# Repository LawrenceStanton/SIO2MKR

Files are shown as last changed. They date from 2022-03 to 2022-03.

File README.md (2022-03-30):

# SIO2MKR
Adjustable USB Powered Split Rail Power Supply for Breadboard Prototyping.

## Overview
This PCB design details a device to power an electronics breadboard for non-soldered prototyping. The project was commissioned by the University of Cape Town to allow students to work on electronics practicals from home. The device is powered off a standard 5V micro USB adapter, such as most cellphone adapters, and produces two independently adjustable positive and negatice supplies.

## Features
The device is controlled by:
1. A slide power switch.
2. 2 potentiometers for voltage adjustment.

The device has 1 input: 5V power from a suitable 5W USB power adapter.
The input is protected by a 3A Slow-Blow fuse, and is switched via a PMOS transistor controlled by the power switch.

The device has 4 outputs:
1. Adjustable Positive Voltage.
2. Adjustable Negative Voltage.
3. 5V USB Passthrough.
4. Non-isolated Ground.

The voltage is adjustable from ±1.2V to ±10.5V at a current rating of 40mA (at peak voltage output). Higher currents, up to 100mA, may be achieved at lower voltage. Current set resistors limit the power draw from the USB adapter to 1A, however if additional current is drawn from the USB passthrough is not accounted for. Ground is non-isolated, meaning it is the shared with the USB adapter.

## Contents
The repository has 4 sections:
1. FAB: Contains the PCB fabrication Gerber and drill files.
2. PCBA (JLCPCB SMT Assembly): Pick & Place and BOM files for automated assembly of components.
3. PCBA (No Variations): Same as above but including components not to be assembled by JLCPCB.
4. SRC: Altium Designer source files (can be imported to KiCAD).

## Manufacture
The device may be manufactured and assembled by JLCPCB. The cost per board comes to around $11.00 (10 units).

## Design Description
This design features 2 parallel power conversion circuits, one for the positive rail and one for the negative rail, with very similar operation. The power follows the following path:
USB -> Fuse -> Switch -> Switch Mode Boost Converter -> Linear Regulator
                      -> Switch Mode Inverter -> Linear Regulator
### Fuse
The fuse is a simple 3.0A slow-blow fuse. This is a secondary protection feature, since the Switch Mode Converter and Linear Regulator both have current limiting capability. Note issue #2 below.

### Switch
The switch is in fact a P-MOSFET controlled by slide switch. Note the ESD issue below.

### Switch Mode Converter
The Switch Mode Controller is the MC34063 regulator from ON Semi. Other pin-compatible devices are available from Diodes Inc. The device is a simple controller with an integrated darlington transistor and current sensing capability. Both the boosting and inverting supplies use this controller, and the same peripheral components due to the similar circuit characteristics of boosting and inverting switch mode supplies.

The inductor is rated at a high current value (0.95A) to improve efficiency. A large 400µF Tantalum Capacitor bank is supplied to stabilise the output, but may be increased without bound for improved performance.

The SS34 Schottky diodes are over specified but are generally quite cheap and this eliminates a commonly experienced failure mode. The positive supply features an inrush diode — which charges the capacitor bank to 5V immediately by bypassing the inductor. This should improve the startup performance of the positive supply, however this advantage is not possible with the inverting supply.

The timing capacitors set the switching frequency of the supply. These values are a bit dependent on biasing effects and should be measured in prototyping for exact specifications.

### Linear Regulator
The linear regulator is the universal LM317L and LM337L positive/negative regulator pair.

The linear regulators produce a much more stable output than the switch mode supply, necessary for analogue circuits. The devices are adjustable using the standard 1.25V reference feedback. A 2.7kΩ resistor in parallel with the 5kΩ potentiometer results in a roughly linear adjustment of the operational range of the switch mode supply.

### Tracking Pre-Regulator Feedback
The switch mode supply is configured as a tracking pre-regulator via the feedback network from the linear regulator’s output. The tracking voltage is set to 3V to adequately accommodate the dropout voltage of the LM317L and LM337L and to stiffen the regulator, while maintaining good power efficiency. The 5.6kΩ feedback resistors reduce the gain of the feedback, which should ensure stability, however this is still to be verified in testing.

### LED Indicators
3 LEDs are supplied to indicate USB power, the positive rail and the negative rail. The USB indicator is simple. To improve power efficiency, the split rail indicators are switched on 5V power by sensing the voltage across the 240Ω linear regulator's feedback resistor. This method relies on the gate threshold voltage of the sensing MOSFET, which is not absolutely certain to turn on fully but should be enough to fully turn on the 5V side MOSFET.

## Known Issues
### 1. Computer USB Power
The USB standard specifies that only 100mA may be drawn initially before power negotiation, and thereafter the device is only obliged to supply 500mA. This device does not communicate with its source at all. The power limit may be lowered by changing the 1206 current sense resistors (note under Features), however the initial surge is not yet tested. Powering the device from a PC USB port is therefore not advised, rather use a 5W or greater cellphone charger.
### 2. Fuse Rating
The fuse is rated at 3A, which is quite large. This is due to supply issues, and a 1.0A-2.0A rated fuse is more desirable. The part may be replaced with another 1206 Slow-Blow fuse.
### 3. Capacitor Discharge
Discharging the sizeable 800µF capacitor bank when switched off is not explicitly designed, however this is a low voltage bank and is not considered a safety risk.
### 4. ESD Protection
No ESD protection is provided. The most vulnerable component is the power PMOS transistor. Problems are to be tested with the initial prototype.
### 5. Tracking Pre-Regulator Stability
The tracking pre-regulator feedback network presents the possibility of destabilising the system. Although this can be simulated or otherwise modelled, the tolerances of the components are quite large and the exercise involved modelling the MC34063. Instead then, this will be stress tested during prototyping.

## Disclaimer
Please note the disclaimers detailed within the design files. The author assumes no liability in the use of this device, nor guarantees any of its function or availability.

© LD Stanton 2021-2022

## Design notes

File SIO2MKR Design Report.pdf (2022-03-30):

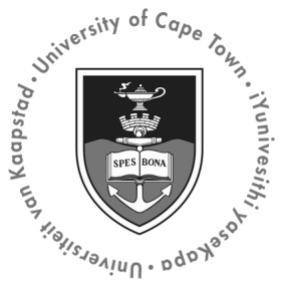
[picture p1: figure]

© LD Stanton 2022

University of Cape Town
Department of Electrical Engineering

Menzies Building, Upper Campus
Cape Town, South Africa
7701

## Design Report

July 2021 — Revised March 2022

LD Stanton
Postgraduate Student
STNLAW003@myuct.ac.za

# SIO2MKR USB Split Rail Power Supply

## Abstract

The SIO2MKR power supply regulates 5V USB power input into independently adjustable regulated split rail DC outputs. The design implements a tracking pre-regulator to maximise power output, while maintaining suitable ripple performance for low-speed analogue electronic loads. The design is intended for applications such as home analogue electronics with limited resources, low power demands, low user expertise, and low cost / high volume production.

This design was commissioned by the University of Cape Town and is made available publicly as Open Hardware under the CERN Open Hardware Licence v2 Permissive.

## Design Resources

Resource | Location
Open Hardware Repository | GitHub
Datasheet | Under Work
PCB Project | Altium 365
Schematic | Appendix A
Gerber Files | Altium 365
Fabrication Drawing | Appendix B
Assembly Drawing | Appendix C
Bill of Materials | Appendix D

## Features

- 5V USB Power Input

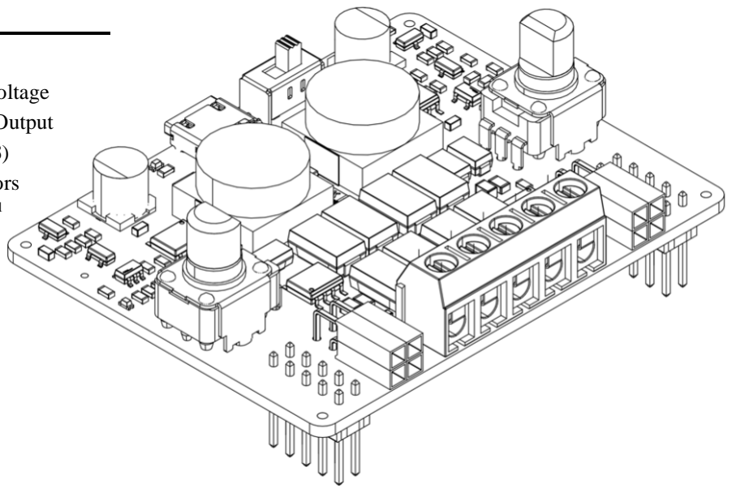
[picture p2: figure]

- Independently Adjustable Output Voltage
- ±1.25 to ±10.5V at 40mA (0.84W) Output
- Tracking Pre-Regulation (MC34063)
- LM317 and LM337 Linear Regulators
- 3 stage protection (2x ICs, 1x Fuse)¹
- Power Switch²

1 High Power 5V Output is only fuse protected.

## Applications

- General Purpose Electronics Prototyping
- School and University Programmes
- Hobby Electronics
- Electronics Development Programmes

## Additional Resources

Resource | Location
MC34063 Datasheet | ON Semiconductor
LM317 Datasheet | ON Semiconductor
LM337 Datasheet | Texas instruments
PCB Specifications | JLCPCB
Voltage Divider Script | Appendix E
CERN OHL v2 P | CERN, (https://ohwr.org/cern_ohl_p_v2.pdf) Appendix F

2 Switch controlled MOSFET.

System Description | 5.1 Inverting Regulator

## Table of Contents

1 SYSTEM DESCRIPTION --------------------------------------------------------------------------------------------------------------- 1

2 DESIGN SPECIFICATIONS------------------------------------------------------------------------------------------------------------ 1

3 FUNCTIONAL DIAGRAM ------------------------------------------------------------------------------------------------------------- 2

4 COMPONENT SELECTION CRITERIA ---------------------------------------------------------------------------------------------- 3

5 DESIGN CALCULATIONS------------------------------------------------------------------------------------------------------------- 4

6 TEST RESULTS -----------------------------------------------------------------------------------------------------------------------22

APPENDIX A — SCHEMATIC ----------------------------------------------------------------------------------------------------------------I

APPENDIX D — BILL OF MATERIALS --------------------------------------------------------------------------------------------------- II

APPENDIX E — E12 VOLTAGE DIVIDER SCRIPT ------------------------------------------------------------------------------------ IV

APPENDIX F — CERN OHL V2 PERMISSIVE LICENCE ---------------------------------------------------------------------------- VI

5.1 Inverting Regulator | System Description
Page 2 | LD Stanton

## List of Figures

FIGURE 1:FUNCTIONAL DIAGRAM | 2
FIGURE 2:FORCED GAIN CONDITIONS | 10
FIGURE 3: LINEAR REGULATOR SCALING RESISTOR VALUE SELECTION | 14
FIGURE 4: LMV321 CLAW | 15
FIGURE 6:POSITIVE SIDE VOLTAGE TRACKING | 25
FIGURE 7: NEGATIVE SIDE VOLTAGE TRACKING | 25
FIGURE 8: ADJUSTABLE CURRENT LOAD | 26
FIGURE 9:POSITIVE SIDE STEP UP TRANSIENT RESPONSE | 27
FIGURE 10: NEGATIVE SIDE STEP UP TRANSIENT RESPONSE | 28
FIGURE 11:POSITIVE SIDE STEP DOWN TRANSIENT RESPONSE | 28
FIGURE 12: NEGATIVE SIDE STEP DOWN TRANSIENT RESPONSE | 29

## List of Tables

TABLE 1: DUT INFORMATION | 22
TABLE 2: TEST EQUIPMENT | 22
TABLE 3:SUPPLEMENTAL INFORMATION | 29

## List of Circuits

CIRCUIT 1: INVERTING REGULATOR | 4
CIRCUIT 2: BOOSTING REGULATOR | 7
CIRCUIT 3: DARLINGTON FORCED GAIN CIRCUIT | 9
CIRCUIT 4: TRACKING FEEDBACK CIRCUIT | 11
CIRCUIT 5: LINEAR REGULATOR FEEDBACK NETWORK | 13
CIRCUIT 6: LMV321FUNCTIONAL CIRCUIT DIAGRAM | 16
CIRCUIT 7: NEGATIVE RAIL LED INDICATOR HYSTERESIS CIRCUIT | 17
CIRCUIT 8:POSITIVE RAIL LED INDICATOR HYSTERESIS CIRCUIT | 19

System Description

SIO2MKR Design Report | Page 1

## 1 System Description

This design implements a parallel boosting and inverting switching regulator, both utilising the MC34063 — a ubiquitous, low cost and robust power converter. Each switched output is then passed through the LM317 (positive) and LM337 (negative) adjustable linear regulators to eliminate switching noise. The regulators are adjusted using two potentiometers, compensated for linearity over the range of operation. A feedback network implements 3V tracking pre-regulation between the switched and linearly regulated outputs, similar to many “hybrid” DC bench power supplies. In conjunction with a generous 400μF tantalum capacitor bank (per rail); this configuration results in an output voltage ripple suitable for most low-speed analogue electronics projects and experiments.

## 2 Design Specifications

Symbol | Name | Value
| | Minimum | Typical | Maximum
VI | DC Input Voltage | 4.6V | 5.0V | 5.5V
PI | Input Power | 5W
VO | Output Voltage Range (Each Rail) | ±1.2V | | ±10V5
IO | Rated Output Current (Rail to Rail) | | | 40mA
IO_PP | Rated Output Current (Positive Rail to Ground) | | | 60mA
IO_PP | Rated Output Current (Ground to Negative Rail) | | | 40mA
VR | Ripple Voltage (Switching Regulator) | | | 50mVpp
VTRACK | Pre-regulator Tracking Voltage | | 3.0V
VSR_PP | Boosting Regulator Output Range | VI | | 13V75
VSR_NN | Inverting Regulator Output Range | 0V | | -13V75
fSR | Switching Frequency | 24kHz | 33kHz | 42kHz
IL_pk | Peak Switching Current (Per Regulator) | | 0A44
VLED_ON | LED Indicator ON Threshold | | ±5V
VLED_OFF | LED Indicator OFF Threshold | | ±1V5
IFUSE_USB | Input Non-resettable Fuse Rated Current | | 3A
IFUSE_PTC | Output PTC Fuse Rated Current | | 460mA

## 3 Functional Diagram

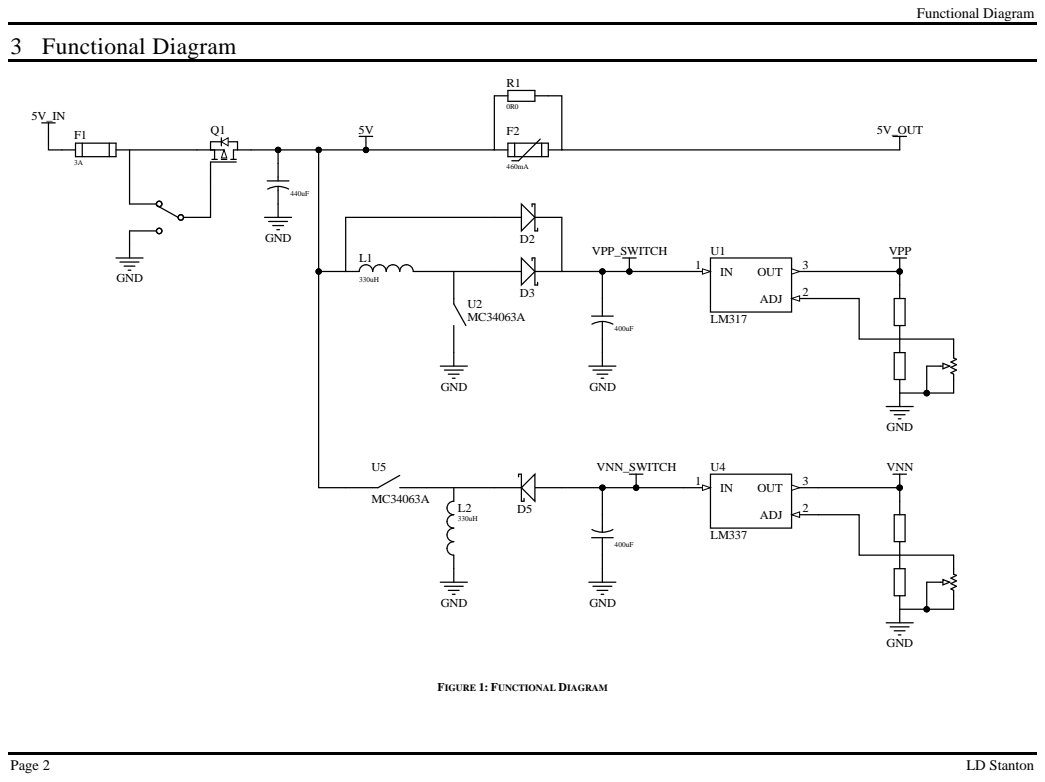
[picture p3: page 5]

Component Selection Criteria

SIO2MKR Design Report | Page 3

## 4 Component Selection Criteria

The selection process for each component is not detailed, however in general the following criteria were applied in decreasing order of priority:

1. Any directly-applicable, fixed specifications.
2. Available via JLCPCB SMT Assembly (limited subrange LCSC.com)
3. Active Part, Stock & Availability (150 Units Minimum at time of selection)³
4. Basic Part (JLCPCB SMT Assembly designation)
5. Performance & Features
6. Component Package
7. Cost (100 to 1000 units)
8. Component-specific comparisons, RoHS, manufacturer & other terminal criteria.

3 Due to the 2021 global chip shortage, this criterion was significantly increased in priority than normal.

5.1 Inverting Regulator | Design Calculations

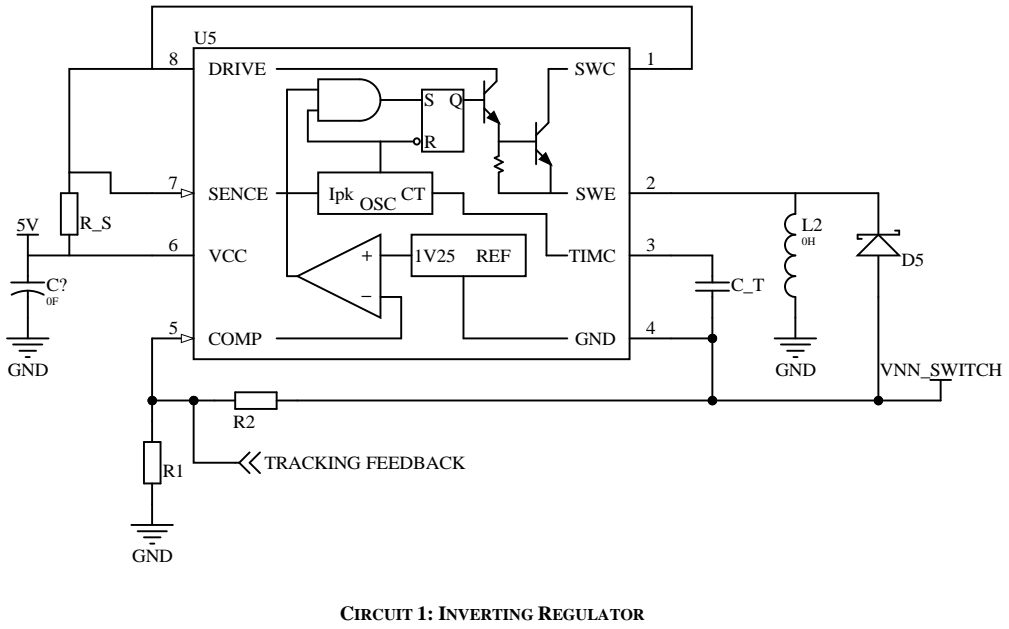
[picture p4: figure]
CIRCUIT 1: INVERTING REGULATOR; SWC; SWE; TIMC; GND; COMP 5; VCC 6; SENCE 7; DRIVE 8; OSC Ipk; REF; TRACKING FEEDBACK; VNN_SWITCH

Page 4 | LD Stanton

## 5 Design Calculations

Where an equation or symbol is quoted without reference to the visible circuitry, the source is to be assumed to be the datasheet of the relevant component.

## 5.1 Inverting Regulator

## 5.1.1 Feedback Voltage Divider

Note: this voltage divider effectively limits the maximum output, given no feedback from the tracking feedback path. Additionally, the common node of the MC34063 is referenced to the negative output rail. The 1V25 reference voltage is therefore situated as 1V25 above VNN, NOT 1V25 below GND.

Let VO_MAX = -14V

VO = VFB

R1 + R2
R1
- VFB = -1V25

From the above, the script in Appendix E resolved the following values:

- R1 = 5K6
- R2 = 56K

Rated VO_MAX = -13V75.

Design Calculations | 5.1 Inverting Regulator
SIO2MKR Design Report | Page 5

## 5.1.2 Switching Times

T = ton + toff =

1
f

,

ton

toff

=

|VO| + VF

Vin − Vsat

, ton =

T

1 +

1
ton/toff
- VO = 13V75
- VF_MAX = 0V55 (SS34 SBR)
- Vsat = (1V0 ; 1V3) — Darlington
- Vin = (4V6 ; 5V25) — USB Specification
- f = (24 ; 42) kHz — Typical Range

Due to the switch being above the inductor, a Darlington configuration was necessary.

Therefore:

- | TMAX = 41.7μs | TMIN = 23.8μs
- (ton/toff)MAX = 4.33
- (ton/toff)MIN = 3.24
- tON_MAX = 33.9μs
- tON_MIN = 18.2μs

## 5.1.3 Overcurrent Protection

ILpk =

Vtℎ
Rs
- Vth = 0V3

The inductor will be selected with overspecification on current handling to improve conduction losses. Therefore, the inductor rated current is not a consideration here.

The power supply is rated as a minimum of 5W = 5V × 1A. Neglecting all small loads, and assuming the worst-case scenario of both the inverter and booster switching on simultaneously at peak current, each regulator is permitted 1A/2 = 0.5A peak current. Therefore, set 0.5A as the current limit.

Given a more powerful input, this current limit can be increased by modifying RS within the rated limits of the inductor and MC34063, which will increase the output current capability.

∴ Rs =

0V3
0A5

= 0R6 ≈ 0R68

ILpk =

0V3
0R68 = 0A44

## 5.1.4 Output Current

IOMAX =

Ipk
2 ((
ton
toff)

MAX

+ 1)

=

0A44
2(4.33 + 1)

= 41mA

Therefore rate IORATED = 40mA

5.1 Inverting Regulator | Design Calculations
Page 6 | LD Stanton

## 5.1.5 Inductor Value

LMIN =

VinMIN − VsatMIN

ILpk

tonMAX =

4V6 − 1V0
0A44 33.9μs = 277μH ≈ 330μH

Note: Inductance value options are fairly limited on JLC.

Select: SWRB1207S-33MT

- L = 330μH
- IR = 0A95

Current handling capability was over specified to reduce inductor resistance, within a reasonable footprint size. Height was unlimited.

## 5.1.6 Output Capacitance

CO =

9IOMAXtonMAX

Vripplepp

Specify Vripple = 50mVpp

∴ COMIN =

9 × 46.6mA × 32.9μs
50mV | = 276μF ≈ 3 × 100μF

1 additional capacitor was later added given available board area.

Select: 293D107X9016D2TE3

- Tantalum Electrolytic
- 100μF
- 16V

Tantalum capacitors were selected for their superior performance at higher voltage operation than MLCCs (DC bias effect), the fixed polarity of the rails, the required capacitance, and the available board area. 16V was sufficient assuming nominal operation of the MC36063 feedback divider with 2V headroom for overshoot.

## 5.1.7 Timing Capacitor

CT = 4.0 × 10⁻⁵Fs

−1 × tonMAX = 4.0 × 10⁻⁵Fs

| −1 × 32.9μs = 1.32nF ≈ 1nF

Rate at 16V (same as output capacitor).

This is not a critical component in value.

## 5.1.8 Input Capacitor

Assign 2x220μF AlEl Capacitors at 10V.

This is not a critical value in capacitance.

Although placing this component after the current sensing resistor may improve the maximum power capability of the device, this may result in triggering an overcurrent event on startup. Therefore, place these capacitors before the current sense resistor.

Design Calculations | 5.2 Boosting Regulator

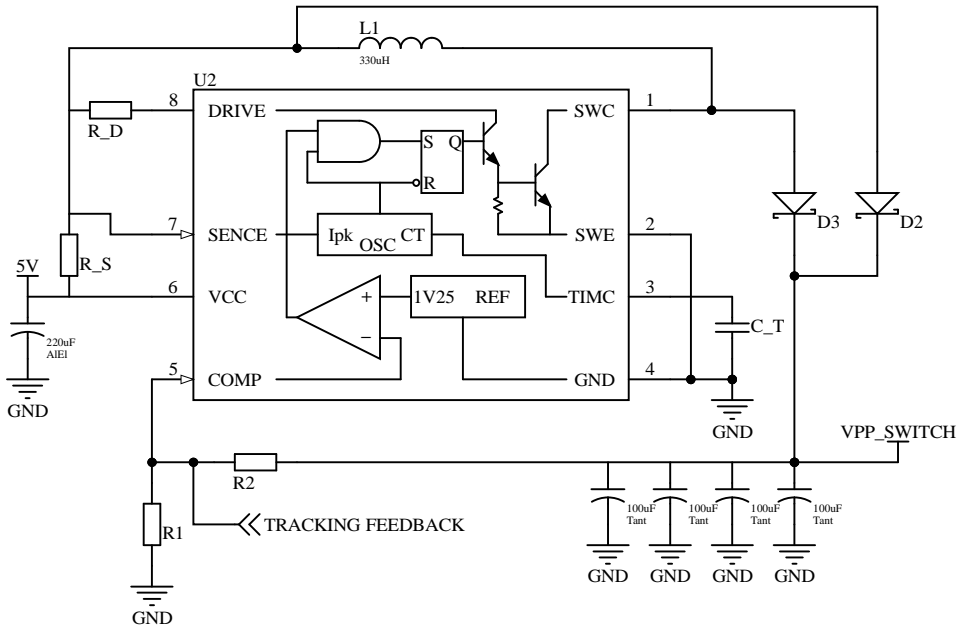
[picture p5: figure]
SWC; SWE; TIMC; GND; COMP 5; VCC 6; SENCE 7; DRIVE 8; OSC Ipk; REF; TRACKING FEEDBACK; VPP_SWITCH; 100uF Tant; 220uF AlEl

SIO2MKR Design Report | Page 7

## 5.2 Boosting Regulator

Much of this design is identical to the inverting regulator. For brevity, where the same design equation applied to both the inverting and boosting regulator, the result achieved in the inverter is simply replicated upon the booster.

CIRCUIT 2: BOOSTING REGULATOR

## 5.2.1 Feedback Voltage Divider

This circuit matches exactly the same feedback reference voltage to the same (inverted) maximum output. However, the reference is 1V25 above ground, not 1V25 below the output rail. Therefore, the values are swapped in position.

- R1 = 56K
- R2 = 5K6

## 5.2.2 Switching Times

T = tON + tOFF =

1
f

,

ton

toff

=

VO + VF − VINMIN

VINMIN − VsatMAX

,ton =

T

1 +

1
ton/toff
- VO = 13V75
- VF = 0V55 (SS34)
- Vsat = (0V45; 0V7) (Non-Darlington Configuration)
- f = (24; 42)kHz

ton

toff

=

13V75 + 0V55 − 4V6
4V6 − 0V7

= 2.48

tonMAX =

TMAX

1 +

1
(

tON
tOFF

)

=

1
24kHz (1 +

1
2.48)

= 29.7μs

5.2 Boosting Regulator | Design Calculations
Page 8 | LD Stanton

tonMIN =

TMIN

1 +

1
(

tON
tOFF

)

=

1
24kHz (1 +

1
2.48)

= 17.0μs

## 5.2.3 Overcurrent Protection

Same as Inverter:

- RS = 0R68
- Ipk = 0A44

## 5.2.4 Output Current

IOMAX =

Ipk
2(

tON
tOFF

+1)

=

0A44
2(2.48+1)

=63mA

Since it is plausible that current sourced from VPP will also need to be sunk by VNN, rate both supplies at the more constrained rating of VNN, 40mA. However, for single supply operation, rate:

IOPPRATED

= 60mA

## 5.2.5 Inductor Value

LMIN =

VINMIN − VsatMIN

Ipk

tONMAX =

4V6 − 0V4
0A44 29.7μs = 283μH < 330μH

Therefore, in the interest of parts management, select the same inductor as the inverter.

## 5.2.6 Output Capacitance

These characteristics are identical to that of the inductor, and therefore the same bank of 4x100μF capacitors were used, spare for changing the polarity of the connection.

## 5.2.7 Timing Capacitor

CT = 1nF (Same as inverter)

Design Calculations | 5.2 Boosting Regulator

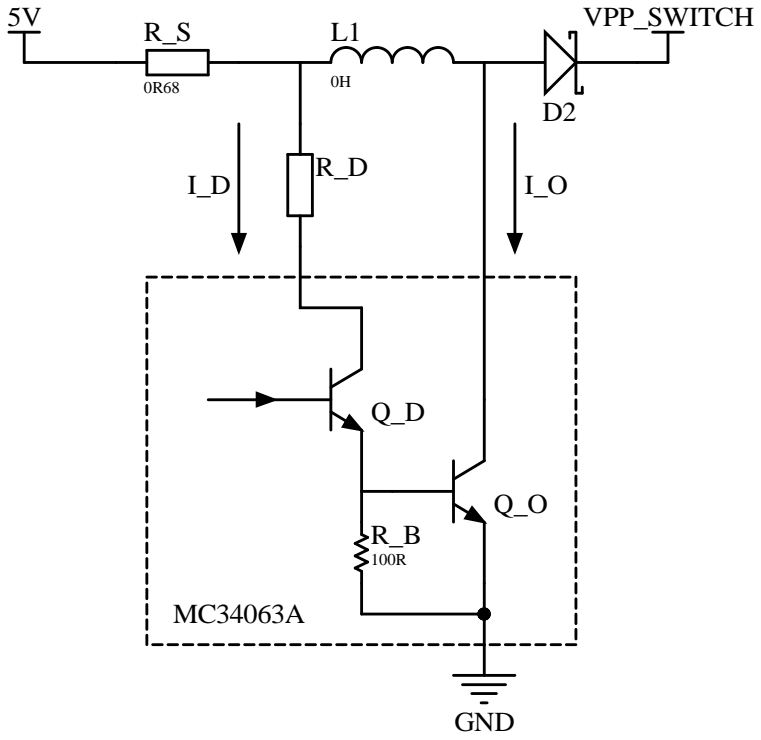
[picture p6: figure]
GND; VPP_SWITCH

SIO2MKR Design Report | Page 9

## 5.2.8 Forced Gain

It is recommended that:

ICOTP
ICDRIVER − 7mA ≥ 10

This is interpreted as the power transistor within the Darlington transistor should not be forced to a gain less than 10. This specifically refers to the turn-off transition, where excessive overdrive will delay turn-off, thereby increasing the tOFF time with an initial low collector current (<300mA), which is problematic at higher switching frequencies (>30kHz).

From the circuit diagram the following derivation follows:

CIRCUIT 3: DARLINGTON FORCED GAIN CIRCUIT

ICD =

VCC − VS − VCEOsat

− VBEO
RD

=

VCC − (ICO + ICD

)RS − VCEOsat
− 7mA × RB
RD

(ICO + ICD

)RS + RDICD + RB7mA = VCC − VCEOsat

ICO

RS + ICD

(RD + RS

) + 7mARB = VCC − VCEOsat

ICO

RS + (ICD − 7mA )(RD + RS
) + 7mA(RD + RS

) + 7mARB = VCC − VCEOsat

ICO

RS + (ICD − 7mA )(RD + RS
) + 7mA(RB + RD + RS

) = VCC − VCEOsat

By rearrangement, the gain condition is revealed, and the limitation applied:

ICO
ICD − 7mA =

1
RS

(
VCC − VCEOsat
ICD − 7mA − (RD + RS

) −

7mA
IO

(RB + RD + RS

)) ≥ 10

In the gain condition, the approximation IED = ICD + IBD ≈ ICD is implicit.

B

5.2 Boosting Regulator | Design Calculations

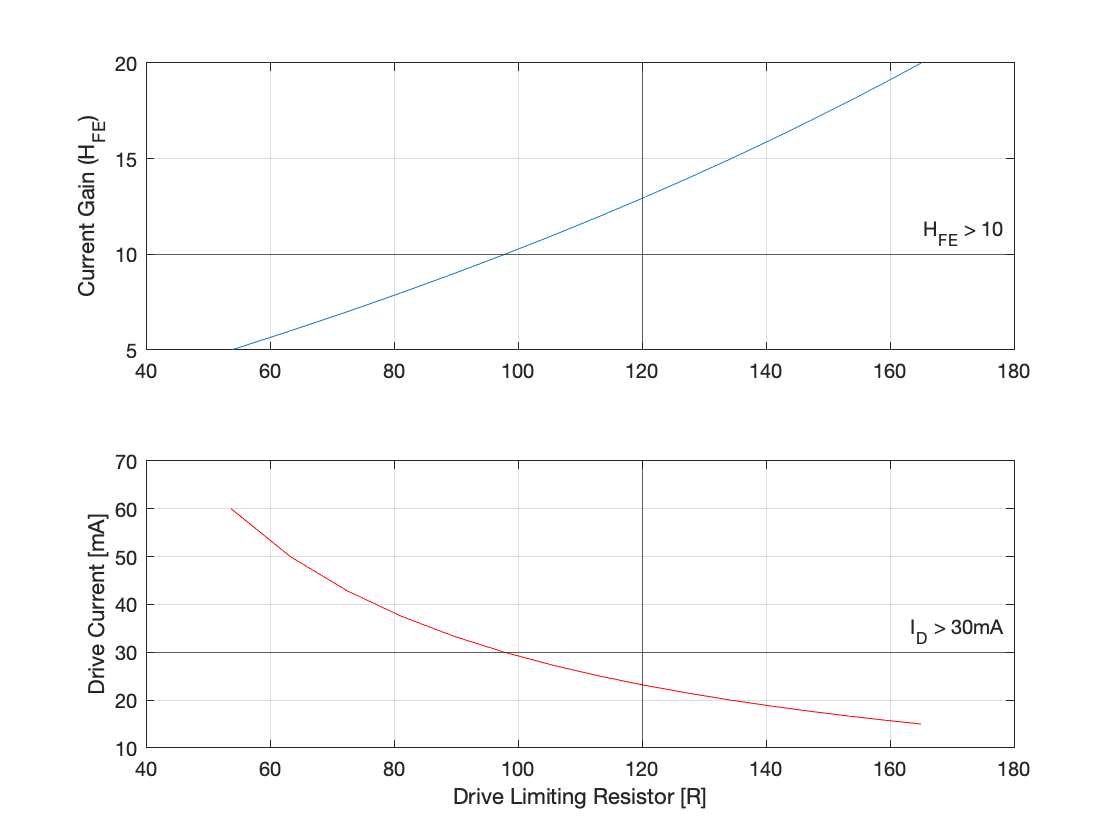
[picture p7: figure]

Page 10 | LD Stanton
Therefore | ICO ICD −7mA
= HFE:

1
RS

(
VCC − VCEOsat
ICD − 7mA − (RD + RS

) −

7mA

ICO

(RB + RD + RS

)) = HFE

By rearrangement:

RD =

(VCC − VCEOsat) HFE − IORS
(HFE + 1) − 7mA ∙ HFE(RB + RS

)
ICO + 7mA ∙ HFE

The transistor saturation effects are most relevant at higher output collector currents (300mA), since this corresponds to a more active condition (as opposed to an inactive, non-conducting condition). Additionally, the saturation voltage of the drive transistor is unspecified, but is significant in the above result relative to VCC (5V) and is therefore approximated to be equal to the power transistor forced gain saturation voltage (0.45V). In summary:

- VCC = 5V
- VCE_D(sat) = 0.45V
- IC_O = 0.300A
•

Given these conditions, with all other values specified, by computing the required drive resistor for a range of possible DC current gains, along with the corresponding drive current, the following figure is produced:

FIGURE 2: FORCED GAIN CONDITIONS
From this, it is observed that:
- The Drive Current is an approximately inversely proportional function of the Drive Limiting Resistance.

Design Calculations | 5.3 Tracking Feedback

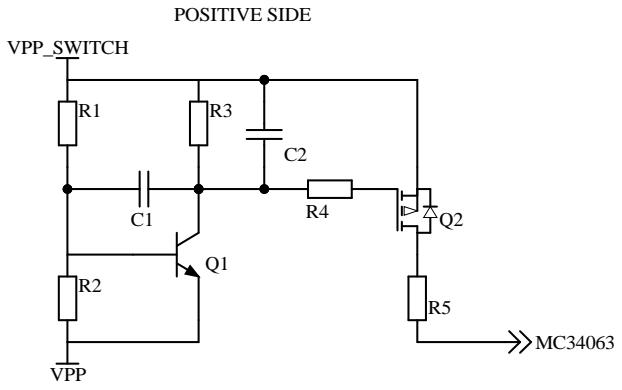
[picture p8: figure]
VPP; VPP_SWITCH; POSITIVE SIDE
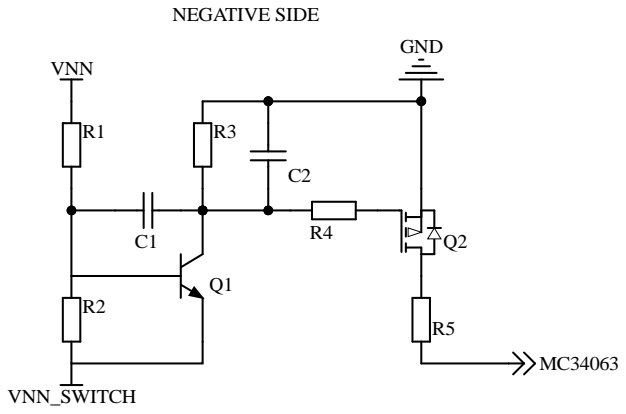
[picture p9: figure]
VNN_SWITCH; VNN; NEGATIVE SIDE; GND

SIO2MKR Design Report | Page 11
- Due to the fixed output current condition, the Darlington DC current is inversely proportional to the Drive Current, the therefore approximately directly proportional to the Drive Limiting Resistance.

This reaffirms the intuitive function of the drive current limiting resistor and shows that the effects of the current sense resistor are limited.

Although the drive input could be connected directly to the 5V source, this tampers with the current limiting function of the MC34063 as 23mA is significant.

It is therefore observed that the minimum E12 resistor value that satisfies the recommended conditions is 120R.

- HFE = 13
- ID = 23mA

## 5.3 Tracking Feedback

The LM317 and LM337 both require a maximum of 2V5 dropout.

Therefore, specify tracking voltage at 3V0 4V0.

The original 3V0 specification was revised to 4V0 following test results, as explained in §6.2.5.

CIRCUIT 4: TRACKING FEEDBACK CIRCUIT

C

B

A

5.3 Tracking Feedback | Design Calculations
Page 12 | LD Stanton

Circuit Operation

This circuit exploits the base emitter voltage of the BJT to be an approximate reference or “trigger” voltage. Below the trigger voltage, the BJT is non-conductive. Above the trigger, the BJT conducts. R1 and R2 then voltage divide the switching to linear regulator voltages to control the base voltage. The effects of base current are neglected.

The conduction from the BJT is used to trigger a P-MOSFET. R3 generates the gate voltage and is set to a sufficient value to produce the gate threshold voltage at negligible base current. It was not necessary to implement a voltage divider with R3 due to the sufficient rating of the MOSFET gate insulation. R4 protects the gate of the MOSFET from the numerous endpoints of the preceding net.

Capacitors C1 and C2 are added to allow for dampening. C1 exploits the Miller effect to filter high frequency feedback components. C2 simply slews the transition of Q2 into and out of conduction.

The output current is fed into the switching regulator feedback node (see Circuit 1and Circuit 2). In effect, once the tracking circuit triggers, the feedback node is injected with more current, which raises the feedback voltage, which appears as an increase in output voltage to the MC34063, causing the switching regulator to reduce the output voltage until the tracking circuit reaches some equilibrium with approximately 3V of tracking. R5 reduces the control authority of the tracking feedback path relative to the fixed voltage feedback path, essentially reducing the gain of the feedback path. By setting the two feedback resistors as equal, at full conduction of Q2 the feedback at most will imitate double the true switching regulator output voltage. If this were due to component failure, this would produce a fault condition of approximately ±5V output.

Due to the similar configuration of the MC34063 in the inverter and the booster converters, the same tracking feedback circuit is possible in both regulators. The only difference is the power source for the feedback current.

## 5.3.1 Component Selection

The SS8050 and LBSS84LT1G were arbitrarily selected as basic parts with sufficient operational ratings for this task.

The BJT, under these conditions, specifies:

- VBE = 0V7
- hFE = (120 ; 400)

## 5.3.2 Trigger Voltage Divider

For the 3V0 tracking and VBE = 0V7, the script in Appendix E resolved:

- R1 = 27K
- R2 = 8K2

## 5.3.3 Base Drive Current

ICMAX =

VSR − VLR − VCE(SAT)
R3

<

VSR − VLR
R3

IBMAX =

IC

ℎFE

≈

VSR − VLR

ℎFEMIN R3

IBIAS = IA =

VSR − VLR
R1 + R2

It is desirable to reduce the required base current to be a small fraction of the bias current to protect the assumption of neglecting the effects in bias current in setting the feedback trigger voltage divider. This can be achieved by increasing R3 but should be limited so that small current effects do not falsely enable the MOSFET. Heuristically, the base current was limited to be less that 5% of the bias current.

Design Calculations | 5.4 Linear Regulator

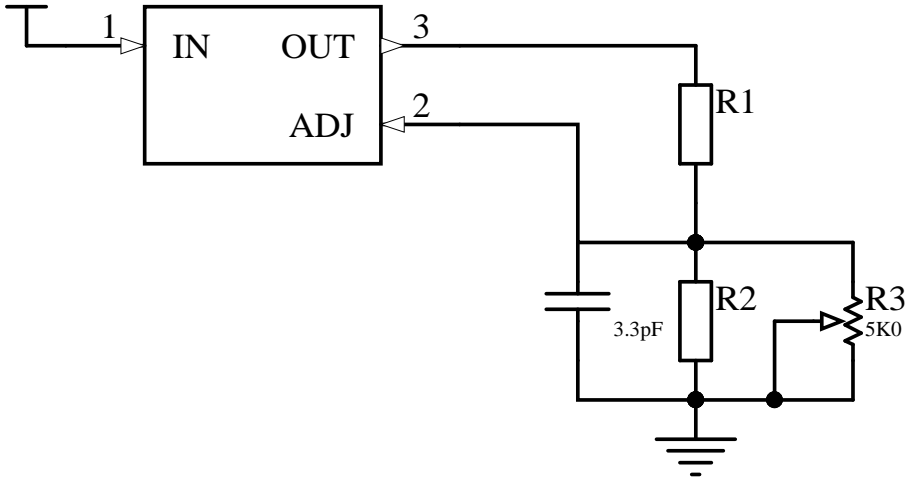
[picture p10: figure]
ADJ; OUT

SIO2MKR Design Report | Page 13

Given that:
(

IBMAX
IA

) =

R1 + R2

ℎFEMIN R3

Through iteration over E12 values from 10K increasing, 27K →

IBMAX
IA

= 4% < 5%.

## 5.4 Linear Regulator

The below applies to both the LM317 and LM337, which are functionally identical with regards to external components. These devices operate through the typical error amplifier with an internal reference voltage.

## 5.4.1 Voltage Adjustment

A 5K potentiometer was selected for user control.

CIRCUIT 5: LINEAR REGULATOR FEEDBACK NETWORK
The resistor to output uniquely determines the current through the feedback network at regulation.

Select R1 = 240R (Recommended Value for 5.2mA Feedback Current)

A higher value in R1 will produce a more linear radial response, however it is not advisable to deviate from the recommended value for this non-critical benefit.

R2 is introduced to limit the range of effect that R3 has to match the capable range of the switching regulator.

VO = VR

R2||R3 + R1
R1

+ IaR2||R3 (For Intransient Conditions)

The above relationship is plotted with various E12 values in R2. Per the below response, the following is observed:

2. Large values of R2 result in a more constant rate of change in Output Voltage with R3.
3. Large values of R2 result in the output saturating before full rotation.

Achieving a full range in output with largest possible resistor is therefore the critical limiting factor. Given that:

VOMAXLR

= VOMAXSR

− Vfollow = 13V75 − 3V0 = 10V75

## VIN

## GND

5.4 Linear Regulator | Design Calculations

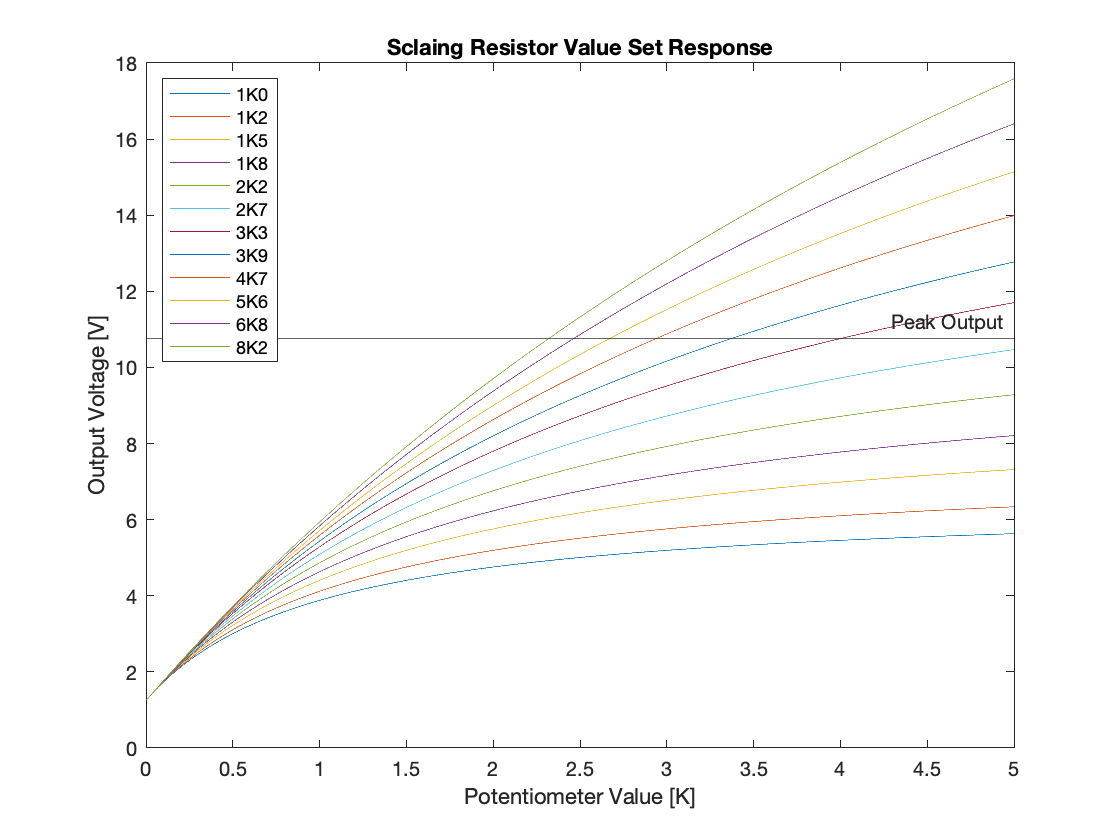
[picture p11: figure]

Page 14 | LD Stanton

Select R2 = 2K7 (VO_MAX = 10V47)

FIGURE 3: LINEAR REGULATOR SCALING RESISTOR VALUE SELECTION

## 5.4.2 Feedback Capacitor

A feedback capacitor is added to suppress any electromechanical transconductance due to the potentiometer.

Via the way of the Norton Equivalent circuit, with the potentiometer being the load:

IN =

VR
R1

= 5.4mA

RN =

R2
(R1 + R2) + sR1R2C

R1
VR

Therefore, a 3.3pF capacitor results in a -3dB bandwidth at approximately 20kHz, which should suppress most noise while retaining a nominal dynamic response for the typical device output loads.

## 5.4.3 Output Capacitor

Select 1uF 50V 0805 MLCC. This follows the typical application circuit.

## 5.4.4 Input Capacitor

A 100nF 50V 0805 MLCC is placed in case of any need for input capacitance but is not populated.

Design Calculations | 5.5 LED Indicators

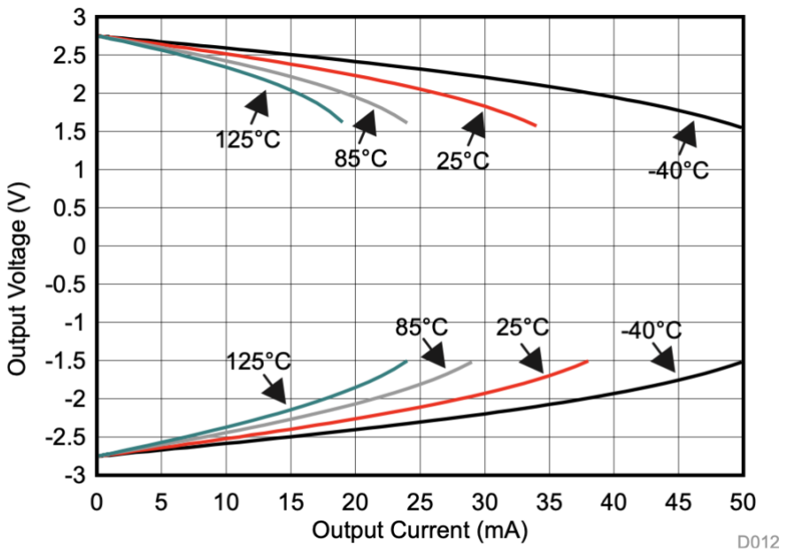
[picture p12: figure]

SIO2MKR Design Report | Page 15

## 5.5 LED Indicators

The LEDs are valuable user feedback indicators but represent a significant power draw. It would be wasteful to drive these LEDs directly off each output rail, and (with simple resistive current limiting) would result in variable brightness with voltage adjustment.

Therefore, effort must be made to activate LEDs using sensing circuitry that would source illumination current from the 5V input.

A prior circuit attempted to enable the LED based triggering a MOSFET using the linear regulator reference voltage. In Revision 2.0, this was a success on the positive rail, but failed on the negative rail, due to the different gate threshold voltages between the P and N MOSFETS needed on each rail. In order to avoid relying on this imprecise characteristic, a comparative circuit was specified.

## 5.5.1 LED Current

Select Greed LED: 19-217/GHC-YR1S2/3T

- VF = 3V3
- IMAX = 25mA

Set ILED = 5mA

RLED =

VCC − VF

ILED

=

5V0 − 3V3
5mA = 340R ≈ 330R

∴ ILED =

5V0 − 3V3
330R

= 5.15mA

Since all LEDs are driven off 5V, this remains a common series resistor value between all indicators.

## 5.5.2 Op-Amp Selection

Select Op-Amp: LMV321IDBVR

FIGURE 4: LMV321 CLAW
VCC = 5V5. Source: Texas Instruments

5.5 LED Indicators | Design Calculations

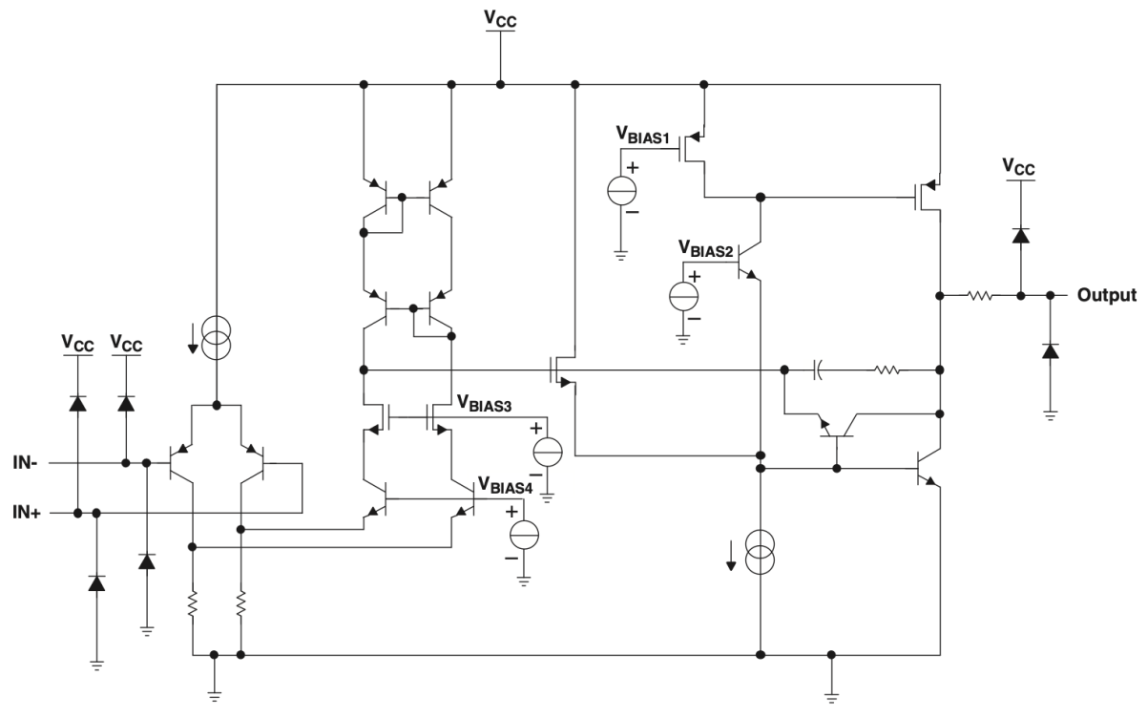
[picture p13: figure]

Page 16 | LD Stanton

CIRCUIT 6: LMV321 FUNCTIONAL CIRCUIT DIAGRAM
Source: Texas Instruments

This op-amp was selected predominantly for it’s SOT-23-5 package. The rail-to-rail operation is also beneficial, but only in terms of simplifying the mathematics to follow.

The following critical limitations of the LMV321 should be acknowledged:

1. VCC_MAX = 5V5
2. NOT short circuit to VCC protected.
3. VIO < 7mV
4. IIB < 250nA

From the above information, the following can be determined:

1. Operation off 5V is prescribed (as was intended).
2. The inputs must strictly remain within 0 to 5V.
3. The op-amp should source current, not sink, to the LED (both options are technically possible).
4. The input offset voltage need not be compensated for in trigger threshold definitions.
5. The input bias current is negligible for 10’s of K peripheral resistors.
6. At 5.15mA output current drive, ideal rail-to-rail performance can be approximated.

The derivations to follow assume the above.

Design Calculations | 5.5 LED Indicators

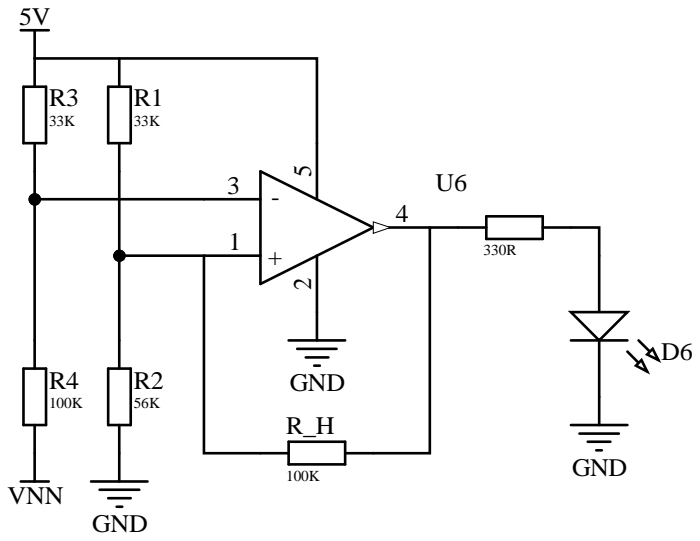
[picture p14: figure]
GND; VNN

SIO2MKR Design Report | Page 17

## 5.5.3 Negative Rail Indicator

CIRCUIT 7: NEGATIVE RAIL LED INDICATOR HYSTERESIS CIRCUIT
Circuit Description

This circuit achieves the following goals:

1. Op-amp operation off the 5V supply.
2. Reliable, precisely programable triggering levels and hysteresis window.
3. Cheap, compact components.
4. Direct LED drive off the op-amp output.
5. Negligible loading of the output rail.
6. Reliable restriction of V- to be above 0V.

The negative rail’s voltage is sensed relative to 5V through the voltage divider, which limits the sensed voltage to remain above 0V, given a minimum output voltage. This voltage is compared to a 5V referenced threshold. This threshold is programmed with hysteresis though the positive feedback resistor to correlate to a set of two possible threshold conditions, based on the state of the output.

The LMV321 is capable of driving the LED directly given the set 5.15mA drive current. Regardless, this device is indefinitely tolerant to short circuit conditions to ground.

Triggering Specifications

- VNN_ON = -5V (Nominal good-inversion threshold)
- VNN_OFF = -1V5 (Just above point of minimum regulation)

Circuit Equations

V− =

(5V − VNN)R4
R3 + R4

+ VNN

V+ =
{

5V

R2
R1||RH + R2

VO = HIGH (5V)

5V

R2||RH
R1 + R2||RH

V0 = LOW (0V)

Constraints

5.5 LED Indicators | Design Calculations
Page 18 | LD Stanton
1. V- > 0V
2. V+_LOW_TH → VNN = -5V
3. V+_HIGH_TH → VNN = -1V5

Sense Divider

∴ Let V− = 0V @ VNNMIN = −15V (−13V75 − 1V25 Margin)

This maximises the usable range within reasonable safety.

Using the script in Appendix E, the following values were resolved:

- R3 = 33K
- R4 = 100K

Upwards Crossing Threshold (VO Starts LOW)

- VNN = -5V

V− = (5V − (−5V))

100
133 + (−5V) = 2V519 = V+LOW

∴ 2V519 = 5V

R2||RH
R1 + R2||RH

Downwards Crossing Threshold (VO Starts HIGH)

- VNN = -1V5

V− = (5V − (−1V5))

100
133 + (−1V5) = 3V387 = V+HIGH

∴ 3V387 = 5V

R2
R1||RH + R2

Simultaneous Equations

2V519
5V

=

R2||RH
R1 + R2||RH

=

R2RH
R1R2 + R1RH + R2RH

3V387
5V

=

R2
R1||RH + R2

=

R1RH + R2RH
R1R2 + R1RH + R2RH

Acknowledge the common denominator.

∴

2V519
3V387 =

R2RH
R1R2 + R2RH

=

RH
R1 + RH

Using the script in Appendix E, the following values were resolved:

- R1 = 33K
- RH = 100K

Back Substitution

3V387 = 5V

R2
R1||RH + R2

→ R2 = 52K10 ≈ 47K

(56K rounding results in rejected V+_HIGH result as was discovered during an iteration of Verification)

Design Calculations | 5.5 LED Indicators

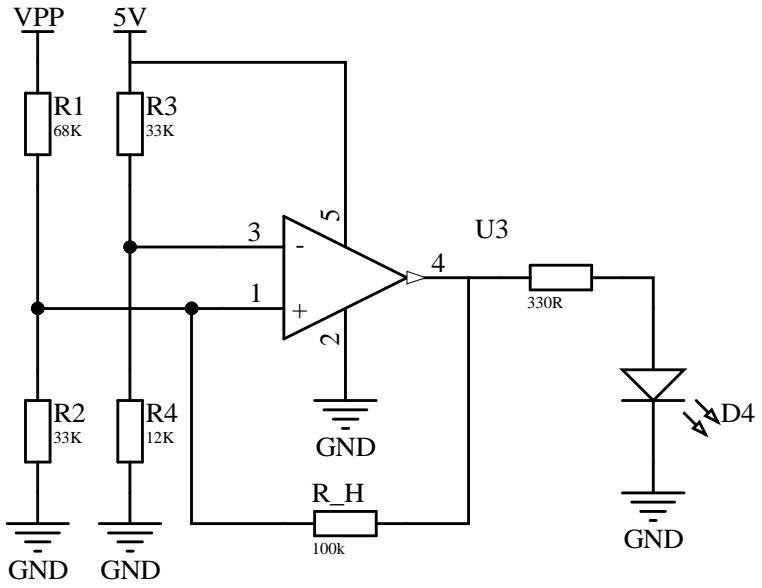
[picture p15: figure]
GND; VPP

SIO2MKR Design Report | Page 19

Verification

V+LOW = 5V

56K||100K
56K||100K + 33K

= 2V605 → VNN = −4V65

Result is accepted.

V+HIGH = 5V

56K
56K + 100K||33K

= 3V465 → VNN = −1V18

Note: This result is technically 20mV below the minimum output voltage of the LM337. However, due to the zero LMV312 headroom loss assumption, this result is an underestimate, and therefore it is expected that in reality the device will indeed trigger off.

The result is accepted.

Therefore, the overall circuit is accepted.

## 5.5.4 Positive Rail Indicator

CIRCUIT 8: POSITIVE RAIL LED INDICATOR HYSTERESIS CIRCUIT
Circuit Description

This circuit is functionally similar to Circuit 7, but with the following key differences:

1. Hysteresis is applied to the voltage-sensing divider, since the polarity of transitions are inverted relative to Circuit 7.
2. The negative input is set to a fixed value.

Unfortunately, this results in different — although similar — circuit derivations.

Triggering Specifications

- VPP_ON = 5V
- VPP_OFF = 1V5

Circuit Equations

5.5 LED Indicators | Design Calculations
Page 20 | LD Stanton

V− = 5V

R4
R3 + R4

V+ =
{

(

VPP
R1

+

5V
RH

) R1||R2
||R3 VO = HIGH (5V)
(

VPP
R1

)R1||R2
||R3 VO = LOW (0V)

Constraints

1. V+ < 5V
2. V+_LOW = V- @ VPP = 5V
3. V+_HIGH = V- @ VPP = 1V5

Sensing Divider

Let V+HIGH = 5V @ VPP = 15V (13V75 + 1V25 Margin)

∴ 5V0 = (

15V
R1

+

5V0
RH
)R1||R2 | ||R3 → 5V0 = 15V

R2
| R1 + R2

(RH is not conducting current)

Therefore, the script in Appendix E resolved the following values:

- R1 = 68K
- R2 = 33K

Upwards Crossing Threshold (VO is LOW)

V+LOWTH

=

5V0
R1

R1||R2

||R3 = V−

Downwards Crossing Threshold (VO is HIGH)

V+HIGHTH

= (

1V5
R1

+

5V0
RH

) R1||R2
||R3 = V−

Simultaneous Equations
(

1V5
R1

+

5V0
RH

)R1||R2
||R3 =

5V0
R1

R1||R2

||R3 → RH =

5V0
5V0 − 1V5

R1 = 97K ≈ 100K

Fixed Reference

V+LOWTH

=

5V0
R1

R1R2R3
R1R2 + R1R2 + R2RH

= 1V337

∴ 1V337 = 5V0

R4
R3 + R4

The script in Appendix E resolved:

- R3 = 33K
- R4 = 12K

Verification

Design Calculations | 5.5 LED Indicators
SIO2MKR Design Report | Page 21

1V337 =

VPP
68K

68K||33K||100K → VPP = 4V98

1V337 = (

VPP
68K

+

5V0
100K

) 68K||33K||100K → VPP = 1V58

Both results above are accepted, therefore the circuit overall is accepted.

6.1 Test Parameters | Test Results
Page 22 | LD Stanton

## 6 Test Results

## 6.1 Test Parameters

## 6.1.1 Default Testing Methods

Unless stated otherwise, all tests were —:

- conducted at uncontrolled room temperature.
- under uncontrolled but noncondensing humidity.
- conducted on a single board per test, which may be interchanged between different tests.

For the purposes of these tests, minimum voltage means the voltage closest to ground. i.e. the minimum arithmetic absolute.

## 6.1.2 Device Under Test

The tests were conducted on the following device and revision:

TABLE 1: DUT INFORMATION
Project | SIO2MKR
Project Revision | v3.0
Release Date | 5 August 2021
Manufacturer | JLCPCB
Manufacture Date | October 2021
Order No. | 2483764E_Y163-211019

## 6.1.3 Test Equipment

The following test equipment was used in performing these tests:

TABLE 2: TEST EQUIPMENT
Device | Model | Serial Number
Oscilloscope | Keysight EDUX1002G | CN57202104
DC Power Supply | Keysight E3630A | KR72911794
DC Power Supply | MCP M10-QD 3020 | 17120014
Battery Bank | Romoss Solo 5 | 1610017083
Multimeter | Fluke 175 | 41170073
Multimeter | Keysight U1232A | MY58210030
Note: All devices branded under HP or Agilent are stated here as Keysight.

## 6.2 Functional Tests

## 6.2.1 Power Switch

Test Description | Power is applied. The slide switch is moved to the on position and then back to the off.
Pass Criteria | The 5V LED must be on when the switch is on and off when the switch is off.
Test Result | PASS

## 6.2.2 Power LEDs

Test Description | The device is turned on with both potentiometers set to the minimum output. The voltage is then increased on both rails until the indicator LEDs toggle on. The voltage is then decreased until the LEDs toggle off (through the hysteresis band). These thresholds are measured.
Pass Criteria | Toggling within 10% ±0V2 of the design criteria: [-1V5, -5V0] and [1V5, 5V0]
Results | Side | On Threshold | Off Threshold
| Positive Side | 5V015 | 1V780
| Negative Side | -4V703 | -1V412
Test Result | PASS

Test Results | 6.2 Functional Tests

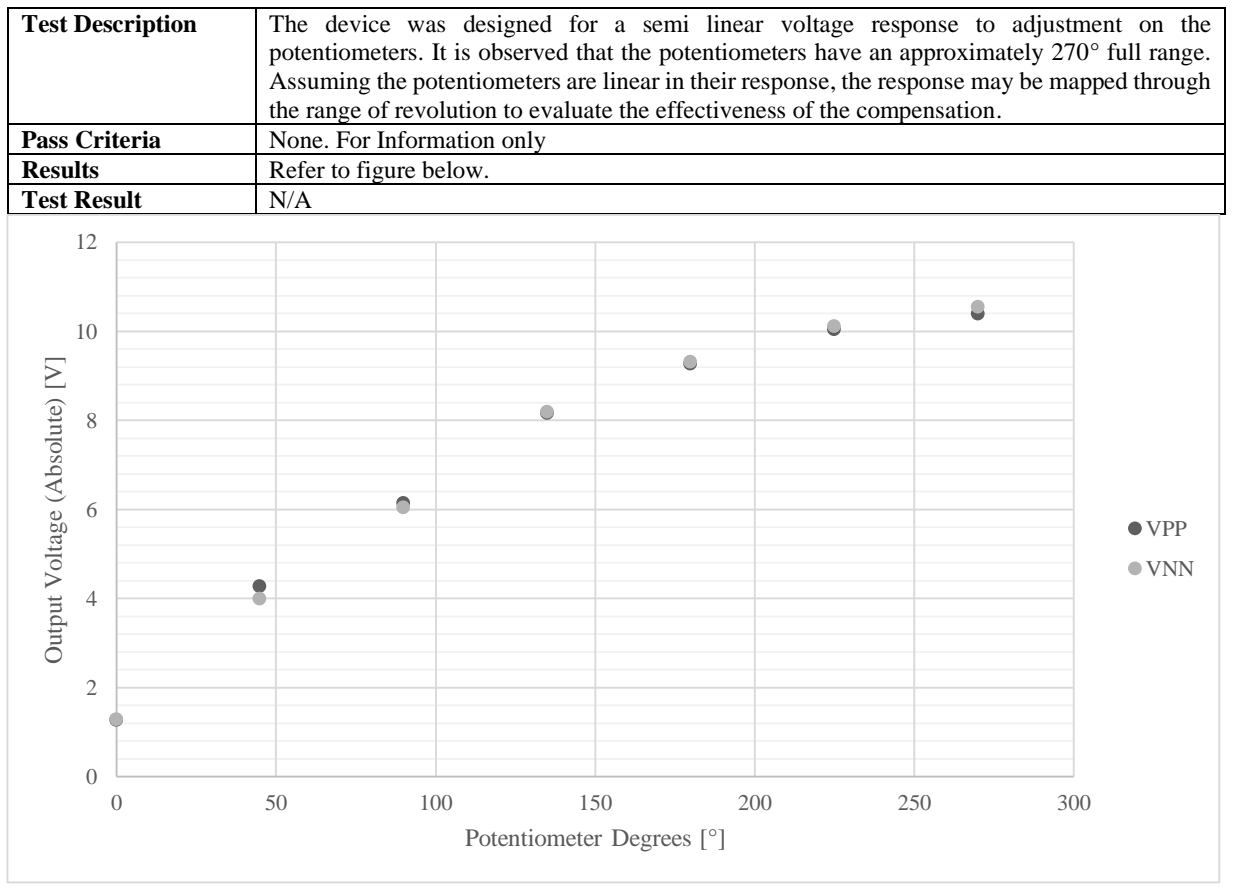
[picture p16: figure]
Pass Criteria; None. For Information only; Results; Refer to figure below.; Test Result; Output Voltage (Absolute) [V]; Potentiometer Degrees [°]; VPP; VNN

SIO2MKR Design Report | Page 23

## 6.2.3 Voltage Adjustment

Test Description | The device was designed for a semi linear voltage response to adjustment on the potentiometers. It is observed that the potentiometers have an approximately 270° full range. Assuming the potentiometers are linear in their response, the response may be mapped through the range of revolution to evaluate the effectiveness of the compensation.

## 6.2.4 Fuses

Test Description | With the 5V output shorted to GND, the PTC bypass jumper closed, and with power injected directly upon the input side of the fuse (with a soldered wire) — power is applied using the MCP M10 supply. With the power switch open, the voltage is set to 5V with the current limit set to 0A. The switch is closed. Thereafter, the current limit is removed and increased rapidly to approximately 6A.
Pass Criteria | The fuse must open.
Observations | The fuse did not blow. Instead, the MOSFET switch experienced intense heating, and proceeded to melt. The fuse began it heat, but de-soldered, releasing the injecting wire, and thereby ending the test. The test also melted some plastic pieces on connecting wires due to poor connector resistance. This test indicates that the fuse fails to protect at least one critical device, the power switch MOSFET, from heat destruction, and therefore the system is insufficiently protected.
Actions | The fuse must be replaced with a lower current alternative, recommended as 1-1.5A. Due to the typical contact resistances encountered in breadboard prototyping, there is no conceivable application that would require more than this this amount of current without causing destruction to the breadboard, as was observed, hence this recommended rating. This test should ideally be repeated with a new fuse rating.
Test Result | FAIL

6.2 Functional Tests | Test Results
Page 24 | LD Stanton
Test Description | The 5V output is connected to a 1R load to GND, the PTC bypass jumper is open, and normal power inputted via a 15W/5V USB supply. The true resistance (including connector resistance) is measured using a multimeter, compensated for the lead resistance. The power switch is closed, and the output voltage is measured. The input power supply is expected to regulate to a maximum of 3A output, and so the output voltage is expected to be below 5V, however if the PTC fuse opens, this will correspond to a further voltage drop some appreciable time after the switch was opened.
Pass Criteria | The fuse must open.
Measurements | True Load | 1R5
| Initial Output Voltage | 1V
| Steady State Output Voltage | 240mV

Observations

The output voltage briefly increased to approximately 1V, but within 2s decreased to 240mV. With the load impedance, this corresponds to an initial current of at least 660mA, in excess of the PTC fuse’s rating. This rapid decrease therefore corresponds to an upstream device increasing its impedance. With the only upstream devices being the 3A fuse, power switch MOSFET, USB connector and the input supply, which are all rated to conduct in excess of 3A, it is therefore assumed that the PTC was indeed responsible for this action. The steady state output voltage therefore corresponds to 160mA/38mW output, which is regarded as being a suitably safe value.
Test Result | PASS

## 6.2.5 Tracking Feedback

Test Description | The switching regulator output and linear regulator output voltages are monitored by an oscilloscope with a rolling acquisition. A mathematical function is also plotted for the difference between the two inputs. It is expected that the switching rail tracks the linear rail with a constant 3V differential, with a minimum limit of 5V in the case of the positive regulator. The output voltage is adjusted through the full range to demonstrate the tracking function. The test is repeated for both positive and negative sides.
Pass Criteria | Tracking Voltage > Maximum Dropout Voltage (2V5)
Results | See figure below.
Observations | The tracking feedback is functionally correct but fails to maintain the desired minimum tracking voltage, maintaining approximately 2V2 tracking voltage on both sides. Upon review of the calculations, it is believed that a combination of a lower-than-expected base-emitter voltage, and the expected base drive current drop was responsible.
Actions | The calculations were revised, given these measurements, in an identical manner upon the basis of a 4V0 tracking voltage. If whatever effects remain linear through this change, this basis is expected to produce the intended tracking voltage of 3V. This change should also improve the performance of the device.
Test Result | FAIL

Test Results | 6.2 Functional Tests

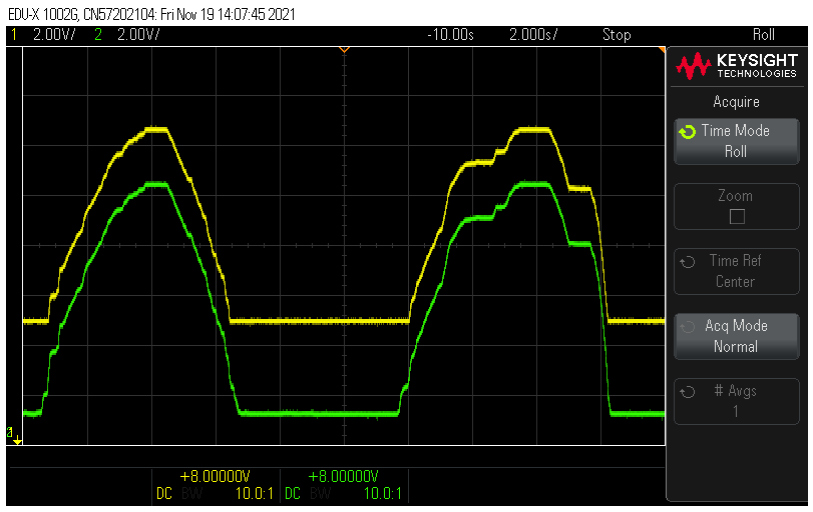
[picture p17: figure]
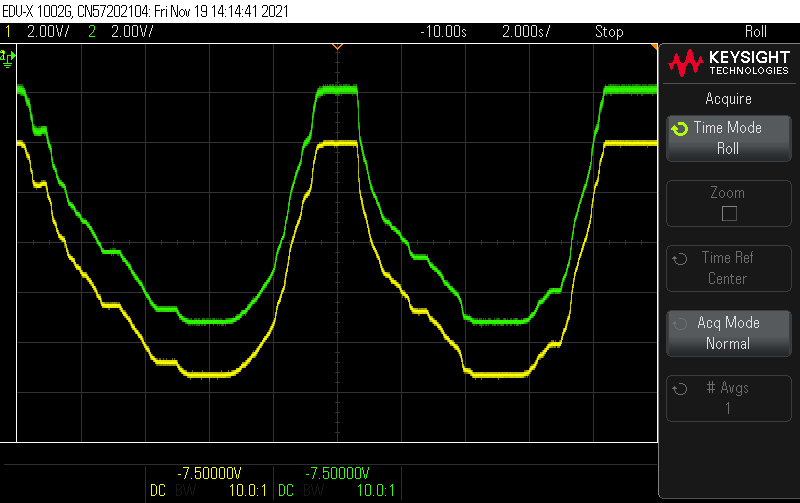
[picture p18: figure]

SIO2MKR Design Report | Page 25

FIGURE 5: POSITIVE SIDE VOLTAGE TRACKING
The voltage tracking feedback directs the boosting switching regulator output (yellow) to maintain a fixed voltage difference of approximately 3V from the linear regulator’s output (green). At 5V, the inrush diode holds the switching output at 5V.

FIGURE 6: NEGATIVE SIDE VOLTAGE TRACKING
Similar to the positive side; the voltage tracking feedback directs the inverting switching regulator output (yellow) to maintain a fixed voltage difference of approximately -3V from the linear regulator’s output (green). In this circuit there is no inrush diode, and so the voltage tracking is maintained throughout the range of output.

6.3 Static Characteristics | Test Results
Page 26 | LD Stanton

## 6.3 Static Characteristics

## 6.3.1 Output Range

Test Description | Measure the full range of output voltage at no load.
Pass Criteria | Output ranging over ±(1V2, 10V5)
Results | | Minimum | Maximum
| Positive Side | 1V264 | 10V48
| Negative Side | -1V298 | 10V63
Test Result | PASS

## 6.3.2 Peak Output Current and Power

Test Description | At no load output voltage of ±10V5, measure the -3dB voltage (7V42) load current using the circuit shown below.
Pass Criteria | -3dB Load Current > 40mA
Results | | -3dB Load Current
| Positive Side | 180mA
| Negative Side | 85mA
Test Result | PASS

FIGURE 7: ADJUSTABLE CURRENT LOAD
This circuit adjusts the BJT in a common emitter configuration with a variable bias from the potentiometer. The power is dissipated by either the BJT or the resistor, depending on the bias point. The capacitor dampens the BJT to slow any change in conductance.
When testing the negative side, GND is replaced with out and vice versa.

10K

R1
Q1
2N2222A

10R

R2

1nF

C1

OUT

GND

A

Test Results | 6.4 Dynamic Characteristics

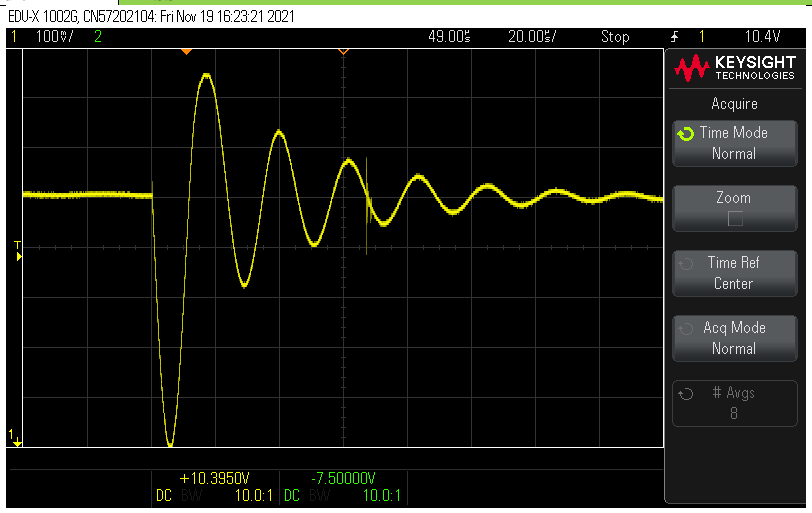
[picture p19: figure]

SIO2MKR Design Report | Page 27

## 6.4 Dynamic Characteristics

## 6.4.1 Load Regulation

Test Description | At maximum output voltage and for both sides, step from a 560R to a 280R (560R||560R) load to ground and measure the change in output voltage after the output voltage has fully stabilised.
Pass Criteria | <1% Output Voltage Change
Results | | 560R Voltage | 280R Load Voltage | Change
| Positive Side | 10V5366 | 10V5772 | +0.39%
| Negative Side | -10v5893 | -10V5340 | -0.52%
Test Result | PASS

## 6.4.2 Line Regulation

As the input voltage is already sourced via a regulated USB supply, and the performance of the tracking pre-regulator, this test was omitted as an unlikely test case.

## 6.4.3 Transient Recovery

Test Condition | At 9V output voltage, step from a 1K to 91R (1K || 100R) load and then back again. Observe the step response of the output voltage and measure the time to settle back to within 15mV of the starting output voltage and the peak dropout.
Pass Criteria | As specified in the respective datasheets for the LM337 and LM317.
Results | | Step Up Settling Time | Step Up Undershoot | Step Down Overshoot | Step Down Settling Time
| Positive Side | 160us | 300mV | 400us | 350mV
| Negative Side | 175mV | 20us | 40us | 100mV
Test Result | PASS

FIGURE 8: POSITIVE SIDE STEP UP TRANSIENT RESPONSE
The positive side experiences a strong second order response. The output settles to within 15mV by 160us with a 300mV undershoot. This response is largely determined by the LM317 linear regulator. The minor spite towards the centre is unfiltered switching noise from the 5V source.

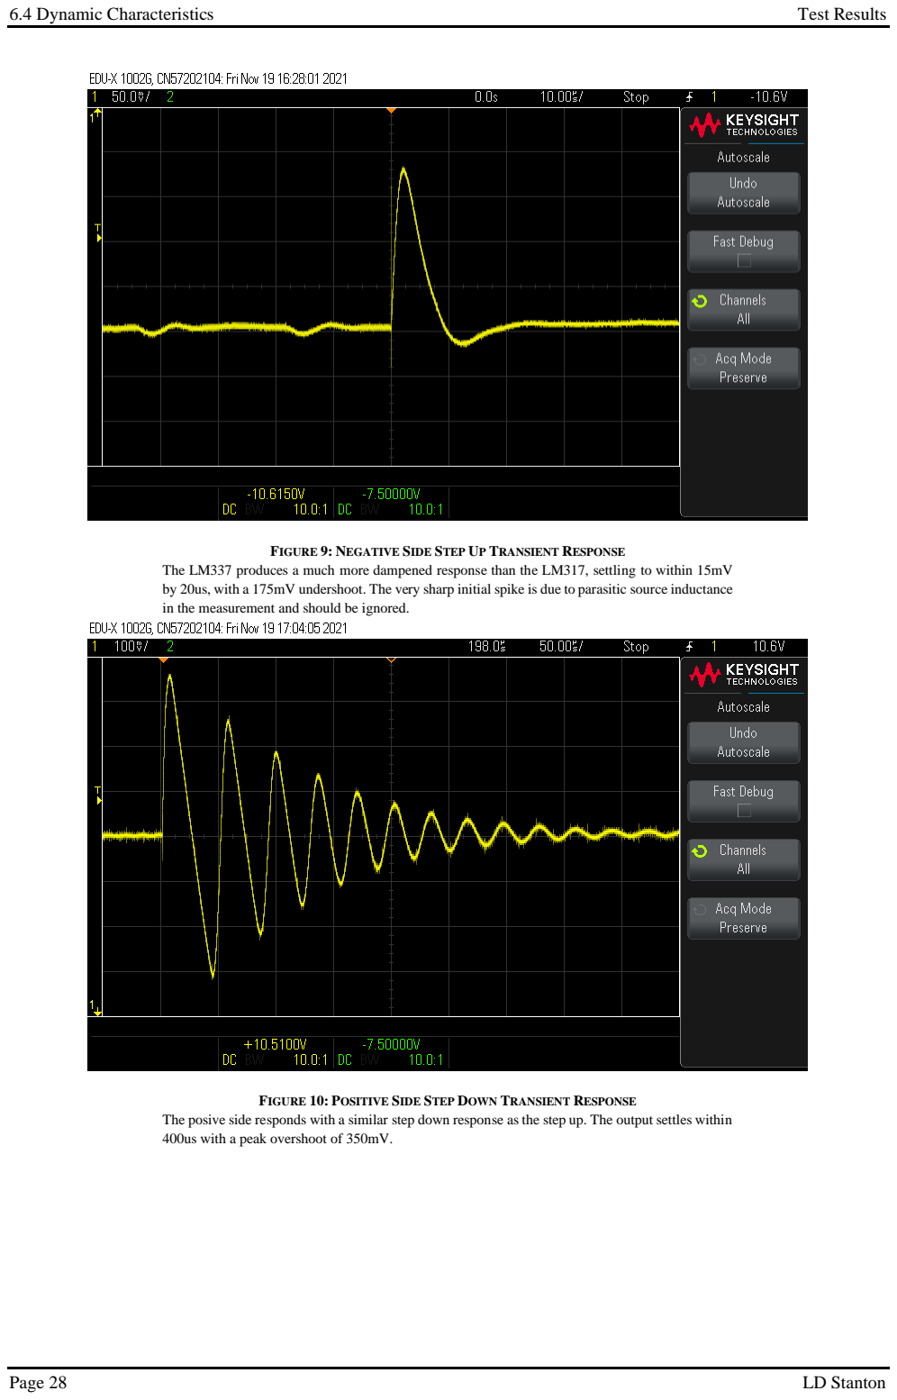
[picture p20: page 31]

6.4 Dynamic Characteristics | Test Results
Page 28 | LD Stanton

FIGURE 9: NEGATIVE SIDE STEP UP TRANSIENT RESPONSE
The LM337 produces a much more dampened response than the LM317, settling to within 15mV by 20us, with a 175mV undershoot. The very sharp initial spike is due to parasitic source inductance in the measurement and should be ignored.

FIGURE 10: POSITIVE SIDE STEP DOWN TRANSIENT RESPONSE
The posive side responds with a similar step down response as the step up. The output settles within 400us with a peak overshoot of 350mV.

Test Results | 6.5 Supplemental Information

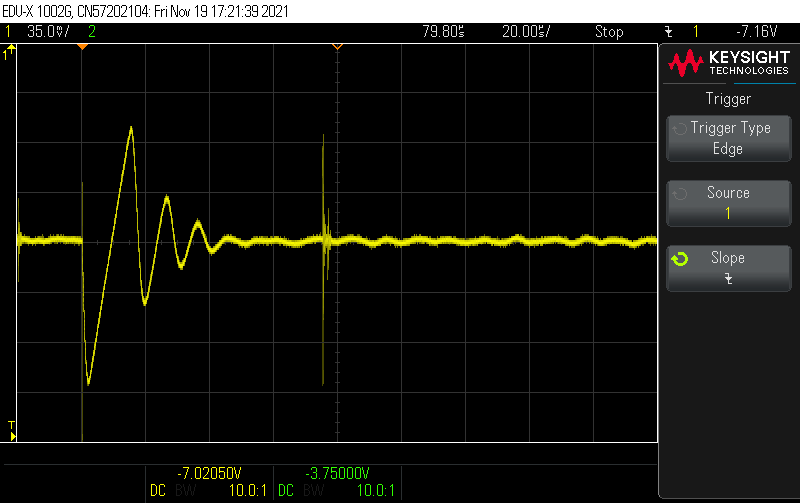
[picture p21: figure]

SIO2MKR Design Report | Page 29

FIGURE 11: NEGATIVE SIDE STEP DOWN TRANSIENT RESPONSE
The negative side step down exhibits an asymmetrical second order response. Regardless, the output settles within 40us with a peak overshoot of 100mV.

## 6.4.4 Output Ripple and Noise

Test Condition | At maximum output voltage, power input by a portable USB battery bank, and at a 1K load, measure the output AC RMS noise and Peak-to-Peak ripple over a 1ms period.
Pass Criteria | < 5mVrms, < 50mVpp
Results | | AC RMS | Ripple Peak to Peak
| Positive Side | 1.86mVrms | 48mVpp
| Negative Side | 2.99mVrms | 36mVpp
Test Result | PASS

## 6.5 Supplemental Information

TABLE 3: SUPPLEMENTAL INFORMATION
Outer Dimensions | 5.2 x 6.4 x 2.5mm
Weight

## Appendix A — Schematic

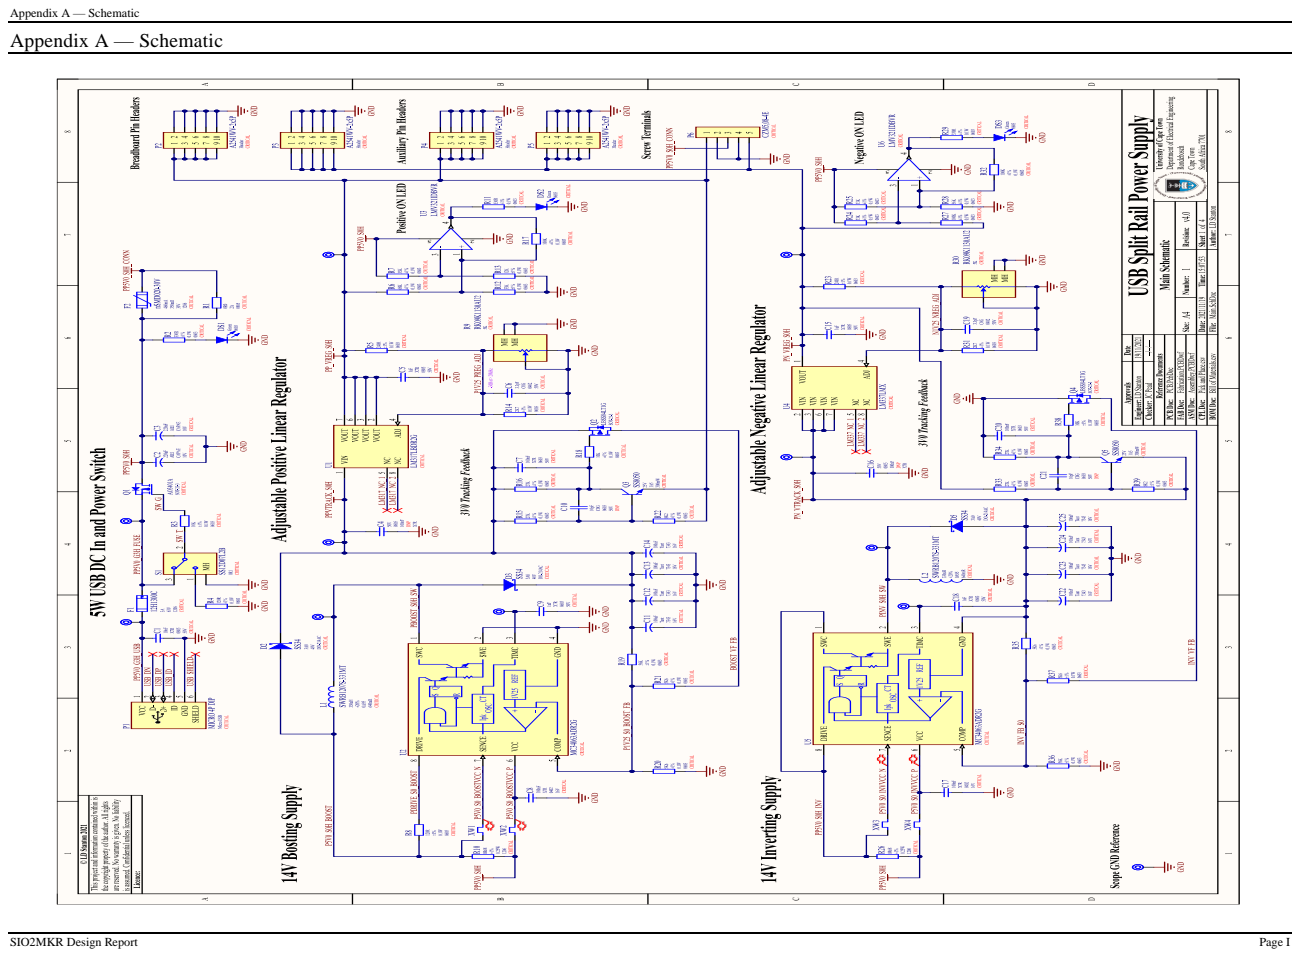
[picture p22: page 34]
Appendix A — Schematic; SIO2MKR Design Report; Page I

Appendix D — Bill of Materials

Page II | LD Stanton

## Appendix D — Bill of Materials

Comment | Description | Designator | QTY | LCSC Part Number
CL21B103KBANNNC | MLCC 10nF 0805 50V X7R ±10% | C1 | 1 | C1710
RVT1A221M0605 | Aluminium Electrolytic Capacitor 220uF CAPAE 10V ±20% | C2, C3 | 2 | C3345
CC0805KRX7R9BB104 | MLCC 100nF 50V 0805 X7R ±10% | C4, C16 | 2 | C49678
CL21B105KBFNNNE | MLCC 1uF 0805 50V X7R ±10% | C5, C15 | 2 | C28323
0402CG3R3C500NT | MLCC 3.3pF 0402 50V C0G ±0.25pF | C6, C19 | 2 | C1565
CC0603KRX7R9BB104 | MLCC 100nF 50V 0603 X7R ±10% | C7, C20 | 2 | C14663
CL05B104KO5NNNC | MLCC 100nF 0402 16V X7R ±10% | C8, C17 | 2 | C1525
CL10B102KB8NNNC | MLCC 1nF 0603 50V X7R ±10% | C9, C18 | 2 | C1588
MLCC 10pF 0603 50V C0G | MLCC 10pF 0603 C0G ±0.1pF | C10, C21 | 2 | C1634
293D107X9016D2TE3 | Tantalum Capacitor 100uF 16V ±20% | C11, C12, C13, C14, C22, C23, C24, C25 | 8 | C129696
19-217/GHC-YR1S2/3T | LED 0603 SMT Green | D1, D4, D6 | 3 | C72043
SS34 | Schottky Barrier Diode 40V 3A0 550mV | D2, D3, D5 | 3 | C8678
12H1300C | Fuse SMD Slow Blow 3A 63VAC 1206 | F1 | 1 | C182445
nSMD020-30V | Fuse SMD PTC Resettable 460mA 30VDC 1206 | F2 | 1 | C69680
SWRB1207S-331MT | Inductor 330uH ±20% 0A95 640mR Moulded SMD 12.5x12.5x8.0mm | L1, L2 | 2 | C169381
MICRO 4P DIP | Micro USB Connector SMT with TH Mounts | P1 | 1 | C456008
A2541WV-2x5P | Pin Header 10 Way Double Row Vertical Angle | P2, P3 | 2 | C225520
A2541HWR-2x2P | Pin Header 4 Way Double Row Female Right Angle | P4, P5 | 2
CZM5,08-4E | Screw Down Terminal 5 Way 5.08mm Pitch | P6 | 1
AO3401A | MOSFET Trench 4A0 30V 85mR ±12V P-Channel Enhancement AOS SOT-22-3L | Q1 | 1 | C15127
LBSS84LT1G | Small Signal MOSFET, 130 mA, 50 V, P-Channel, Enhancement, LRC SOT-23-3 | Q2, Q4 | 2 | C8492
SS8050 | BJT NPN 1A5 25V SOT-23-3 | Q3, Q5 | 2 | C2150
Res 0R 0805 | Jumper 0805 | R1 | 1 | C17477
0603WAF3300T5E | Lead Free Thick Film Chip Resistor 0805 ±1% | R2, R11, R29 | 3 | C23138
0603WAF1002T5E | Lead Free Thick Film Chip Resistor 0603 ±1% | R3, R38 | 2 | C25804

Appendix D — Bill of Materials

SIO2MKR Design Report | Page III
0603WAF1200T5E | Lead Free Thick Film Chip Resistor 0603 ±1% | R4, R8 | 2 | C22787
0603WAF2400T5E | Lead Free Thick Film Chip Resistor 0603 ±1% | R5, R23 | 2 | C23350
Res 68K 0603 | Lead Free Thick Film Chip Resistor 0603 ±1% | R6 | 1 | C23231
Res 33K 0603 | Lead Free Thick Film Chip Resistor 0603 ±1% | R7, R12, R24, R25 | 4 | C4216
RK09K1130AU2 | 5K Potentiometer THT 9.8mm Diameter ±20% 20VDC | R9, R30 | 2 | C388855
1206W4F680LT5E | Lead Free Thick Film Chip Resistor 1206 ±1% | R10, R26 | 2 | C19108
Res 12K 0603 | Lead Free Thick Film Chip Resistor 0603 ±1% | R13 | 1 | C22790
0603WAF2701T5E | Lead Free Thick Film Chip Resistor 0603 ±1% | R14, R31 | 2 | C13167
0603WAF2702T5E | Lead Free Thick Film Chip Resistor 0603 ±1% | R15, R16, R33, R34 | 4 | C22967
Res 100K 0603 | Lead Free Thick Film Chip Resistor 0603 ±1% | R17, R27, R32 | 3 | C25803
Res 10K 0603 | Lead Free Thick Film Chip Resistor 0603 ±1% | R18 | 1 | C25804
0603WAF5602T5E | Lead Free Thick Film Chip Resistor 0603 ±1% | R19, R36 | 2 | C23206
0603WAF5601T5E | Lead Free Thick Film Chip Resistor 0603 ±1% | R20, R21, R35, R37 | 4 | C23189
0603WAF8201T5E | Lead Free Thick Film Chip Resistor 0603 ±1% | R22, R39 | 2 | C25981
Res 56K 0603 | Lead Free Thick Film Chip Resistor 0603 ±1% | R28 | 1 | C23206
SS12D07L2B | Switch Toggle Slider THT Vertical 0A3 50V | S1 | 1 | C480342
LM317LBDR2G | 100mA, 1V2 - 37V Adjustable Output, Positive Voltage Regulator | U1 | 1 | C274645
MC34063ADR2G | 1A5 Step-Up, Step-Down, Inverting Switching Reulator | U2, U5 | 2 | C32078
LMV321IDBVR | OP AMP, 1MHZ, 1V/uS, SOT-23-5, FULL REEL; Bandwidth:1MHz; No. of Amplifiers:1; Slew Rate:1V/ s; Supply Voltage Range:2.7V to 5.5V; Amplifier Case Style:SOT-23; No. of Pins:5; Operating Temperature Min:-40 C; Packaging:Tape & Reel ;RoHS Compliant: Yes | U3, U6 | 2 | C7972
LM337LMX | 100mA, -1V2 to -37V Adjustable Negative Voltage Regulator | U4 | 1 | C7947

Appendix E — E12 Voltage Divider Script

Page IV | LD Stanton

## Appendix E — E12 Voltage Divider Script

## #!/usr/local/bin/python3

## print("Voltage Divider Solver (E12 Series)") #Input parameters Vcc = input("Enter the input voltage:\n\t") Vcc = float(Vcc) Vout = input("Enter the output voltage:\n\t") Vout = float(Vout)

## Notify of convention print("R1 is the resistor connected to ground")

## #E12 Values

E12 = [1.0, 1.2, 1.5, 1.8, 2.2, 2.7, 3.3, 3.9, 4.7, 5.6, 6.8, 8.2, 10, 12, 15, 18, 22, 27, 33, 39, 47, 56, 68, 82]

## Ratio to solve B = Vout/Vcc

## Matrix of all possible combinations A=[[None for i in range(len(E12))]for j in range(len(E12))]

## Build all possible combinatons for i in range(len(E12)): for j in range(len(E12)): R1 = E12[i] R2 = E12[j] #R1 is the resistor closest to ground A[i][j] = R1/(R1+R2)

## Comparison array D = [[None for i in range(len(E12))]for j in range(len(E12))] #Determine the difference between A and B for i in range(len(E12)): for j in range(len(E12)):

Appendix E — E12 Voltage Divider Script

SIO2MKR Design Report | Page V

## D[i][j] = abs(A[i][j] - B)

## Find the minimum difference #No difference will be greater than 1 min = 1 for i in range(len(E12)): for j in range(len(E12)): if(D[i][j]<min): min = D[i][j] imin = i jmin = j

## print optimal values print("Best value for R1: "+str(E12[imin])) print("Best value for R2: "+str(E12[jmin])) print("Real output voltage is: "+str(round(A[imin][jmin]*Vcc, 2))+"V")

## input()

Appendix F — CERN OHL v2 Permissive Licence

Page VI | LD Stanton

## Appendix F — CERN OHL v2 Permissive Licence

The CERN OHL V2 Permissive licence is included here for information purposes only since the hardware design is licenced under this licence. This document itself however IS NOT licenced under this licence.

CERN Open Hardware Licence Version 2 - Permissive

Preamble

CERN has developed this licence to promote collaboration among hardware designers and to provide a legal tool which supports the freedom to use, study, modify, share and distribute hardware designs and products based on those designs. Version 2 of the CERN Open Hardware Licence comes in three variants: this licence, CERN-OHL-P (permissive); and two reciprocal licences: CERN- OHL-W (weakly reciprocal) and CERN-OHL-S (strongly reciprocal).

The CERN-OHL-P is copyright © CERN 2020. Anyone is welcome to use it, in unmodified form only.

Use of this Licence does not imply any endorsement by CERN of any Licensor or their designs nor does it imply any involvement by CERN in their development.

### 1. Definitions

1.1 ‘Licence’ means this CERN-OHL-P.

1.2 ‘Source’ means information such as design materials or digital code which can be applied to Make or test a Product or to prepare a Product for use, Conveyance or sale, regardless of its medium or how it is expressed. It may include Notices.

1.3 ‘Covered Source’ means Source that is explicitly made available under this Licence.

1.4 ‘Product’ means any device, component, work or physical object, whether in finished or intermediate form, arising from the use, application or pro- cessing of Covered Source.

1.5 ‘Make’ means to create or configure something, whether by manufacture, assembly, compiling, loading or applying Covered Source or another Product or otherwise.

1.6 ‘Notice’ means copyright, acknowledgement and trademark notices, references to the location of any Notices, modification notices (subsection 3.3(b)) and all notices that refer to this Licence and to the disclaimer of warranties that are included in the Covered Source.

1.7 ‘Licensee’ or ‘You’ means any person exercising rights under this Licence.

1.8 ‘Licensor’ means a person who creates Source or modifies Covered Source and subsequently Conveys the resulting Covered Source under the terms and conditions of this Licence. A person may be a Licensee and a Licensor at the same time.

1.9 ‘Convey’ means to communicate to the public or distribute.

Appendix F — CERN OHL v2 Permissive Licence

SIO2MKR Design Report | Page VII

### 2. Applicability

2.1 This Licence governs the use, copying, modification, Conveying of Covered Source and Products, and the Making of Products. By exercising any right granted under this Licence, You irrevocably accept these terms and conditions.

2.2 This Licence is granted by the Licensor directly to You, and shall apply worldwide and without limitation in time.

2.3 You shall not attempt to restrict by contract or otherwise the rights granted under this Licence to other Licensees. This Licence is not intended to restrict fair use, fair dealing, or any other similar right.

### 3. Copying, Modifying and Conveying Covered Source

3.1 You may copy and Convey verbatim copies of Covered Source, in any medium, provided You retain all Notices.

3.2 You may modify Covered Source, other than Notices.

You may only delete Notices if they are no longer applicable to the corresponding Covered Source as modified by You and You may add additional Notices applicable to Your modifications.

3.3 You may Convey modified Covered Source (with the effect that You shall also become a Licensor) provided that You:

a) retain Notices as required in subsection 3.2; and
b) add a Notice to the modified Covered Source stating that You have modified it, with the date and brief description of how You have modified it.

3.4 You may Convey Covered Source or modified Covered Source under licence terms which differ from the terms of this Licence provided that You:

a) comply at all times with subsection 3.3; and
b) provide a copy of this Licence to anyone to whom You Convey Covered Source or modified Covered Source.

### 4. Making and Conveying Products

4.1 You may Make Products, and/or Convey them, provided that You ensure that the recipient of the Product has access to any Notices applicable to the Product.

Appendix F — CERN OHL v2 Permissive Licence

Page VIII | LD Stanton

### 5. DISCLAIMER AND LIABILITY

5.1 DISCLAIMER OF WARRANTY – The Covered Source and any Products are provided ‘as is’ and any express or implied warranties, including, but not limited to, implied warranties of merchantability, of satisfactory quality, non-infringement of third party rights, and fitness for a particular purpose or use are disclaimed in respect of any Source or Product to the maximum extent permitted by law. The Licensor makes no representation that any Source or Product does not or will not infringe any patent, copyright, trade secret or other proprietary right. The entire risk as to the use, quality, and performance of any Source or Product shall be with You and not the Licensor. This disclaimer of warranty is an essential part of this Licence and a condition for the grant of any rights granted under this Licence.

5.2 EXCLUSION AND LIMITATION OF LIABILITY – The Licensor shall, to the maximum extent permitted by law, have no liability for direct, indirect, special, incidental, consequential, exemplary, punitive or other damages of any character including, without limitation, procurement of substitute goods or services, loss of use, data or profits, or business interruption, however caused and on any theory of contract, warranty, tort (including negligence), product liability or otherwise, arising in any way in relation to the Covered Source, modified Covered Source and/or the Making or Conveyance of a Product, even if advised of the possibility of such damages, and You shall hold the Licensor(s) free and harmless from any liability, costs, damages, fees and expenses, including claims by third parties, in relation to such use.

### 6. Patents

6.1 Subject to the terms and conditions of this Licence, each Licensor hereby grants to You a perpetual, worldwide, non-exclusive, no-charge, royalty-free, irrevocable (except as stated in this section 6, or where terminated by the Licensor for cause) patent licence to Make, have Made, use, offer to sell, sell, import, and otherwise transfer the Covered Source and Products, where such licence applies only to those patent claims licensable by such Licensor that are necessarily infringed by exercising rights under the Covered Source as Conveyed by that Licensor.

6.2 If You institute patent litigation against any entity (including a cross-claim or counterclaim in a lawsuit) alleging that the Covered Source or a Product constitutes direct or contributory patent infringement, or You seek any declaration that a patent licensed to You under this Licence is invalid or unenforceable then any rights granted to You under this Licence shall terminate as of the date such process is initiated.

### 7. General

7.1 If any provisions of this Licence are or subsequently become invalid or unenforceable for any reason, the remaining provisions shall remain effective.

7.2 You shall not use any of the name (including acronyms and abbreviations), image, or logo by which the Licensor or CERN is known, except where needed to comply with section 3, or where the use is otherwise allowed by law. Any such permitted use shall be factual and shall not be made so as to suggest any kind of endorsement or implication of involvement by the Licensor or its personnel.

7.3 CERN may publish updated versions and variants of this Licence which it considers to be in the spirit of this version, but may differ in detail to address new problems or concerns. New versions will be published with a unique version number and a variant identifier specifying the variant. If the Licensor has specified that a given variant applies to the Covered Source without specifying a version, You may treat that Covered Source as being released under any version of the CERN-OHL with that variant. If no variant is specified, the Covered Source shall be treated as being released under CERN-OHL-S. The Licensor may also specify that the Covered Source is subject to a specific version of the CERN-OHL or any later version in which case You may apply this or any later version of CERN-OHL with the same variant identifier published by CERN.

7.4 This Licence shall not be enforceable except by a Licensor acting as such, and third party beneficiary rights are specifically excluded. L

## Declaration

The author declares this document and related work to be original work of the author. Any assistance or use of the work of others is to have been duly referenced or acknowledged, and the document is free of any form of plagiarism. This document uses the IEEE referencing convention.

The author declares there to have been no conflict of interest in regard to the decisions, recommendations or use of any particular product or service used in the work described herein.

## Notice

Information in this document is provided solely in relation to degree-granting activities. The author reserves the right to make changes, corrections, improvements or modifications at any time, without notice. This document is presented “as is” without any warranty whatsoever. The author assumes no liability whatsoever relating to the use of any information presented herein. No licence to any intellectual property rights is granted under this document. Any reference to third party products or services shall not be deemed a licence grant for the use of such products or services nor shall be considered as a warranty covering the use of said products or services.

## Licence

This document is the copyright property of the author and may only be reproduced, duplicated or published for degree-granting activities. Reproduction, redaction or publication for any other purpose is only permitted on expressed prior agreement or licence granted by the author. Requests for any such activity should be directed in writing to the author.

## Contact Details

Lawrence Stanton
Electrical Engineering Postgraduate University of Cape Town

Email (UCT): STNLAW003@myuct.ac.za Email (Private): lawrence.stanton@icloud.com
GitHub: | https://github.com/LawrenceStanton

© LD Stanton 2022

END OF DOCUMENT

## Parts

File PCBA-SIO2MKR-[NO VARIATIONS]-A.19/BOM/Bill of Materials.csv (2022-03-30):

Comment | Description | Designator | Footprint | Quantity | LCSC Part Number
CL21B103KBANNNC | MLCC 10nF 0805 50V X7R ±10% | C1 | 0605_065_A_N | 1 | C1710
RVT1A221M0605 | Aluminium Electrolytic Capacitor 220uF CAPAE 10V ±20% | C2, C3 | CAPAE 6354 | 2 | C3345
CC0805KRX7R9BB104 | MLCC 100nF 50V 0805 X7R ±10% | C4, C16 | 0805 | 2 | C49678
CL21B105KBFNNNE | MLCC 1uF 0805 50V X7R ±10% | C5, C15 | 0805_125_F_N | 2 | C28323
0402CG3R3C500NT | MLCC 3.3pF 0402 50V C0G ±0.25pF | C6, C19 | 0402_050 | 2 | C1565
CC0603KRX7R9BB104 | MLCC 100nF 50V 0603 X7R ±10% | C7, C20 | 0603 | 2 | C14663
CL05B104KO5NNNC | MLCC 100nF 0402 16V X7R ±10% | C8, C17 | 0402_050_5_N | 2 | C1525
CL10B102KB8NNNC | MLCC 1nF 0603 50V X7R ±10% | C9, C18 | 0603_080_8_N | 2 | C1588
MLCC 10pF 0603 50V C0G | MLCC 10pF 0603 C0G ±0.1pF | C10, C21 | 0603_080_8_N | 2 | C1634
293D107X9016D2TE3 | Tantalum Capacitor 100uF 16V ±20% | C11, C12, C13, C14, C22, C23, C24, C25 | Case D | 8 | C129696
SS34 | Schottky Barrier Diode 40V 3A0 550mV | D2, D3, D5 | DO-214AC | 3 | C8678
19-217/GHC-YR1S2/3T | LED 0603 SMT Green | DS1, DS2, DS3 | LED 0603 | 3 | C72043
0468001.NRHF | Fuse 1A 63VAC/VDC SMD Littlefuse | F1 | Fuse 1206 (Littlefuse 468) B | 1 | C45157
nSMD020-30V | Fuse SMD PTC Resettable 460mA 30VDC 1206 | F2 | FUSE3216X09N | 1 | C69680
SWRB1207S-331MT | Inductor 330uH ±20% 0A95 640mR Moulded SMD 12.5x12.5x8.0mm | L1, L2 | SWRB1207S | 2 | C169381
MICRO 4P DIP | Micro USB Connector SMT with TH Mounts | P1 | MICRO 4P DIP | 1 | C456008
A2541WV-2x5P | Pin Header 10 Way Double Row Vertical Angle | P2, P3, P4, P5 | Pin Header 10 2 Vertical Male | 4 | C225520
CZM5,08-4E | Screw Down Terminal 5 Way 5.08mm Pitch | P6 | Screw Down 5 | 1
AO3401A | MOSFET Trench 4A0 30V 85mR ±12V P-Channel Enhancement AOS SOT-22-3L | Q1 | SOT-23-3 (2N7002) | 1 | C15127
LBSS84LT1G | Small Signal MOSFET, 130 mA, 50 V, P-Channel, Enhancement, LRC SOT-23-3 | Q2, Q4 | SOT-23-3 (2N7002) | 2 | C8492
SS8050 | BJT NPN 1A5 25V SOT-23-3 | Q3, Q5 | SOT-23-3 Generic | 2 | C2150
0805W8F0000T5E | Jumper 0805 2A Uniroyal | R1 | 0805 | 1 | C17477
0603WAF3300T5E | Lead Free Thick Film Chip Resistor 0805 ±1% | R2, R11, R29 | 0603 | 3 | C23138
0603WAF1002T5E | Lead Free Thick Film Chip Resistor 0603 ±1%, Resistor 10K 0603 ±1% Thick Film Uniroyal | R3, R18, R38 | 0603 | 3 | C25804
0603WAF1200T5E | Lead Free Thick Film Chip Resistor 0603 ±1% | R4, R8 | 0603 | 2 | C22787
0603WAF2400T5E | Lead Free Thick Film Chip Resistor 0603 ±1% | R5, R23 | 0603 | 2 | C23350
0603WAF6802T5E | Resistor 68K 0603 ±1% Thick Film Uniroyal | R6 | 0603 | 1 | C23231
0603WAF3302T5E | Resistor 33K 0603 ±1% Thick Film Uniroyal | R7, R12, R24, R25 | 0603 | 4 | C4216
RK09K1130AU2 | 5K Potentiometer THT 9.8mm Diameter ±20% 20VDC | R9, R30 | RK09K113 | 2 | C388855
1206W4F680LT5E | Lead Free Thick Film Chip Resistor 1206 ±1% | R10, R26 | 1206 | 2 | C19108
0603WAF1202T5E | Resistor 12K 0603 ±1% Thick Film Uniroyal | R13 | 0603 | 1 | C22790
0603WAF2701T5E | Lead Free Thick Film Chip Resistor 0603 ±1% | R14, R31 | 0603 | 2 | C13167
0603WAF4702T5E | Resistor 47K 0603 ±1% Thick Film Uniroyal | R15, R33 | 0603 (Uniroyal) B | 2 | C25819
0603WAF2702T5E | Lead Free Thick Film Chip Resistor 0603 ±1% | R16, R34 | 0603 | 2 | C22967
0603WAF1003T5E | Resistor 100K 0603 ±1% Thick Film Uniroyal | R17, R27, R32 | 0603 | 3 | C25803
0603WAF5602T5E | Lead Free Thick Film Chip Resistor 0603 ±1%, Resistor 56K 0603 ±1% Thick Film Uniroyal | R19, R28, R36 | 0603 | 3 | C23206
0603WAF5601T5E | Lead Free Thick Film Chip Resistor 0603 ±1% | R20, R21, R35, R37 | 0603 | 4 | C23189
0603WAF1002T5E | Resistor 10K 0603 ±1% Thick Film Uniroyal | R22, R39 | 0603 (Uniroyal) B | 2 | C25804
SS12D07L2B | Switch Toggle Slider THT Vertical 0A3 50V | S1 | SS12D07 | 1 | C480342
LM317LBDR2G | 100mA, 1V2 - 37V Adjustable Output, Positive Voltage Regulator | U1 | SOIC-8 NB | 1 | C7940
MC34063ADR2G | 1A5 Step-Up, Step-Down, Inverting Switching Reulator | U2, U5 | SOIC-8 NB | 2 | C32078
LMV321IDBVR | OP AMP, 1MHZ, 1V/uS, SOT-23-5, FULL REEL; Bandwidth:1MHz; No. of Amplifiers:1; Slew Rate:1V/ s; Supply Voltage Range:2.7V to 5.5V; Amplifier Case Style:SOT-23; No. of Pins:5; Operating Temperature Min:-40 C; Packaging:Tape & Reel ;RoHS Compliant: Yes | U3, U6 | FP-DBV0005A-IPC_B | 2 | C7972
LM337LZ/NOPB | 100mA, -1V2 to -37V Adjustable Negative Voltage Regulator | U4 | TO-92 (LM337) | 1 | C33082

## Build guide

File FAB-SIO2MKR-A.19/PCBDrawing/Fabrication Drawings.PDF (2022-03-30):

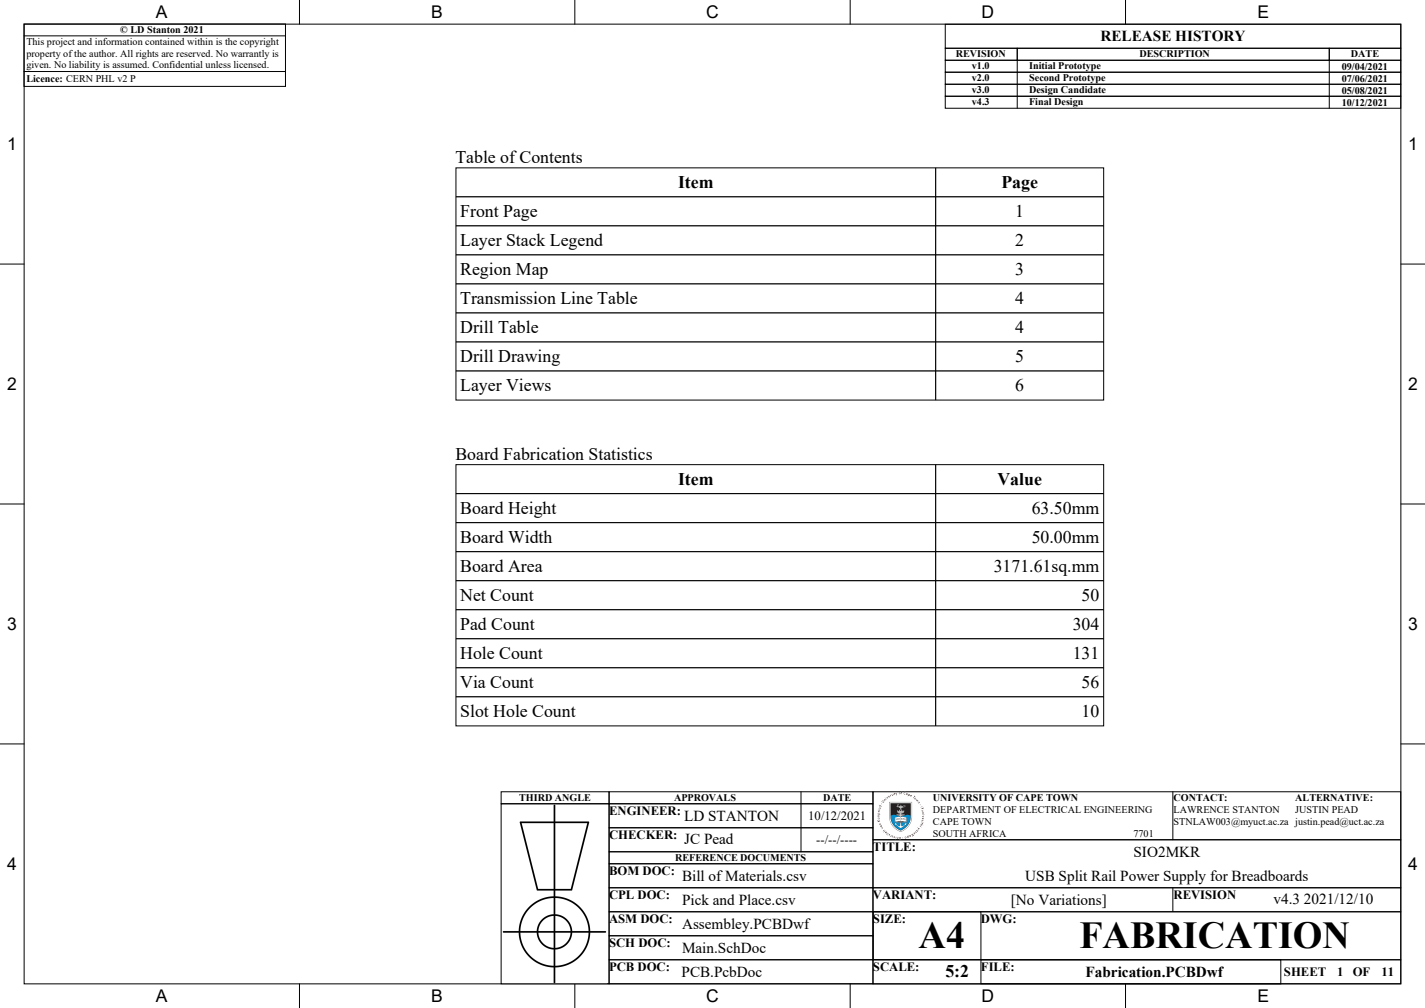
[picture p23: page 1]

This project and information contained within is the copyright
property of the author. All rights are reserved. No warrantly is
given. No liability is assumed. Confidential unless licensed.
Licence: CERN PHL v2 P

REVISION | DESCRIPTION | DATE
v1.0 | Initial Prototype | 09/04/2021

v3.0 | Design Candidate | 05/08/2021
v4.3 | Final Design | 10/12/2021

Item | Page

Front Page | 1
Layer Stack Legend | 2
Region Map | 3
Transmission Line Table | 4
Drill Table | 4
Drill Drawing | 5
Layer Views | 6

Item | Value

Board Height | 63.50mm
Board Width | 50.00mm
Board Area | 3171.61sq.mm
Net Count | 50
Pad Count | 304
Hole Count | 131
Via Count | 56
Slot Hole Count | 10

THIRD ANGLE | APPROVALS | DATE | UNIVERSITY OF CAPE TOWN DEPARTMENT OF ELECTRICAL ENGINEERING CAPE TOWN SOUTH AFRICA 7701 | CONTACT: ALTERNATIVE: LAWRENCE STANTON JUSTIN PEAD STNLAW003@myuct.ac.za justin.pead@uct.ac.za

ENGINEER: LD STANTON | 10/12/2021
CHECKER: JC Pead | --/--/----

REFERENCE DOCUMENTS
Bill of Materials.csv

USB Split Rail Power Supply for Breadboards

CPL DOC: Pick and Place.csv | VARIANT: [No Variations] | REVISION v4.3 2021/12/10
ASM DOC: Assembley.PCBDwf | SIZE: A4 | DWG: FABRICATION

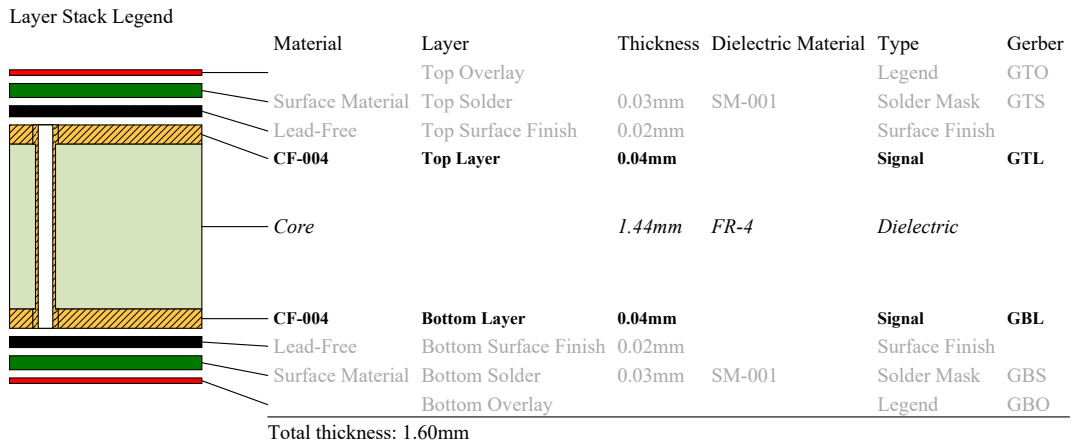
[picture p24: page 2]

SIZE: A4 | DWG: FABRICATION

Fabrication.PCBDwf | SHEET 2 OF 11

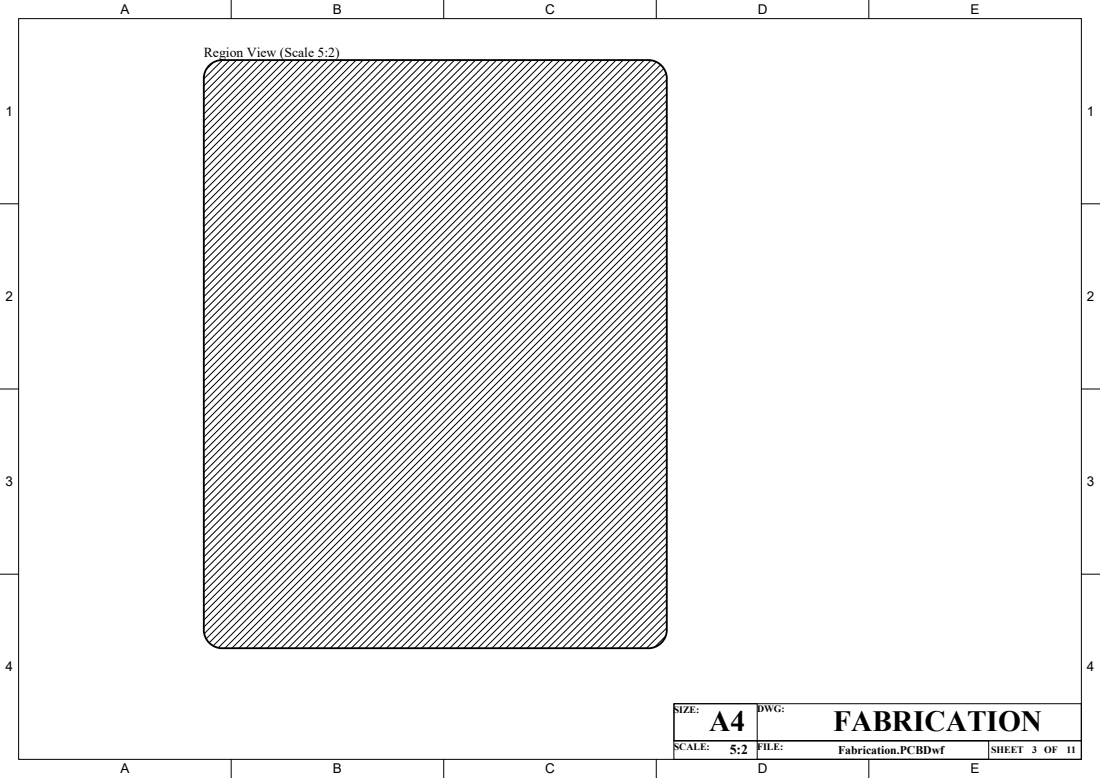
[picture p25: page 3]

SIZE: A4 | DWG: FABRICATION

Fabrication.PCBDwf | SHEET 3 OF 11

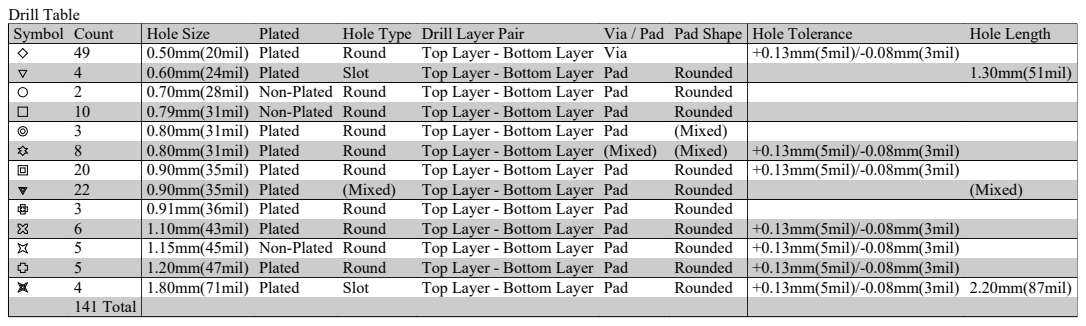
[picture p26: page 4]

Symbol | Count | Hole Size | Plated | Hole Type | Drill Layer Pair | Via / Pad | Pad Shape | Hole Tolerance | Hole Length

49 | 0.50mm(20mil) | Plated | Round | Top Layer - Bottom Layer | Via | | +0.13mm(5mil)/-0.08mm(3mil)
4 | 0.60mm(24mil) | Plated | Slot | Top Layer - Bottom Layer | Pad | Rounded | | 1.30mm(51mil)
2 | 0.70mm(28mil) | Non-Plated | Round | Top Layer - Bottom Layer | Pad | Rounded
10 | 0.79mm(31mil) | Non-Plated | Round | Top Layer - Bottom Layer | Pad | Rounded
3 | 0.80mm(31mil) | Plated | Round | Top Layer - Bottom Layer | Pad | (Mixed)
8 | 0.80mm(31mil) | Plated | Round | Top Layer - Bottom Layer | (Mixed) | (Mixed) | +0.13mm(5mil)/-0.08mm(3mil)
20 | 0.90mm(35mil) | Plated | Round | Top Layer - Bottom Layer | Pad | Rounded | +0.13mm(5mil)/-0.08mm(3mil)
22 | 0.90mm(35mil) | Plated | (Mixed) | Top Layer - Bottom Layer | Pad | Rounded | | (Mixed)
3 | 0.91mm(36mil) | Plated | Round | Top Layer - Bottom Layer | Pad | Rounded
6 | 1.10mm(43mil) | Plated | Round | Top Layer - Bottom Layer | Pad | Rounded | +0.13mm(5mil)/-0.08mm(3mil)
5 | 1.15mm(45mil) | Non-Plated | Round | Top Layer - Bottom Layer | Pad | Rounded | +0.13mm(5mil)/-0.08mm(3mil)
5 | 1.20mm(47mil) | Plated | Round | Top Layer - Bottom Layer | Pad | Rounded | +0.13mm(5mil)/-0.08mm(3mil)
4 | 1.80mm(71mil) | Plated | Slot | Top Layer - Bottom Layer | Pad | Rounded | +0.13mm(5mil)/-0.08mm(3mil) | 2.20mm(87mil)
141 Total

SIZE: A4 | DWG: FABRICATION

Fabrication.PCBDwf | SHEET 4 OF 11

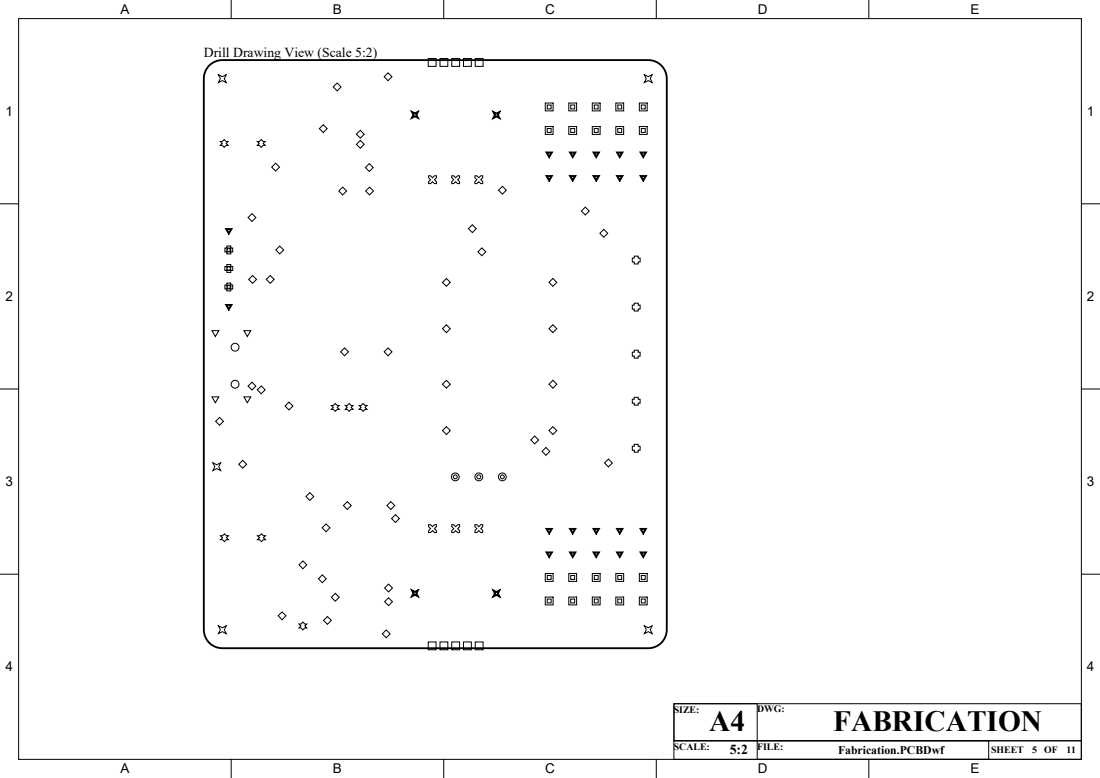
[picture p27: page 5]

Drill Drawing View (Scale 5:2)

SIZE: A4 | DWG: FABRICATION

Fabrication.PCBDwf | SHEET 5 OF 11

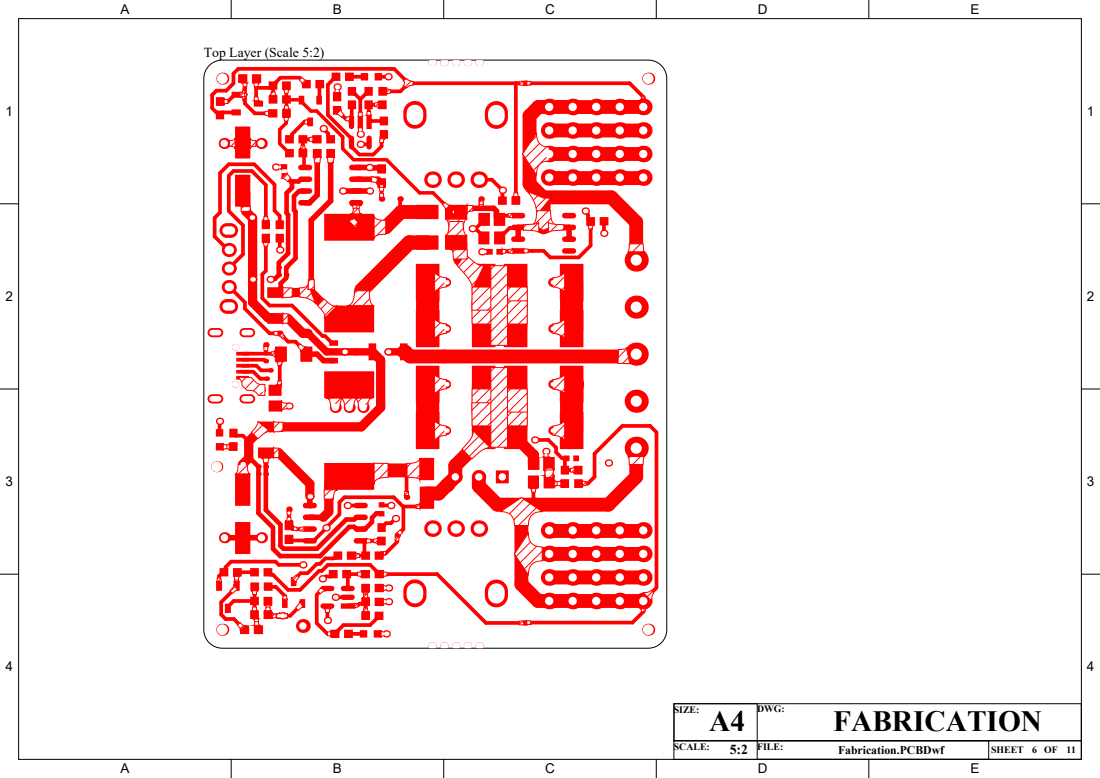
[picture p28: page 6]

SIZE: A4 | DWG: FABRICATION

Fabrication.PCBDwf | SHEET 6 OF 11

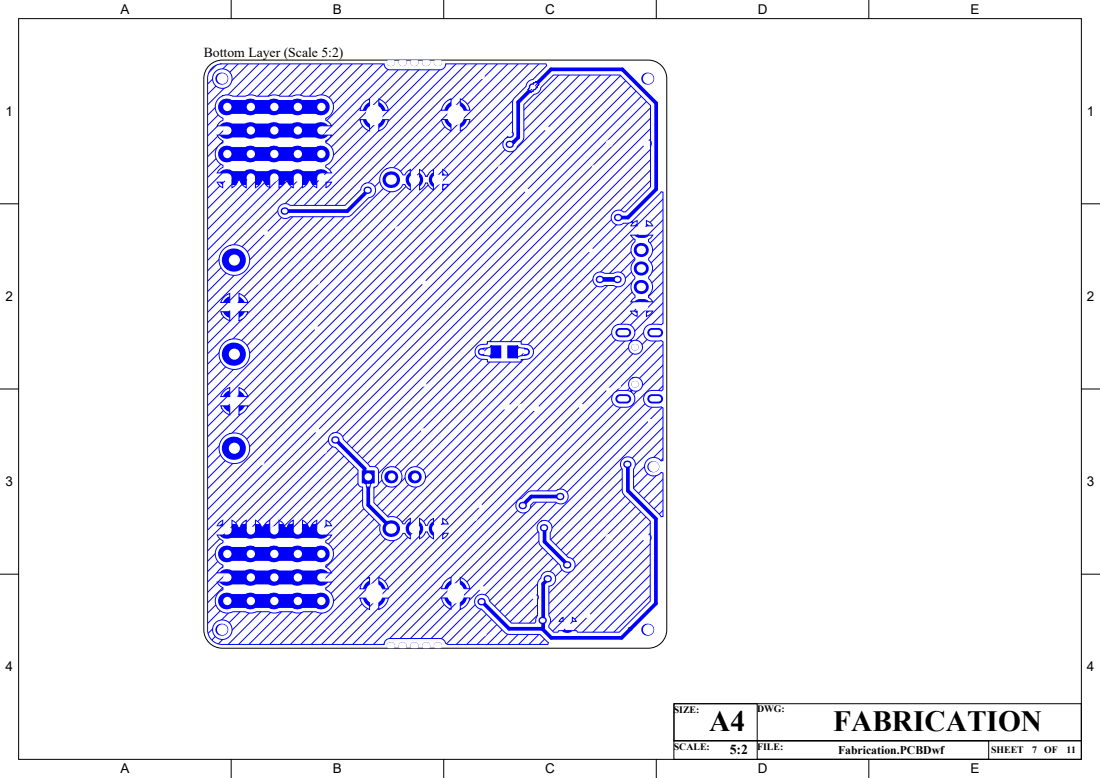
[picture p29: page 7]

SIZE: A4 | DWG: FABRICATION

Fabrication.PCBDwf | SHEET 7 OF 11

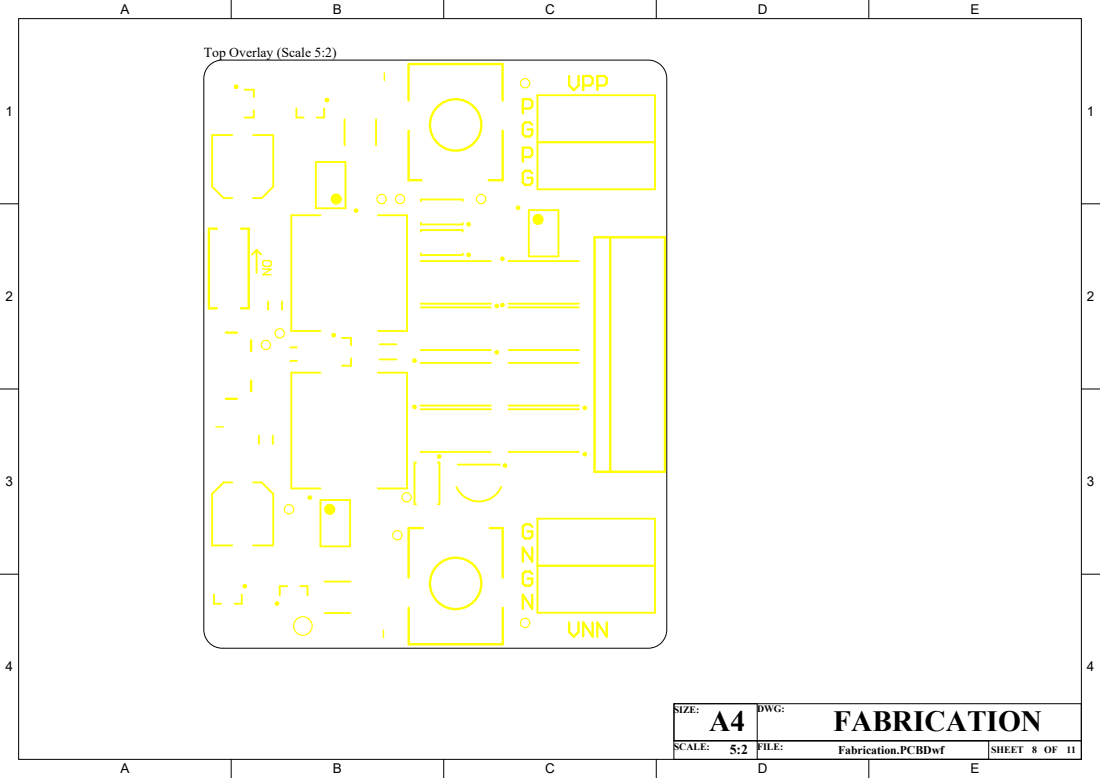
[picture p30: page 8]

SIZE: A4 | DWG: FABRICATION

Fabrication.PCBDwf | SHEET 8 OF 11

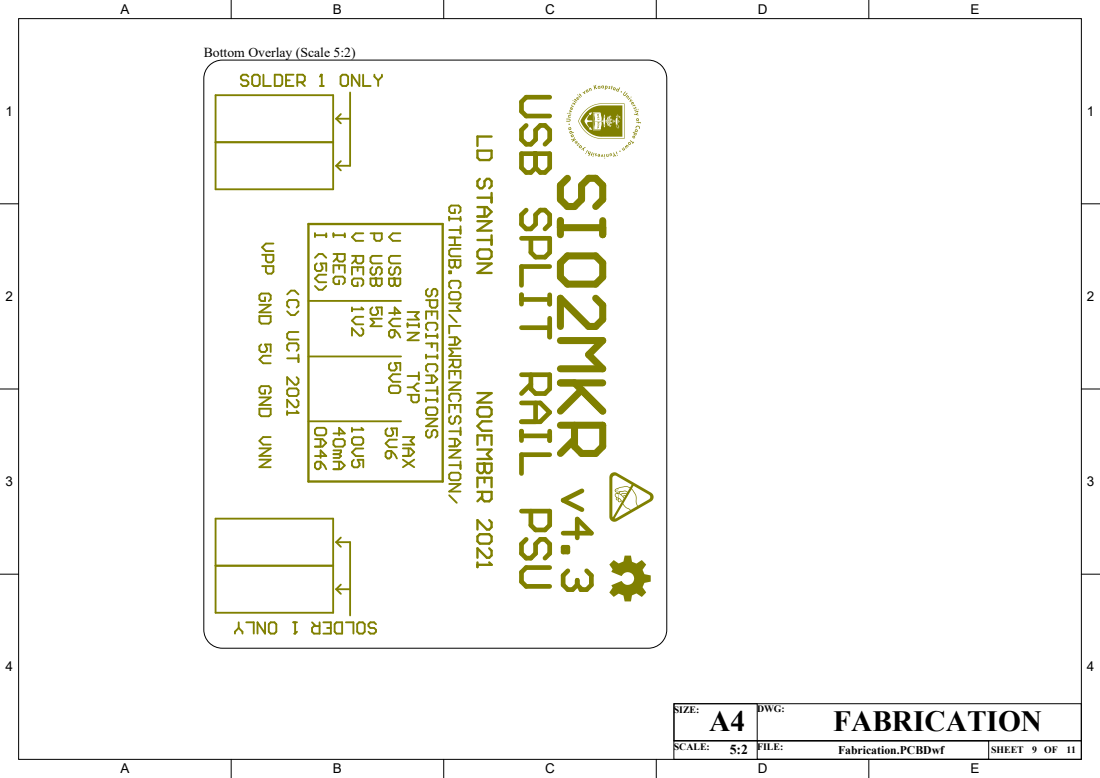
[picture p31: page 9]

SIZE: A4 | DWG: FABRICATION

Fabrication.PCBDwf | SHEET 9 OF 11

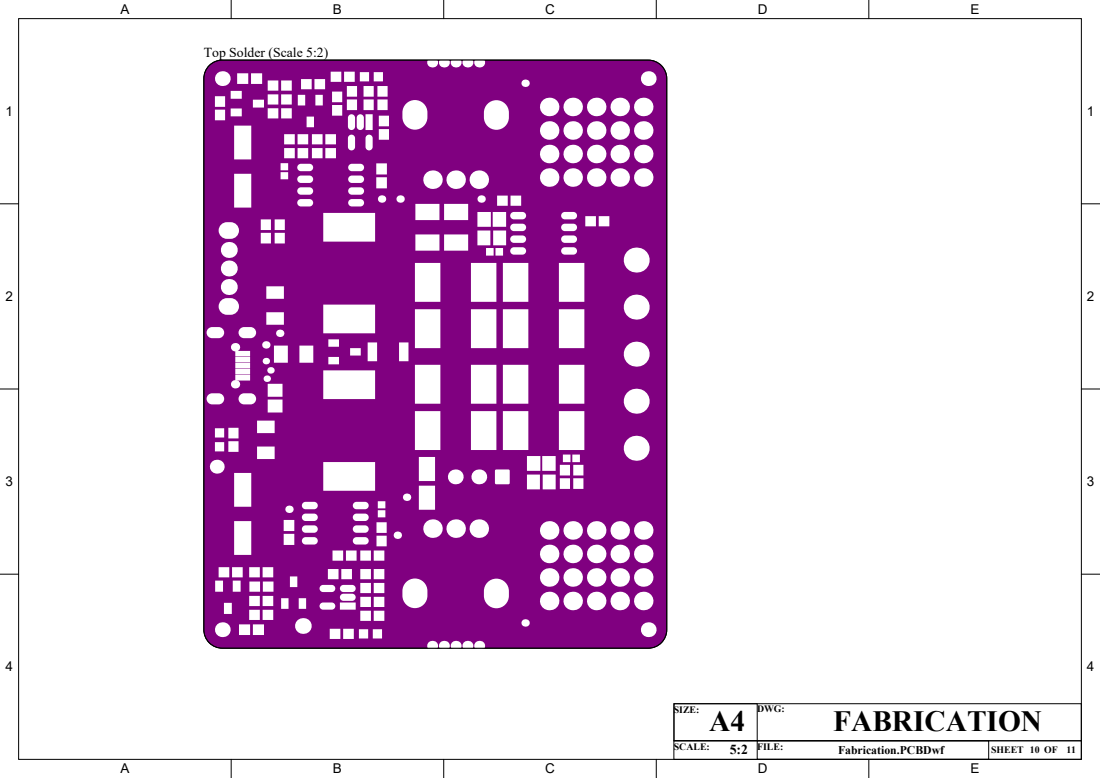
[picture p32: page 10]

SIZE: A4 | DWG: FABRICATION

Fabrication.PCBDwf | SHEET 10 OF 11

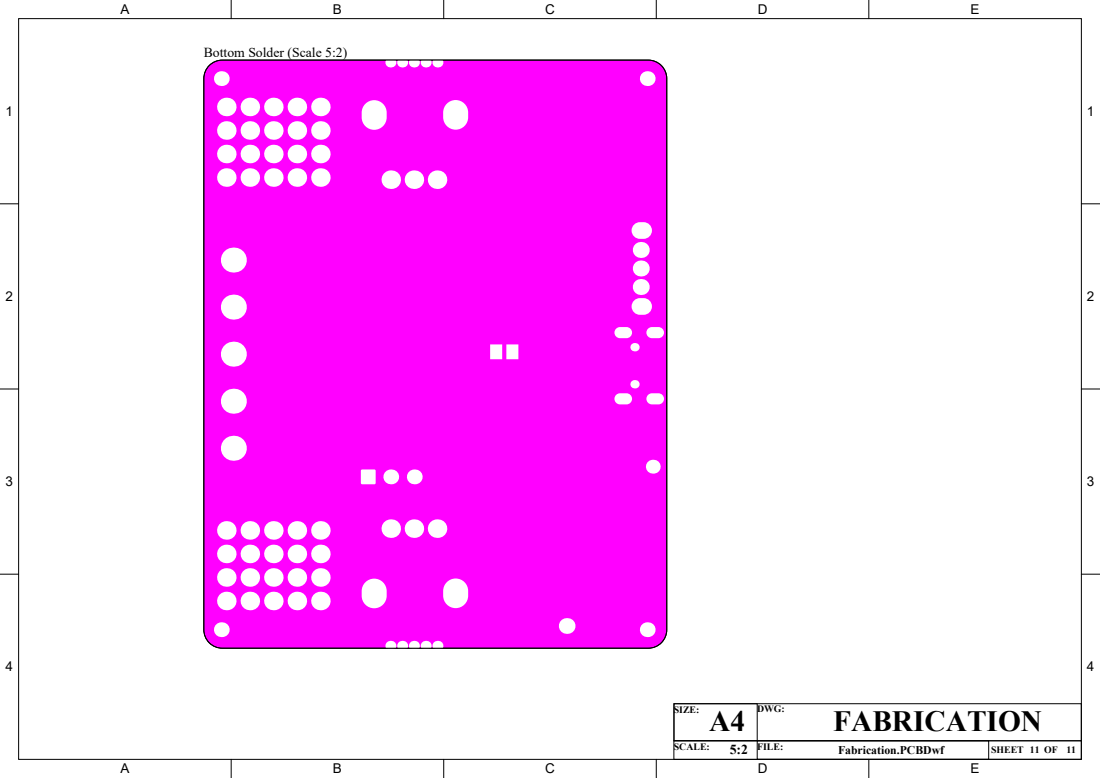
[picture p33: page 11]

SIZE: A4 | DWG: FABRICATION

Fabrication.PCBDwf | SHEET 11 OF 11

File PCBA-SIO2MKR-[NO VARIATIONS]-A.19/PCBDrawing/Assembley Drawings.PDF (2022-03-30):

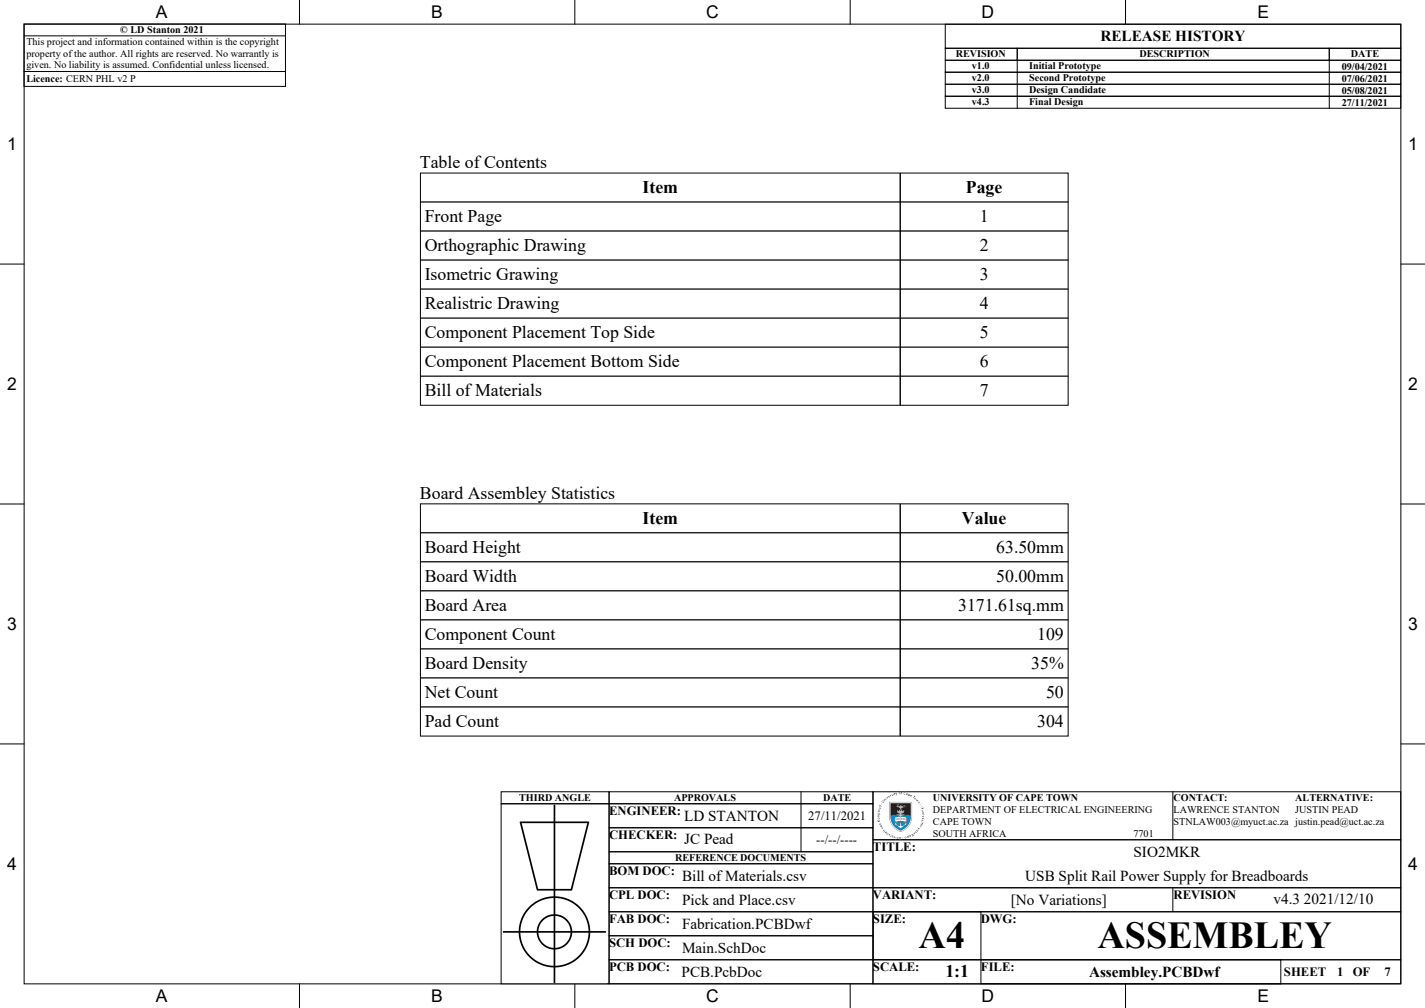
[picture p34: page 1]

This project and information contained within is the copyright
property of the author. All rights are reserved. No warrantly is
given. No liability is assumed. Confidential unless licensed.
Licence: CERN PHL v2 P

REVISION | DESCRIPTION | DATE
v1.0 | Initial Prototype | 09/04/2021

v3.0 | Design Candidate | 05/08/2021
v4.3 | Final Design | 27/11/2021

Item | Page

Front Page | 1
Orthographic Drawing | 2
Isometric Grawing | 3
Realistric Drawing | 4
Component Placement Top Side | 5
Component Placement Bottom Side | 6
Bill of Materials | 7

Item | Value

Board Height | 63.50mm
Board Width | 50.00mm
Board Area | 3171.61sq.mm
Component Count | 109
Board Density | 35%
Net Count | 50
Pad Count | 304

THIRD ANGLE | APPROVALS | DATE | UNIVERSITY OF CAPE TOWN DEPARTMENT OF ELECTRICAL ENGINEERING CAPE TOWN SOUTH AFRICA 7701 | CONTACT: ALTERNATIVE: LAWRENCE STANTON JUSTIN PEAD STNLAW003@myuct.ac.za justin.pead@uct.ac.za

ENGINEER: LD STANTON | 27/11/2021
CHECKER: JC Pead | --/--/----

REFERENCE DOCUMENTS
Bill of Materials.csv

USB Split Rail Power Supply for Breadboards

CPL DOC: Pick and Place.csv | VARIANT: [No Variations] | REVISION v4.3 2021/12/10
FAB DOC: Fabrication.PCBDwf | SIZE: A4 | DWG: ASSEMBLEY

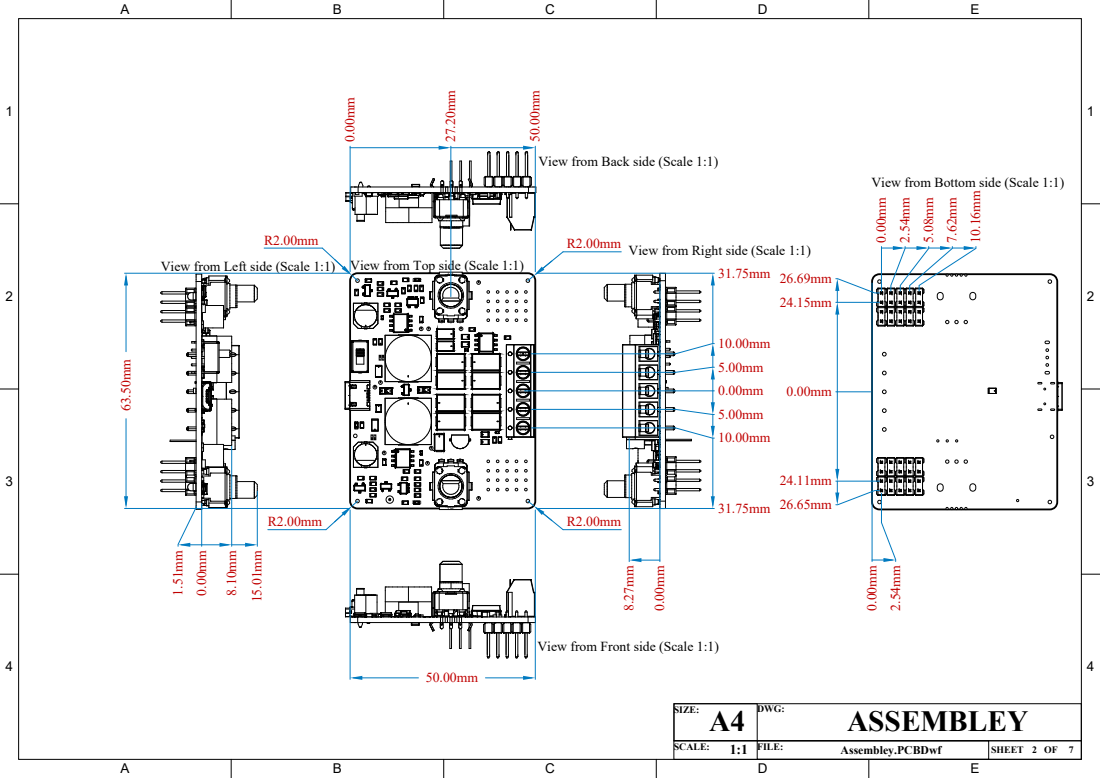
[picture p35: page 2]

View from Back side (Scale 1:1)

View from Bottom side (Scale 1:1)

View from Right side (Scale 1:1)

View from Left side (Scale 1:1)

View from Top side (Scale 1:1)

View from Front side (Scale 1:1)

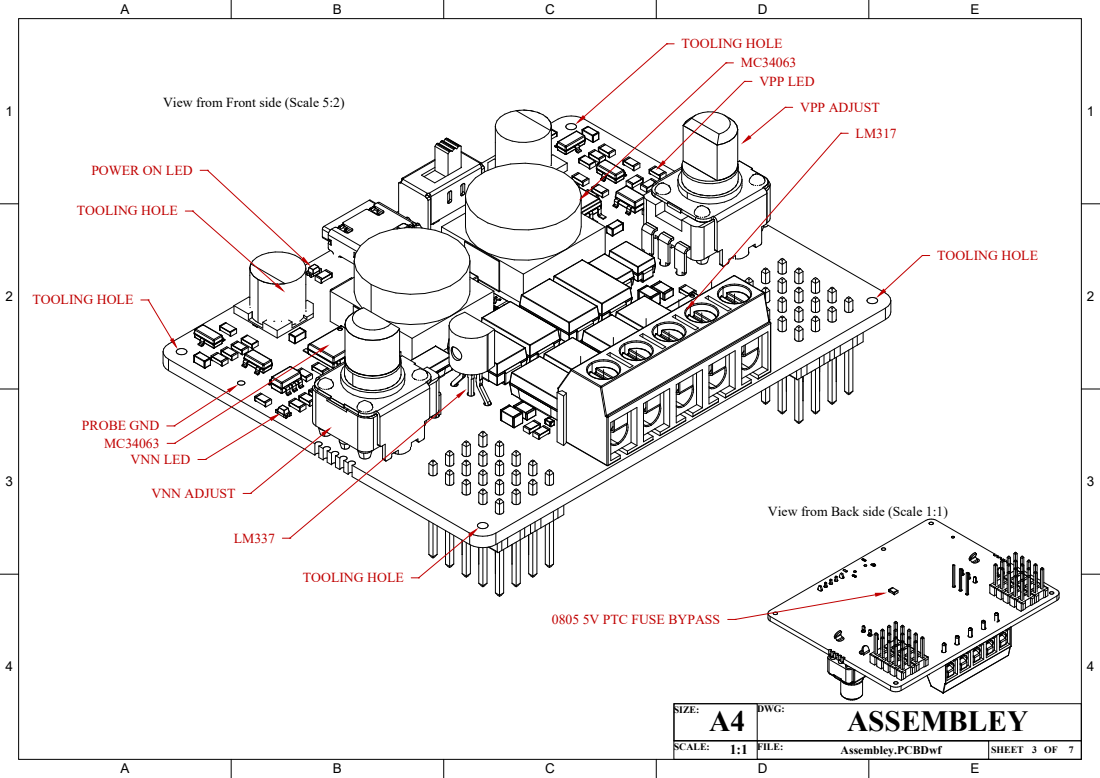
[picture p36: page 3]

View from Front side (Scale 5:2)

View from Back side (Scale 1:1)

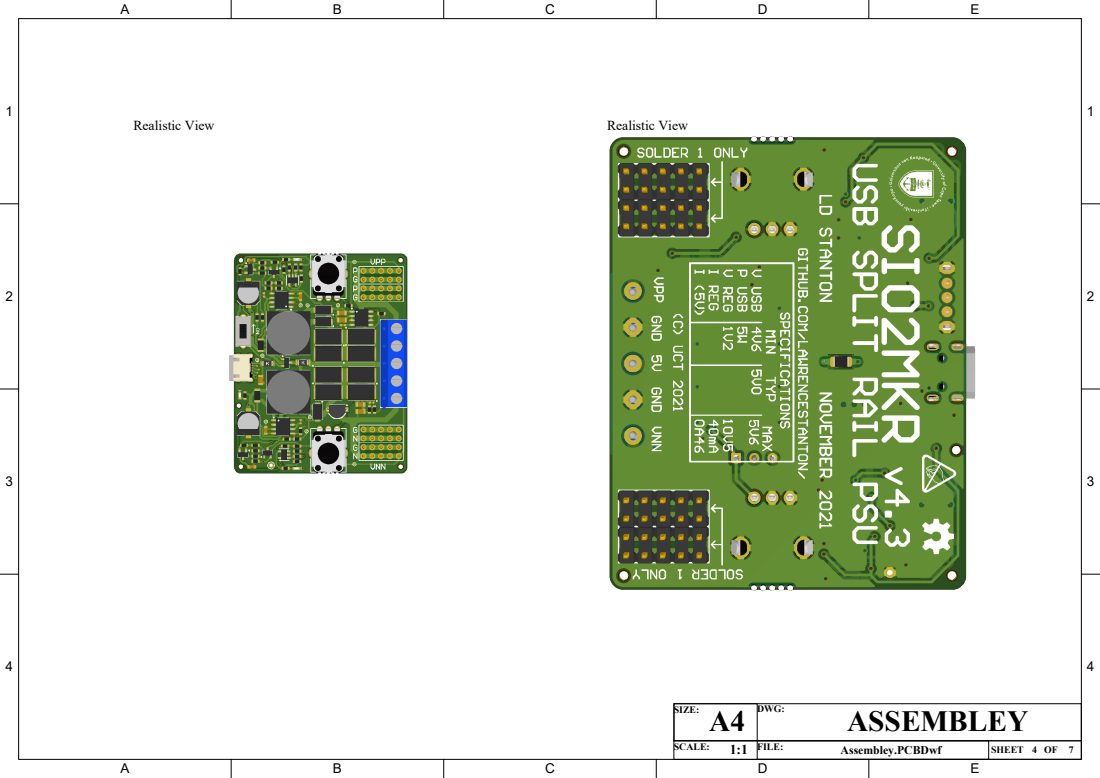
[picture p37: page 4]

SIZE: A4 | DWG: ASSEMBLEY

1:1 | FILE: Assembley.PCBDwf | SHEET 4 OF 7

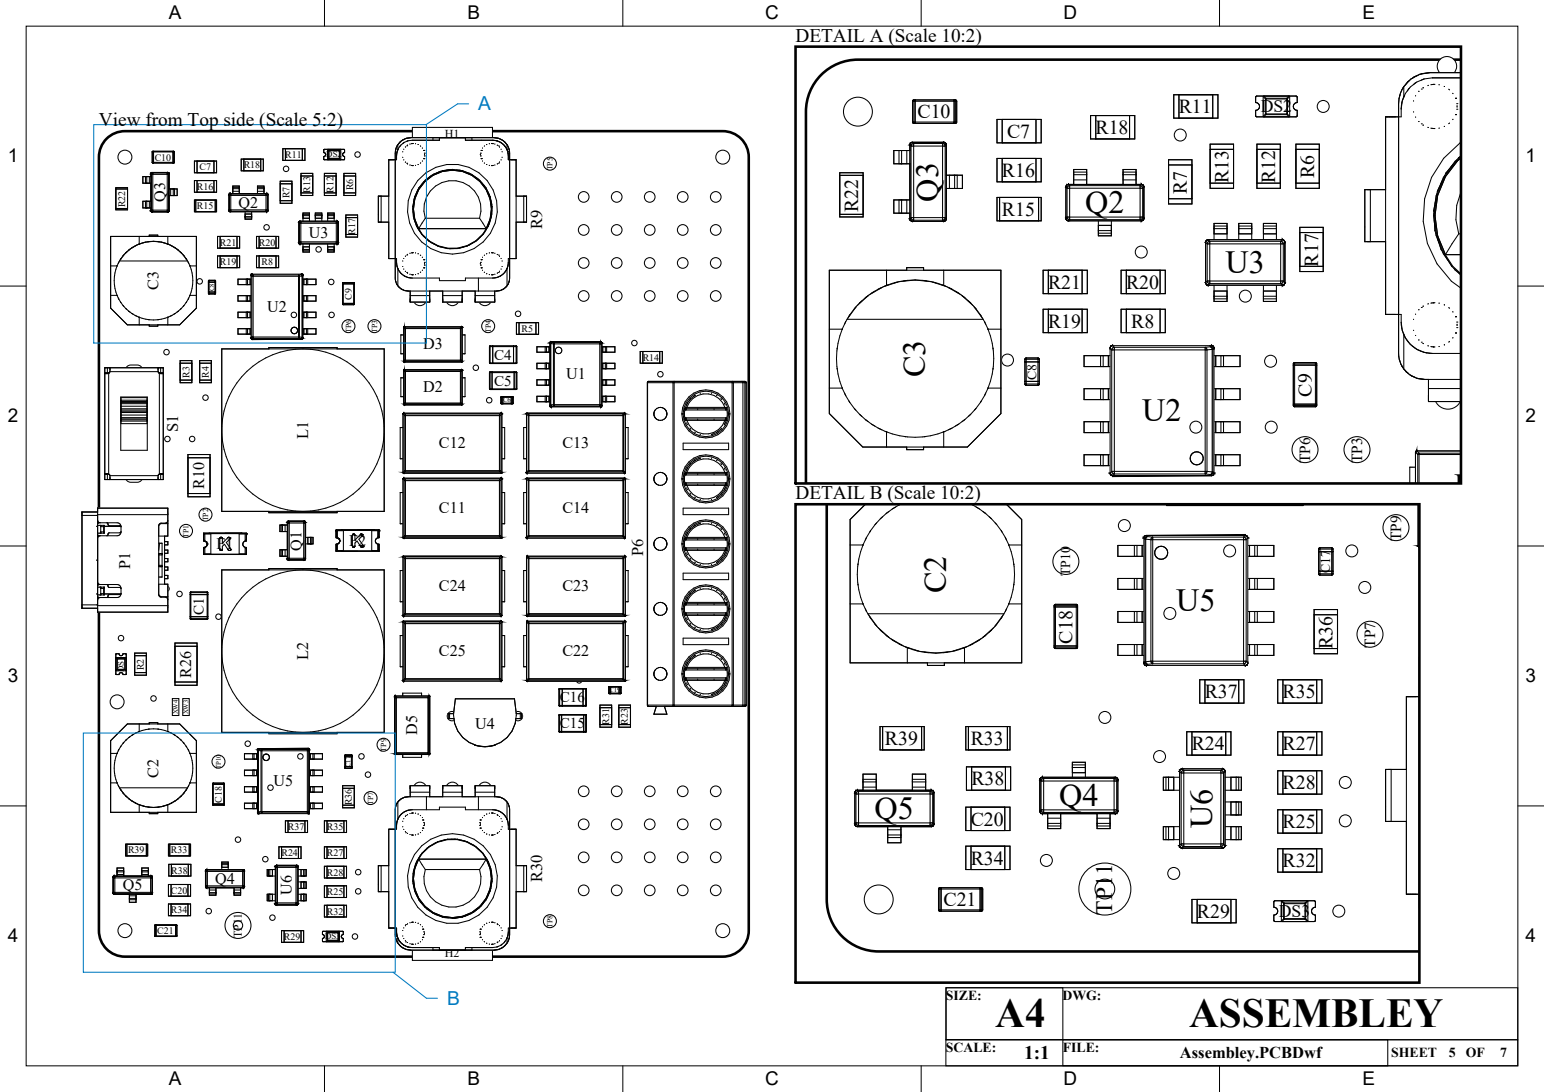
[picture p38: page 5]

View from Top side (Scale 5:2)

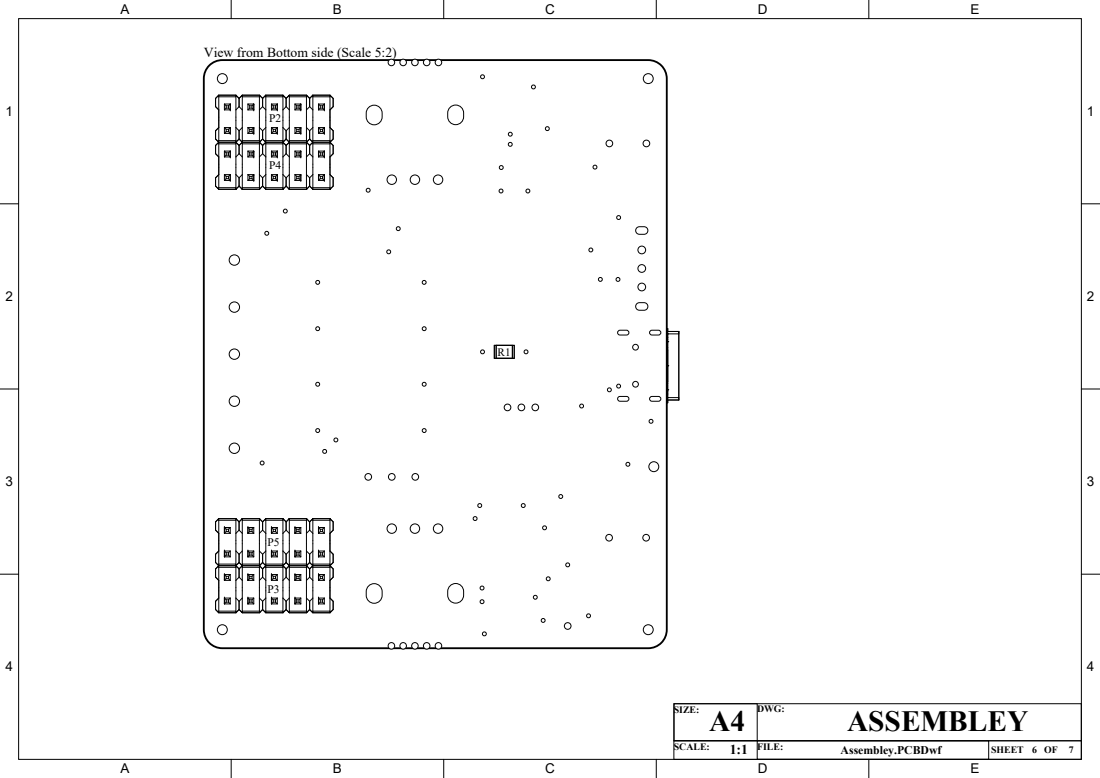
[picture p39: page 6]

View from Bottom side (Scale 5:2)

SIZE: A4 | DWG: ASSEMBLEY

1:1 | FILE: Assembley.PCBDwf | SHEET 6 OF 7

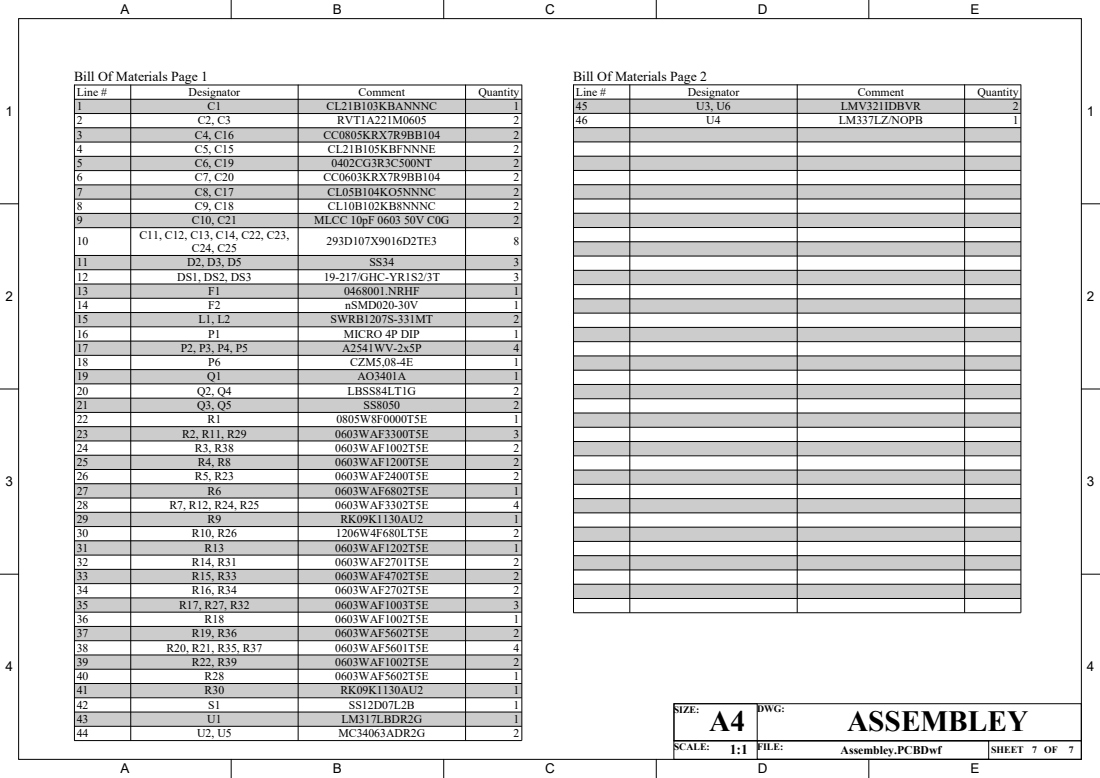
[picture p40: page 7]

3 | C4, C16 | CC0805KRX7R9BB104 | 2
4 | C5, C15 | CL21B105KBFNNNE | 2
5 | C6, C19 | 0402CG3R3C500NT | 2
6 | C7, C20 | CC0603KRX7R9BB104 | 2
7 | C8, C17 | CL05B104KO5NNNC | 2
8 | C9, C18 | CL10B102KB8NNNC | 2
9 | C10, C21 | MLCC 10pF 0603 50V C0G | 2
10 | C11, C12, C13, C14, C22, C23, C24, C25 | 293D107X9016D2TE3 | 8

11 | D2, D3, D5 | SS34 | 3
12 | DS1, DS2, DS3 | 19-217/GHC-YR1S2/3T | 3
13 | F1 | 0468001.NRHF | 1
14 | F2 | nSMD020-30V | 1
15 | L1, L2 | SWRB1207S-331MT | 2
16 | P1 | MICRO 4P DIP | 1
17 | P2, P3, P4, P5 | A2541WV-2x5P | 4
18 | P6 | CZM5,08-4E | 1
19 | Q1 | AO3401A | 1
20 | Q2, Q4 | LBSS84LT1G | 2
21 | Q3, Q5 | SS8050 | 2
22 | R1 | 0805W8F0000T5E | 1
23 | R2, R11, R29 | 0603WAF3300T5E | 3
24 | R3, R38 | 0603WAF1002T5E | 2
25 | R4, R8 | 0603WAF1200T5E | 2
26 | R5, R23 | 0603WAF2400T5E | 2
27 | R6 | 0603WAF6802T5E | 1
28 | R7, R12, R24, R25 | 0603WAF3302T5E | 4
29 | R9 | RK09K1130AU2 | 1
30 | R10, R26 | 1206W4F680LT5E | 2
31 | R13 | 0603WAF1202T5E | 1
32 | R14, R31 | 0603WAF2701T5E | 2
33 | R15, R33 | 0603WAF4702T5E | 2
34 | R16, R34 | 0603WAF2702T5E | 2
35 | R17, R27, R32 | 0603WAF1003T5E | 3
36 | R18 | 0603WAF1002T5E | 1
37 | R19, R36 | 0603WAF5602T5E | 2
38 | R20, R21, R35, R37 | 0603WAF5601T5E | 4
39 | R22, R39 | 0603WAF1002T5E | 2
40 | R28 | 0603WAF5602T5E | 1
41 | R30 | RK09K1130AU2 | 1
42 | S1 | SS12D07L2B | 1
43 | U1 | LM317LBDR2G | 1
44 | U2, U5 | MC34063ADR2G | 2

SIZE: A4 | DWG: ASSEMBLEY

1:1 | FILE: Assembley.PCBDwf | SHEET 7 OF 7

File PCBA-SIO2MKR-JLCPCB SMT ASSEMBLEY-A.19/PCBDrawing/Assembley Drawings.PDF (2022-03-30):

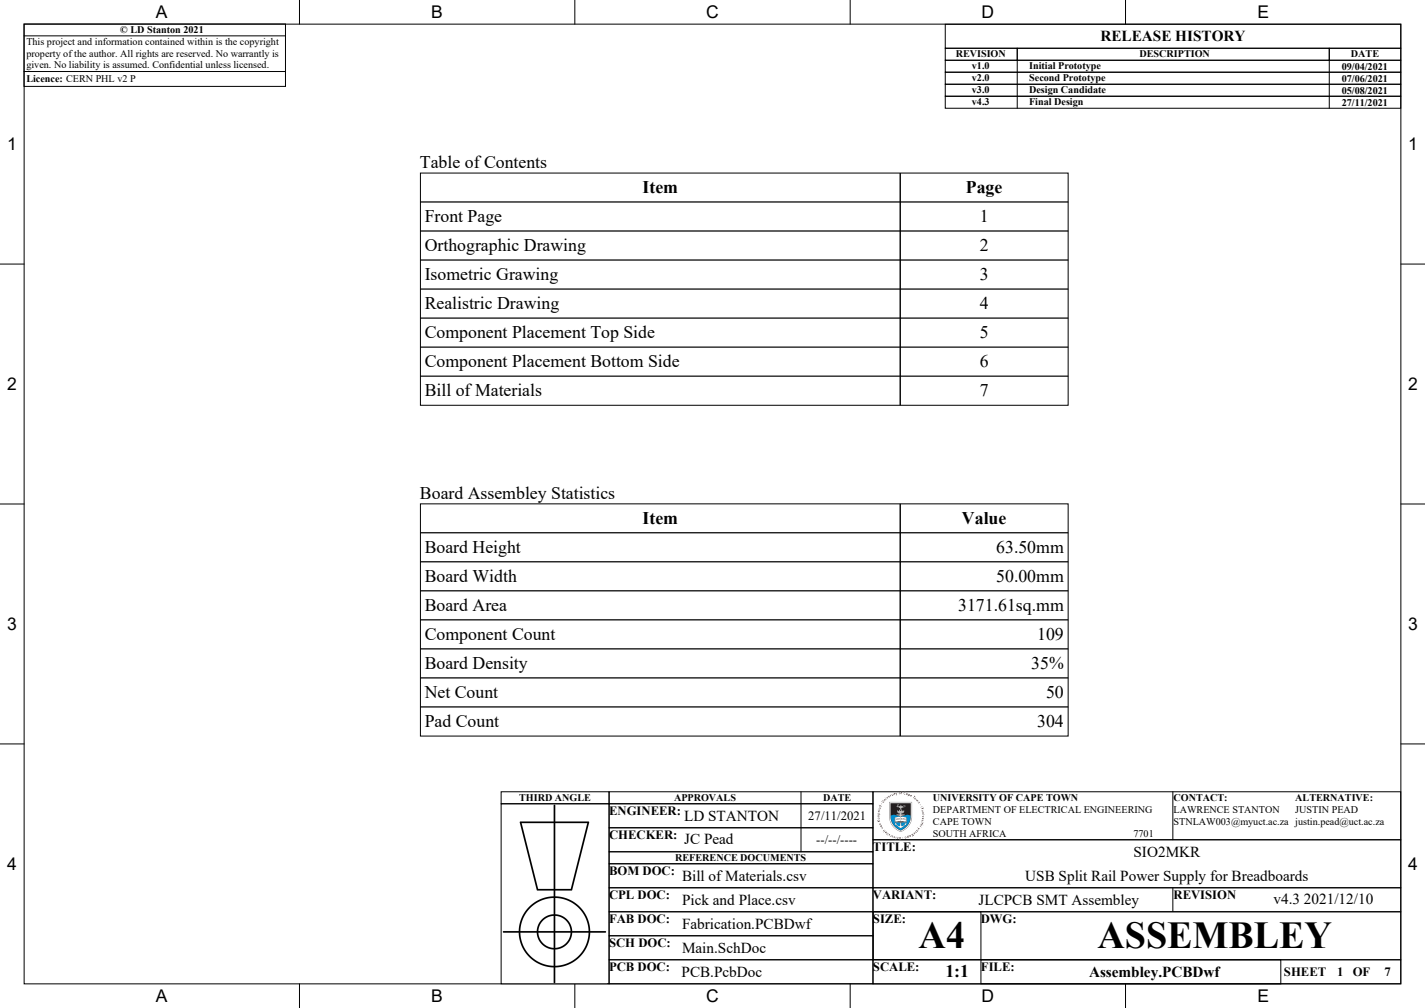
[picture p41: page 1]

This project and information contained within is the copyright
property of the author. All rights are reserved. No warrantly is
given. No liability is assumed. Confidential unless licensed.
Licence: CERN PHL v2 P

REVISION | DESCRIPTION | DATE
v1.0 | Initial Prototype | 09/04/2021

v3.0 | Design Candidate | 05/08/2021
v4.3 | Final Design | 27/11/2021

Item | Page

Front Page | 1
Orthographic Drawing | 2
Isometric Grawing | 3
Realistric Drawing | 4
Component Placement Top Side | 5
Component Placement Bottom Side | 6
Bill of Materials | 7

Item | Value

Board Height | 63.50mm
Board Width | 50.00mm
Board Area | 3171.61sq.mm
Component Count | 109
Board Density | 35%
Net Count | 50
Pad Count | 304

THIRD ANGLE | APPROVALS | DATE | UNIVERSITY OF CAPE TOWN DEPARTMENT OF ELECTRICAL ENGINEERING CAPE TOWN SOUTH AFRICA 7701 | CONTACT: ALTERNATIVE: LAWRENCE STANTON JUSTIN PEAD STNLAW003@myuct.ac.za justin.pead@uct.ac.za

ENGINEER: LD STANTON | 27/11/2021
CHECKER: JC Pead | --/--/----

REFERENCE DOCUMENTS
Bill of Materials.csv

USB Split Rail Power Supply for Breadboards

CPL DOC: Pick and Place.csv | VARIANT: JLCPCB SMT Assembley | REVISION v4.3 2021/12/10
FAB DOC: Fabrication.PCBDwf | SIZE: A4 | DWG: ASSEMBLEY

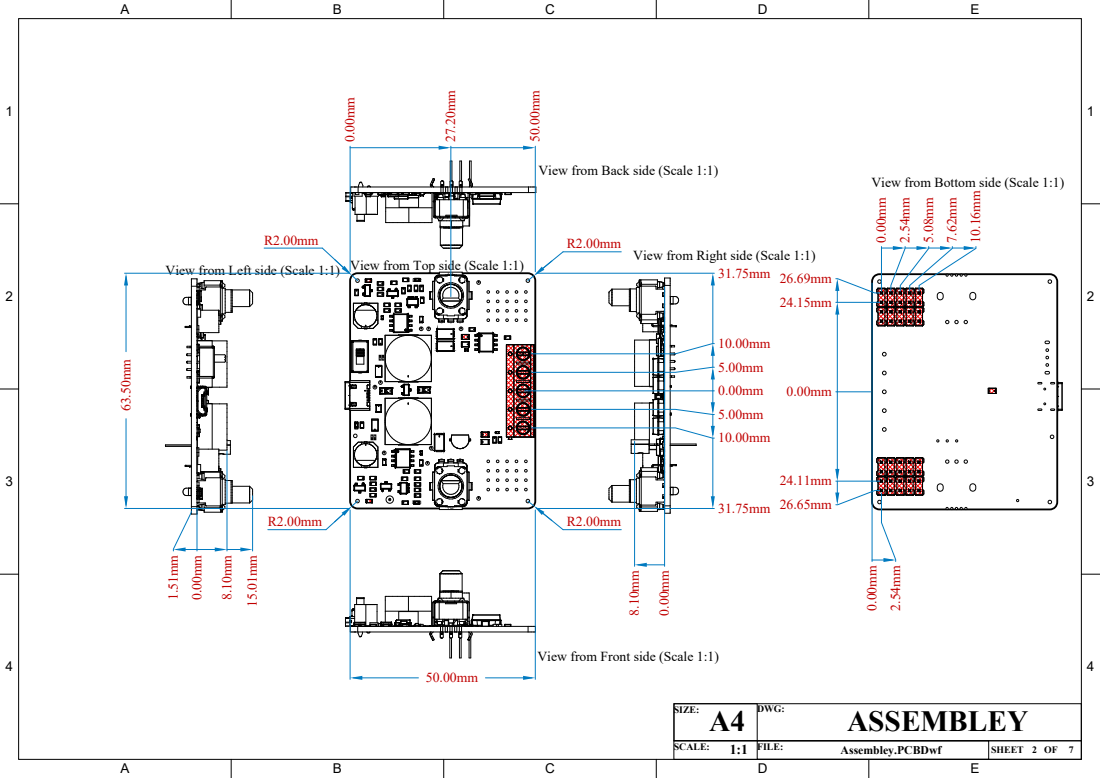
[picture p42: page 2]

View from Back side (Scale 1:1)

View from Bottom side (Scale 1:1)

View from Right side (Scale 1:1)

View from Left side (Scale 1:1)

View from Top side (Scale 1:1)

View from Front side (Scale 1:1)

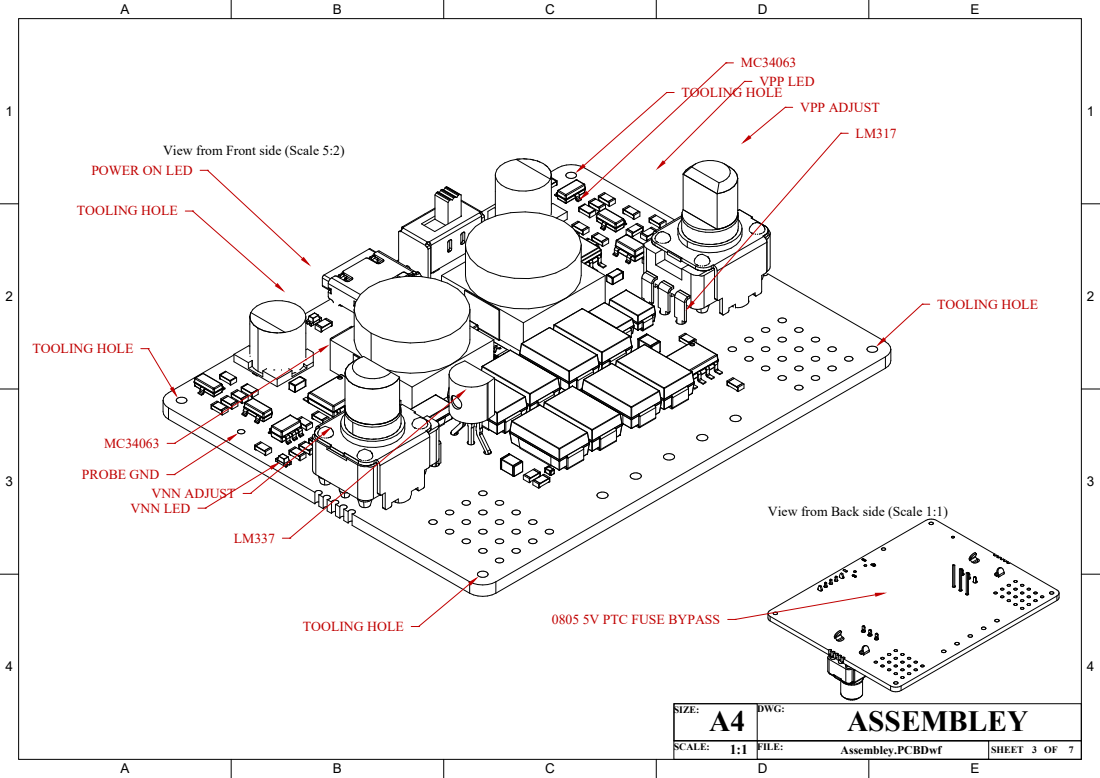
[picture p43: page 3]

View from Front side (Scale 5:2)

View from Back side (Scale 1:1)

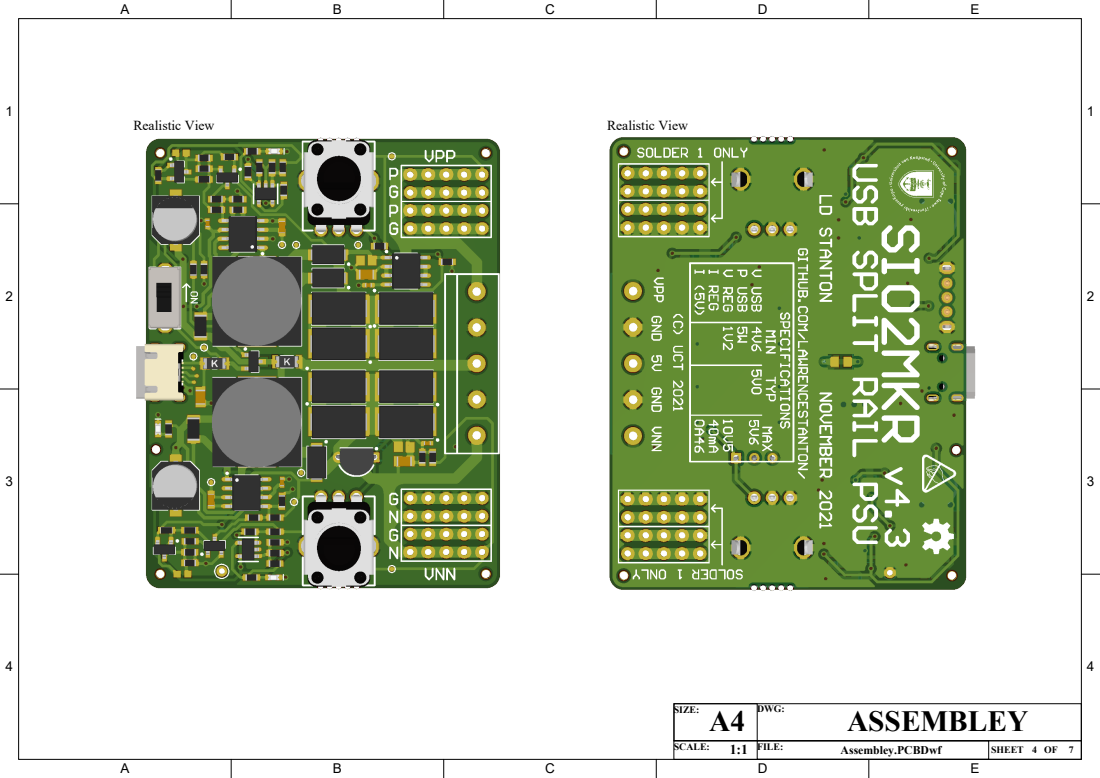
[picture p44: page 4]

SIZE: A4 | DWG: ASSEMBLEY

1:1 | FILE: Assembley.PCBDwf | SHEET 4 OF 7

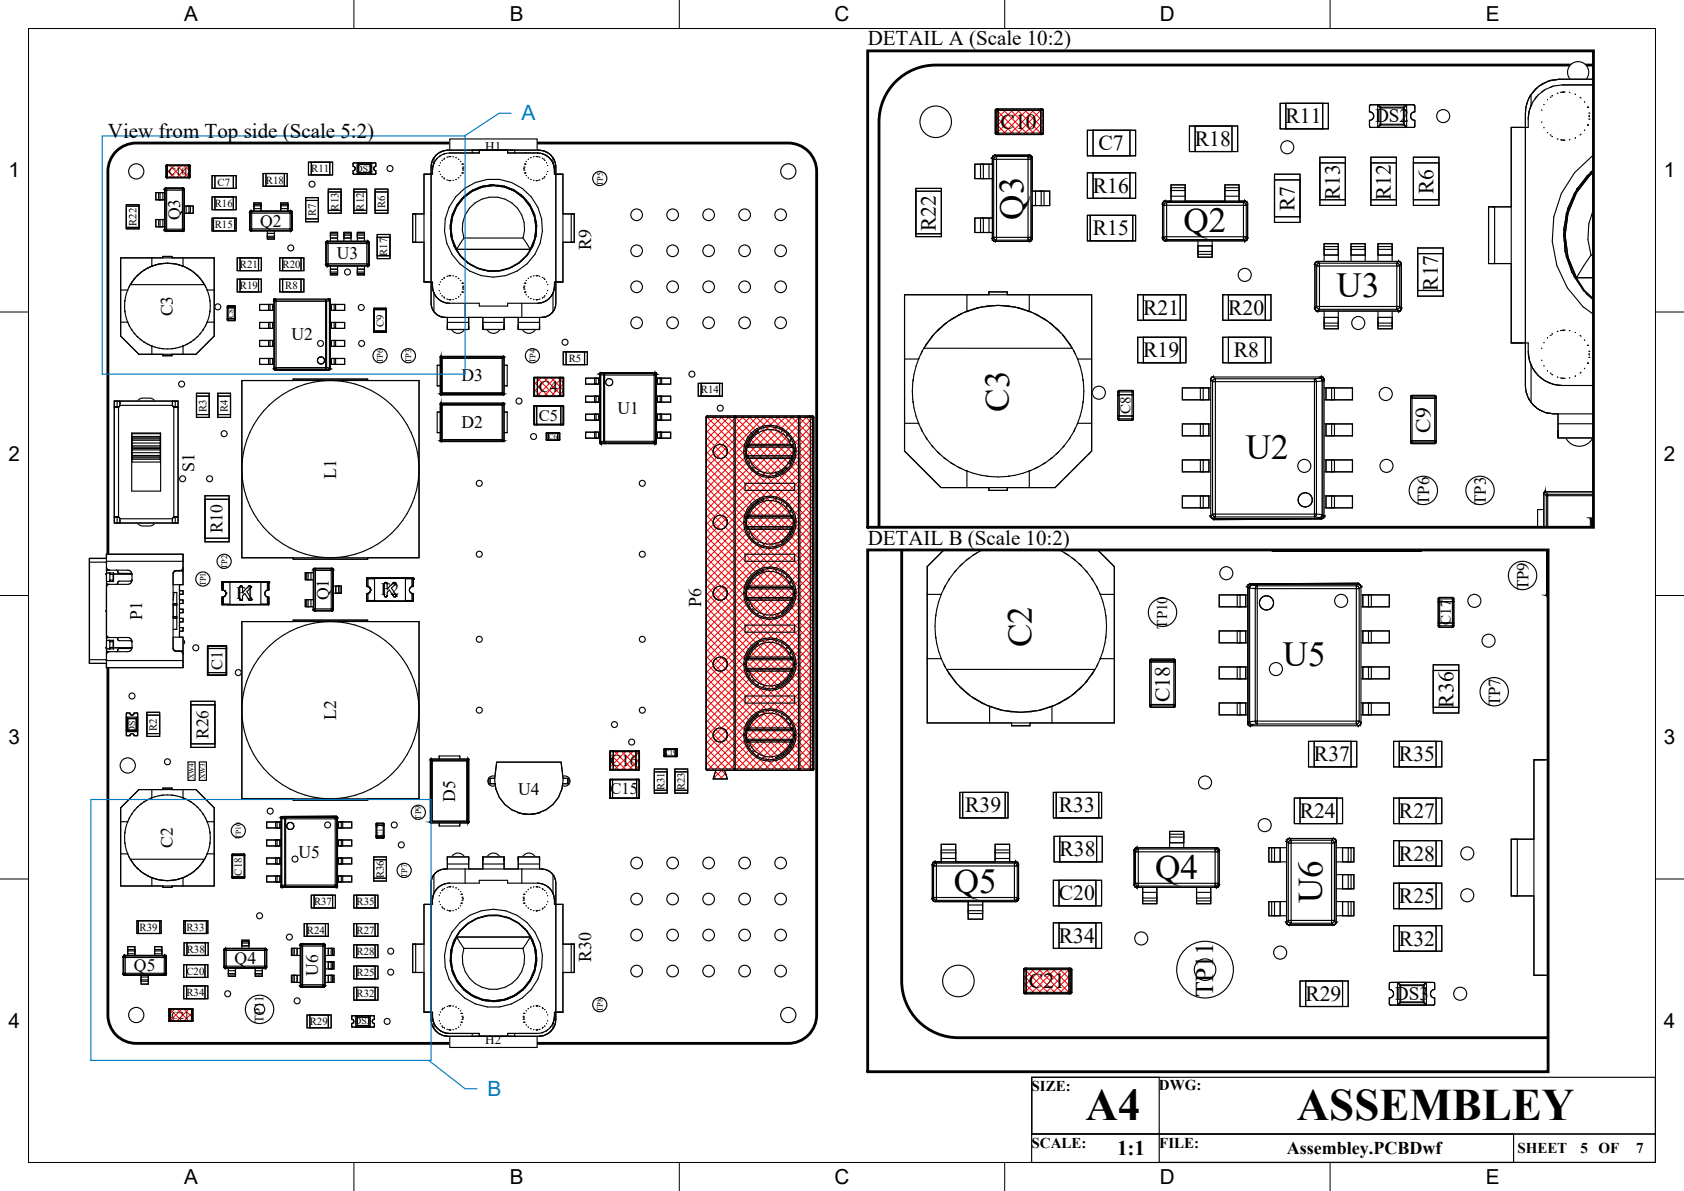
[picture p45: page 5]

View from Top side (Scale 5:2)

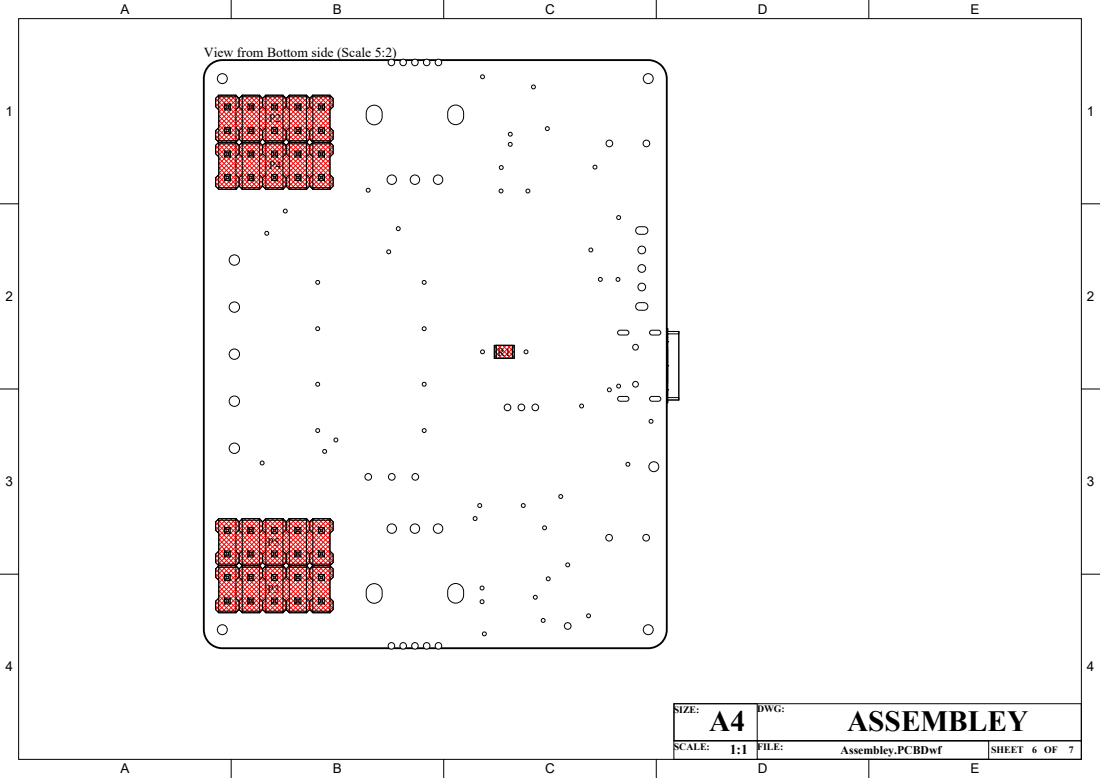
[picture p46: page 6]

View from Bottom side (Scale 5:2)

SIZE: A4 | DWG: ASSEMBLEY

1:1 | FILE: Assembley.PCBDwf | SHEET 6 OF 7

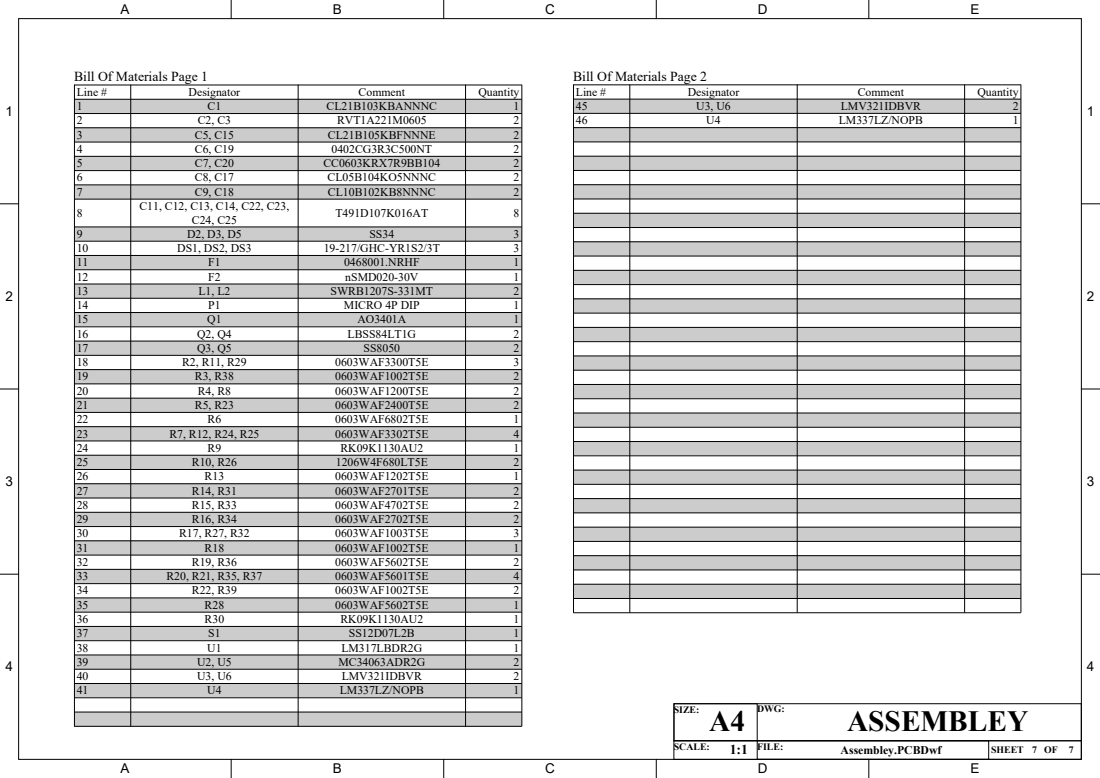
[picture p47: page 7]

3 | C5, C15 | CL21B105KBFNNNE | 2
4 | C6, C19 | 0402CG3R3C500NT | 2
5 | C7, C20 | CC0603KRX7R9BB104 | 2
6 | C8, C17 | CL05B104KO5NNNC | 2
7 | C9, C18 | CL10B102KB8NNNC | 2
8 | C11, C12, C13, C14, C22, C23, C24, C25 | T491D107K016AT | 8

9 | D2, D3, D5 | SS34 | 3
10 | DS1, DS2, DS3 | 19-217/GHC-YR1S2/3T | 3
11 | F1 | 0468001.NRHF | 1
12 | F2 | nSMD020-30V | 1
13 | L1, L2 | SWRB1207S-331MT | 2
14 | P1 | MICRO 4P DIP | 1
15 | Q1 | AO3401A | 1
16 | Q2, Q4 | LBSS84LT1G | 2
17 | Q3, Q5 | SS8050 | 2
18 | R2, R11, R29 | 0603WAF3300T5E | 3
19 | R3, R38 | 0603WAF1002T5E | 2
20 | R4, R8 | 0603WAF1200T5E | 2
21 | R5, R23 | 0603WAF2400T5E | 2
22 | R6 | 0603WAF6802T5E | 1
23 | R7, R12, R24, R25 | 0603WAF3302T5E | 4
24 | R9 | RK09K1130AU2 | 1
25 | R10, R26 | 1206W4F680LT5E | 2
26 | R13 | 0603WAF1202T5E | 1
27 | R14, R31 | 0603WAF2701T5E | 2
28 | R15, R33 | 0603WAF4702T5E | 2
29 | R16, R34 | 0603WAF2702T5E | 2
30 | R17, R27, R32 | 0603WAF1003T5E | 3
31 | R18 | 0603WAF1002T5E | 1
32 | R19, R36 | 0603WAF5602T5E | 2
33 | R20, R21, R35, R37 | 0603WAF5601T5E | 4
34 | R22, R39 | 0603WAF1002T5E | 2
35 | R28 | 0603WAF5602T5E | 1
36 | R30 | RK09K1130AU2 | 1
37 | S1 | SS12D07L2B | 1
38 | U1 | LM317LBDR2G | 1
39 | U2, U5 | MC34063ADR2G | 2
40 | U3, U6 | LMV321IDBVR | 2
41 | U4 | LM337LZ/NOPB | 1

SIZE: A4 | DWG: ASSEMBLEY

1:1 | FILE: Assembley.PCBDwf | SHEET 7 OF 7

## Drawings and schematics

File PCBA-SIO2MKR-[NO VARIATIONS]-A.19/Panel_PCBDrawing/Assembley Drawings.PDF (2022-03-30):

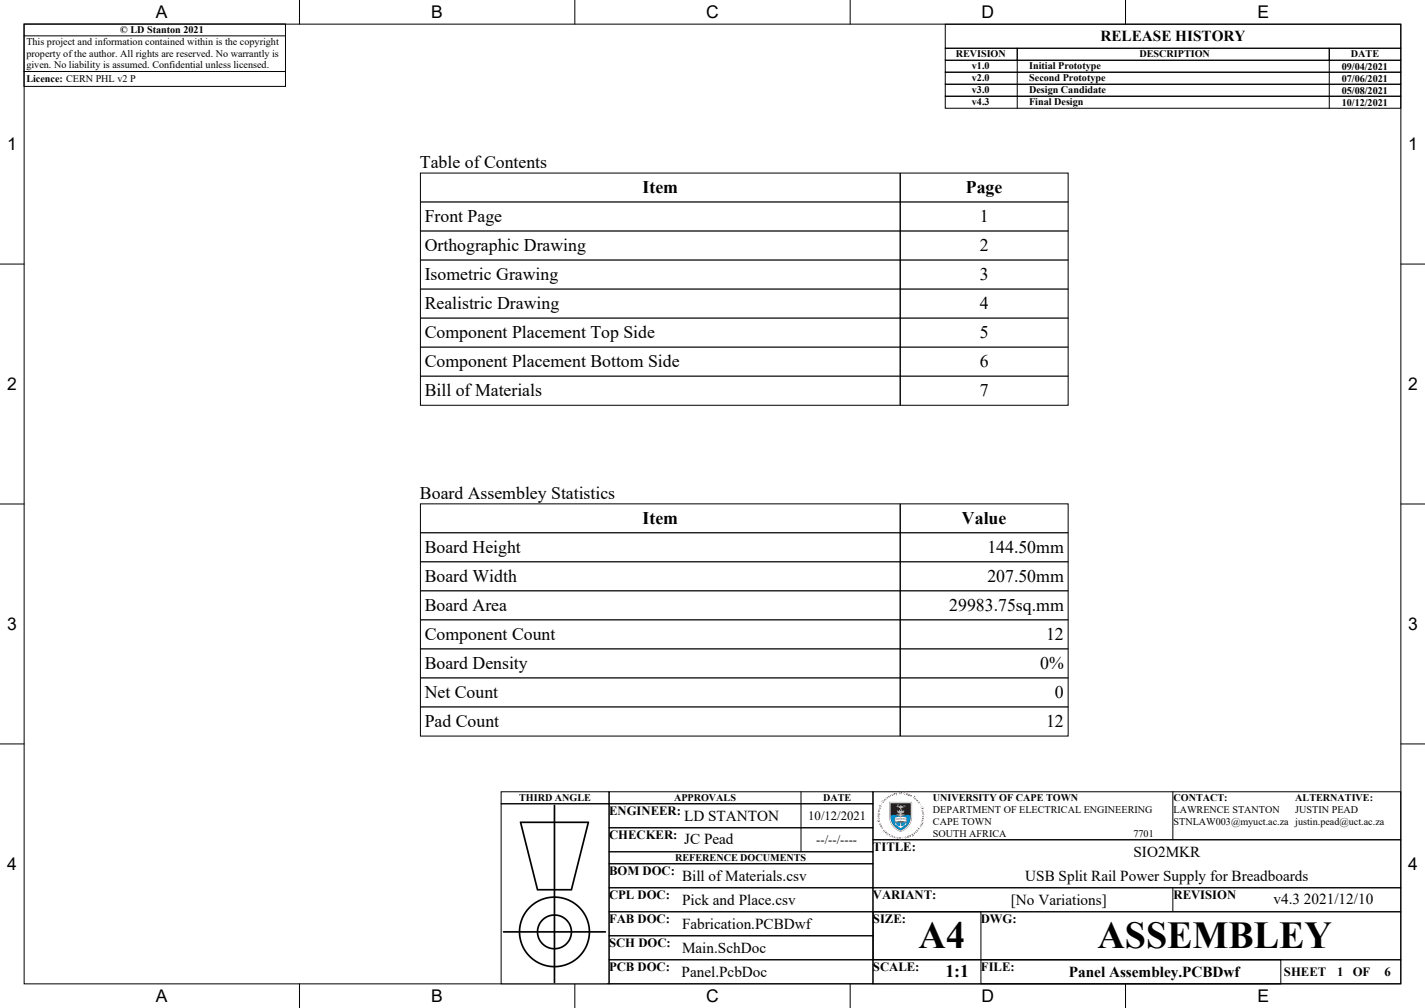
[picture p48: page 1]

This project and information contained within is the copyright
property of the author. All rights are reserved. No warrantly is
given. No liability is assumed. Confidential unless licensed.
Licence: CERN PHL v2 P

REVISION | DESCRIPTION | DATE
v1.0 | Initial Prototype | 09/04/2021

v3.0 | Design Candidate | 05/08/2021
v4.3 | Final Design | 10/12/2021

Item | Page

Front Page | 1
Orthographic Drawing | 2
Isometric Grawing | 3
Realistric Drawing | 4
Component Placement Top Side | 5
Component Placement Bottom Side | 6
Bill of Materials | 7

Item | Value

Board Height | 144.50mm
Board Width | 207.50mm
Board Area | 29983.75sq.mm
Component Count | 12
Board Density | 0%
Net Count | 0
Pad Count | 12

THIRD ANGLE | APPROVALS | DATE | UNIVERSITY OF CAPE TOWN DEPARTMENT OF ELECTRICAL ENGINEERING CAPE TOWN SOUTH AFRICA 7701 | CONTACT: ALTERNATIVE: LAWRENCE STANTON JUSTIN PEAD STNLAW003@myuct.ac.za justin.pead@uct.ac.za

ENGINEER: LD STANTON | 10/12/2021
CHECKER: JC Pead | --/--/----

REFERENCE DOCUMENTS
Bill of Materials.csv

USB Split Rail Power Supply for Breadboards

CPL DOC: Pick and Place.csv | VARIANT: [No Variations] | REVISION v4.3 2021/12/10
FAB DOC: Fabrication.PCBDwf | SIZE: A4 | DWG: ASSEMBLEY

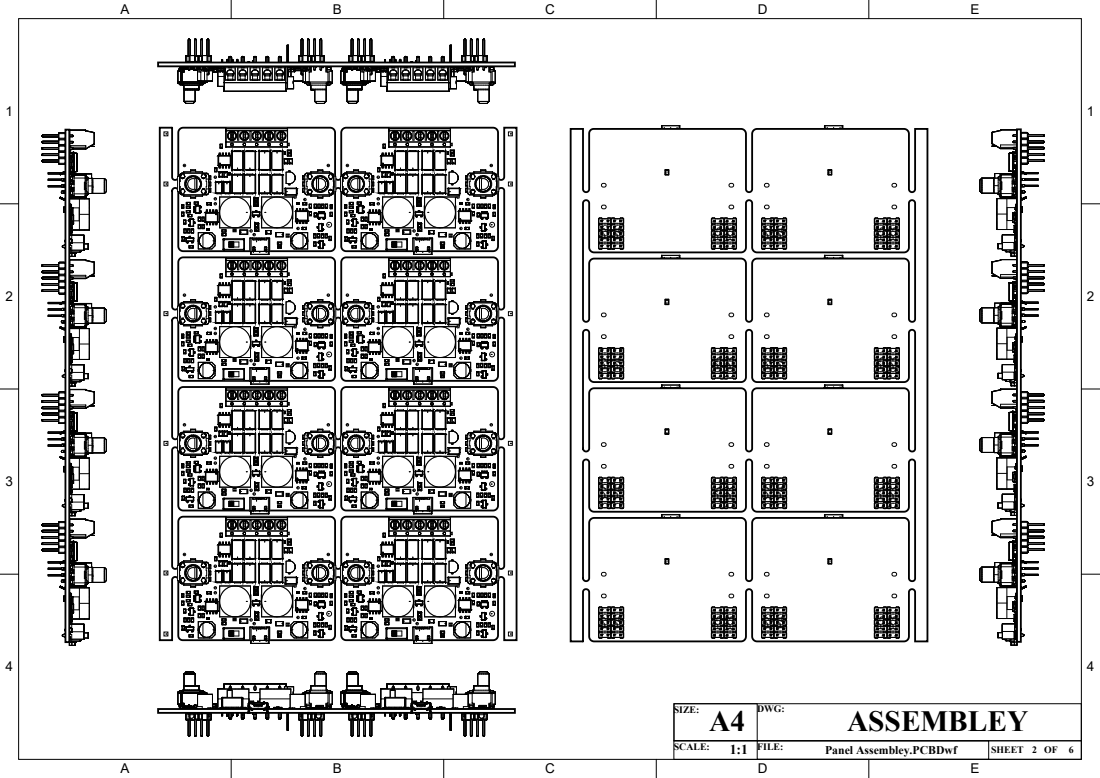
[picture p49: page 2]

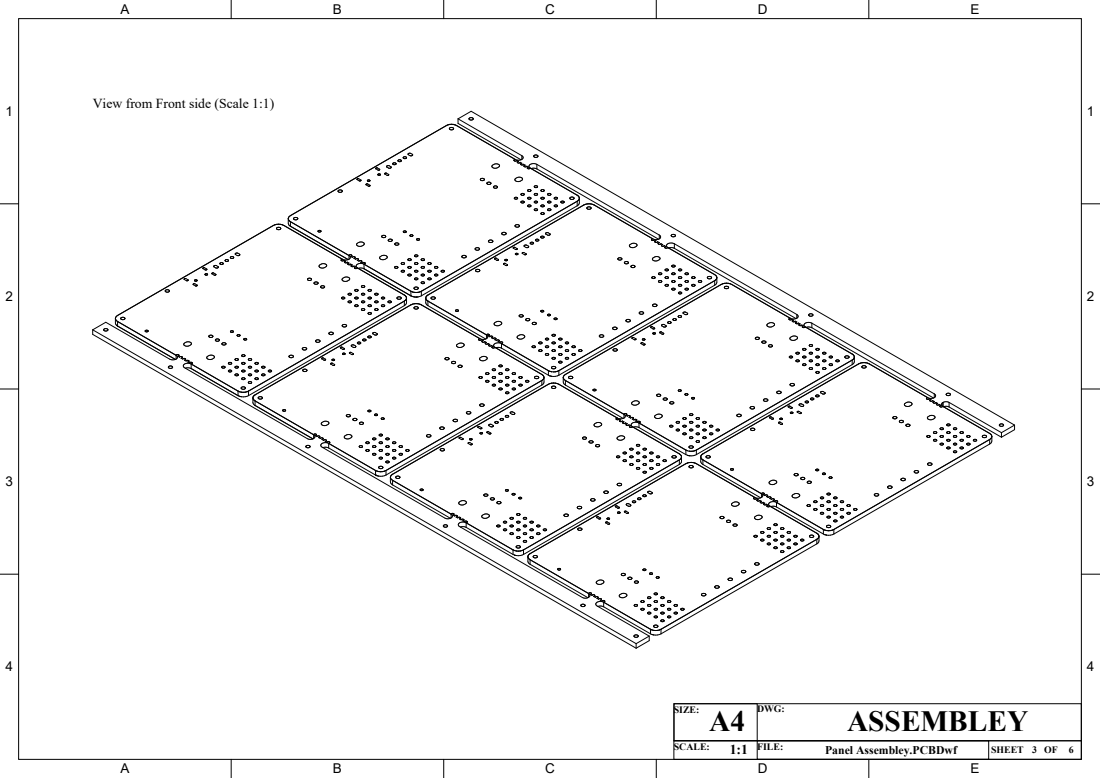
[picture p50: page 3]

View from Front side (Scale 1:1)

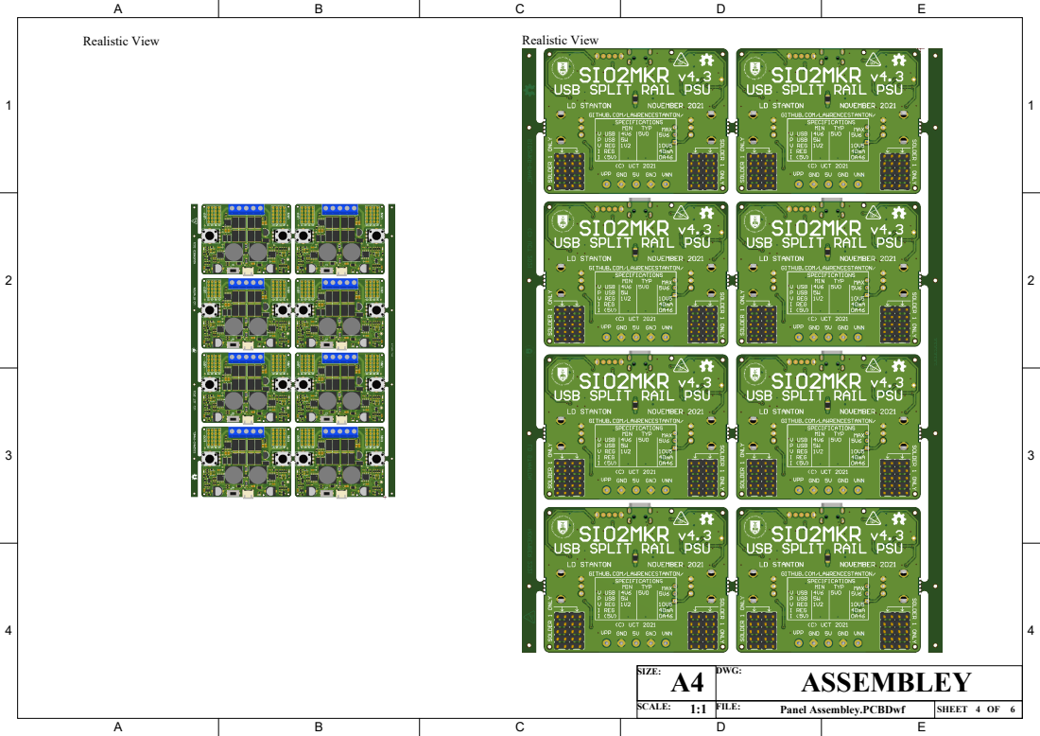
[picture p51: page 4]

SIZE: A4 | DWG: ASSEMBLEY

Panel Assembley.PCBDwf | SHEET 4 OF 6

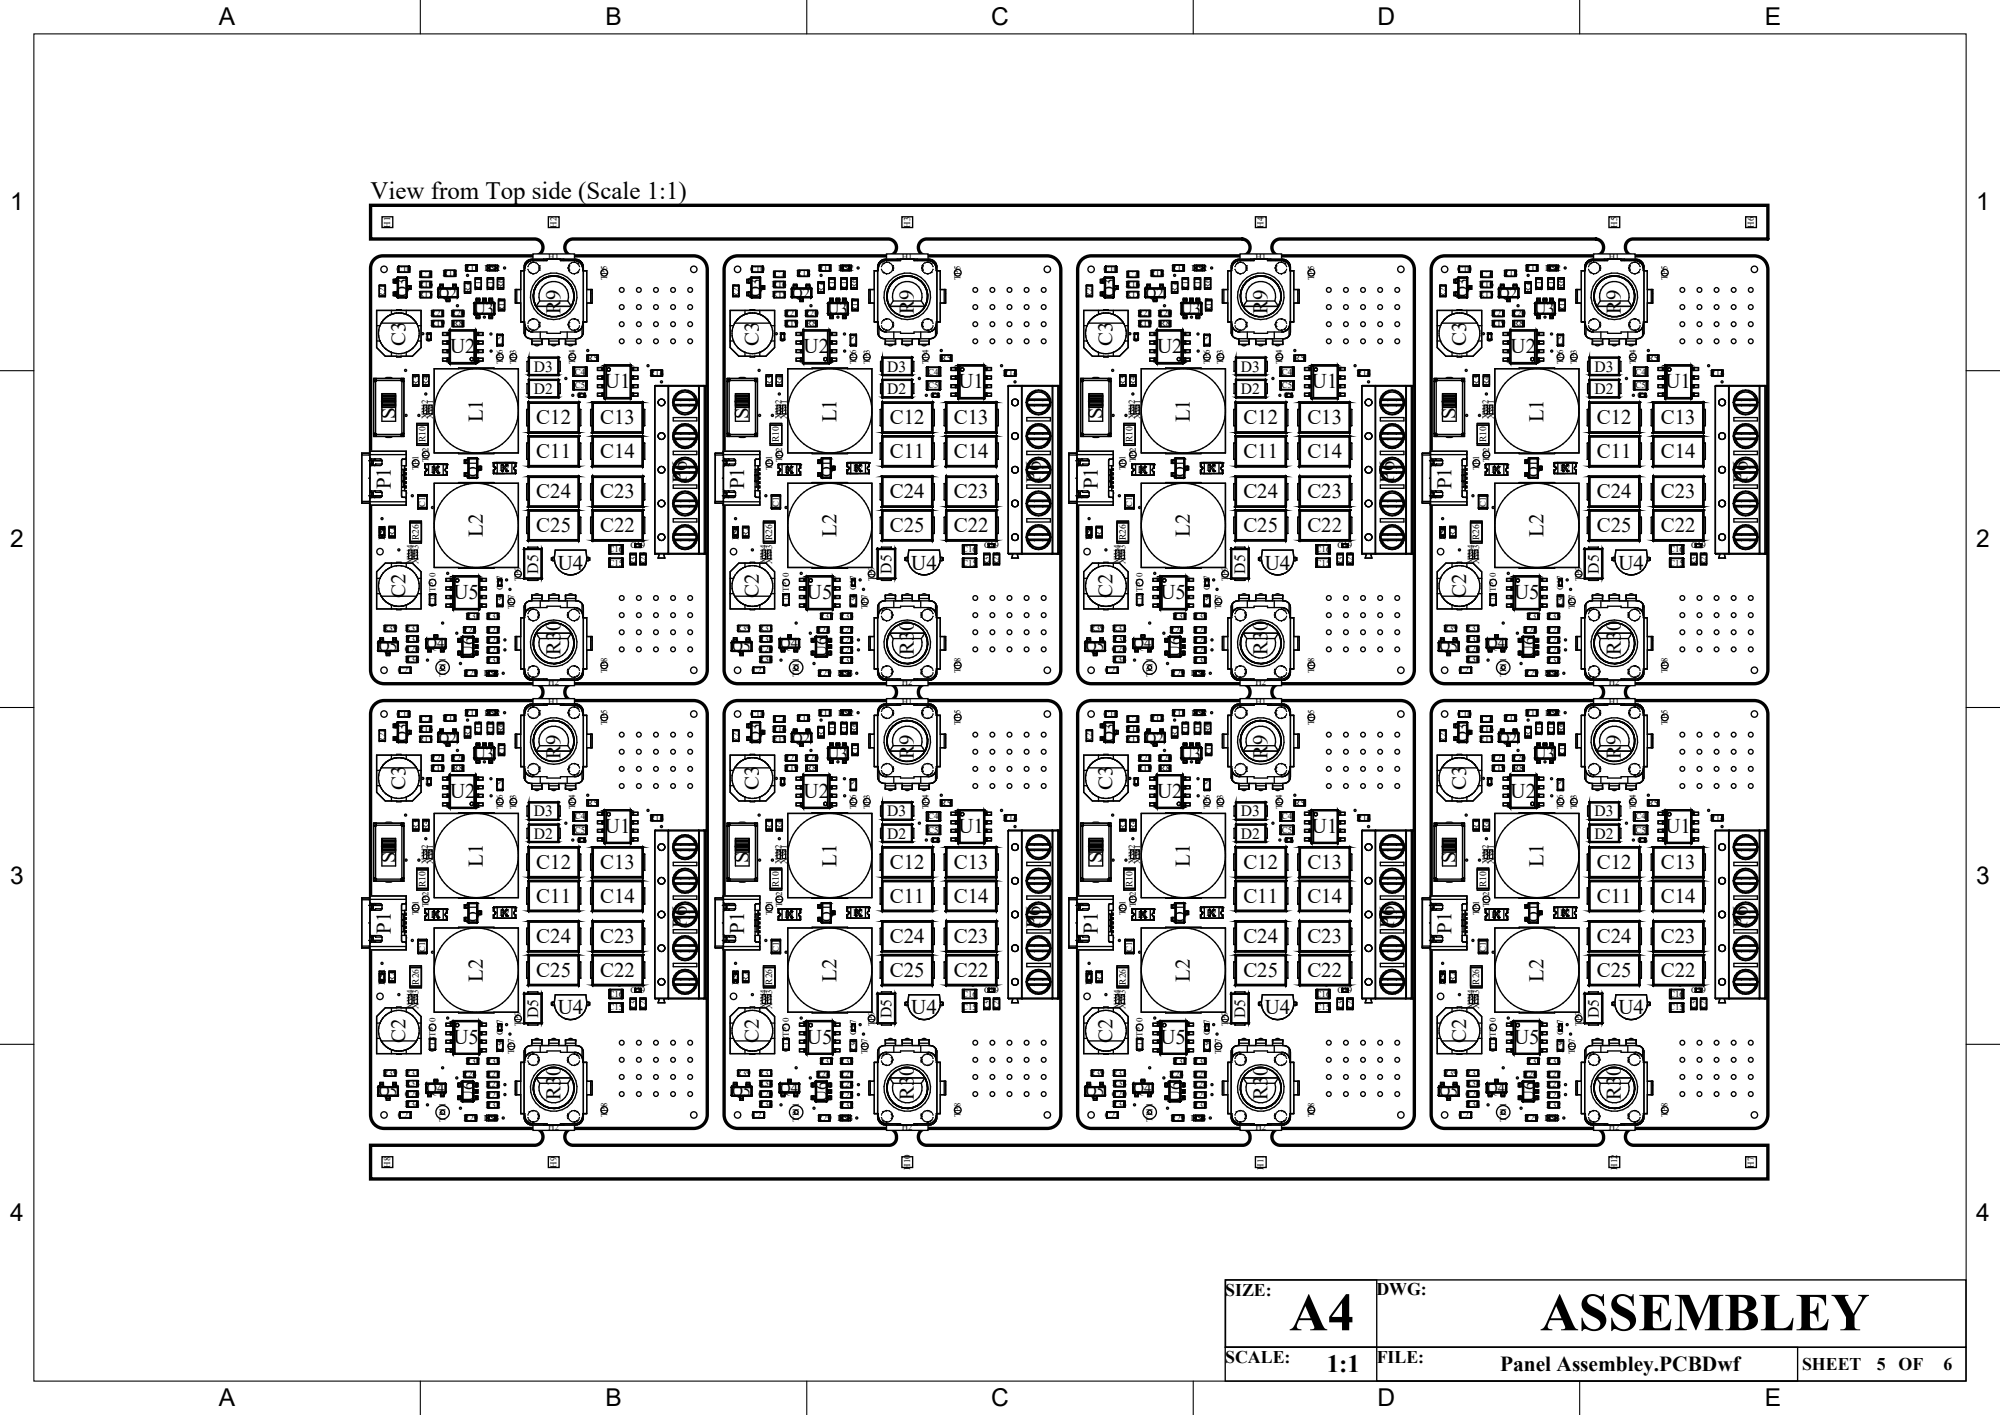
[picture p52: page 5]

View from Top side (Scale 1:1)

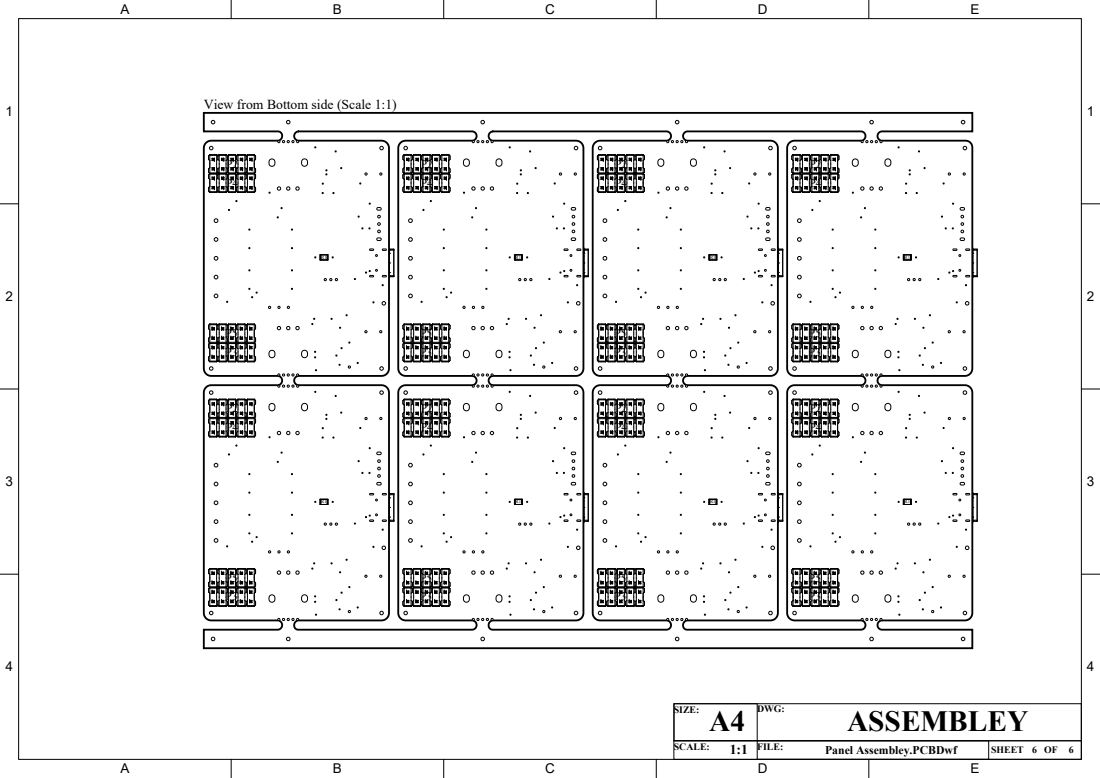
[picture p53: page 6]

View from Bottom side (Scale 1:1)

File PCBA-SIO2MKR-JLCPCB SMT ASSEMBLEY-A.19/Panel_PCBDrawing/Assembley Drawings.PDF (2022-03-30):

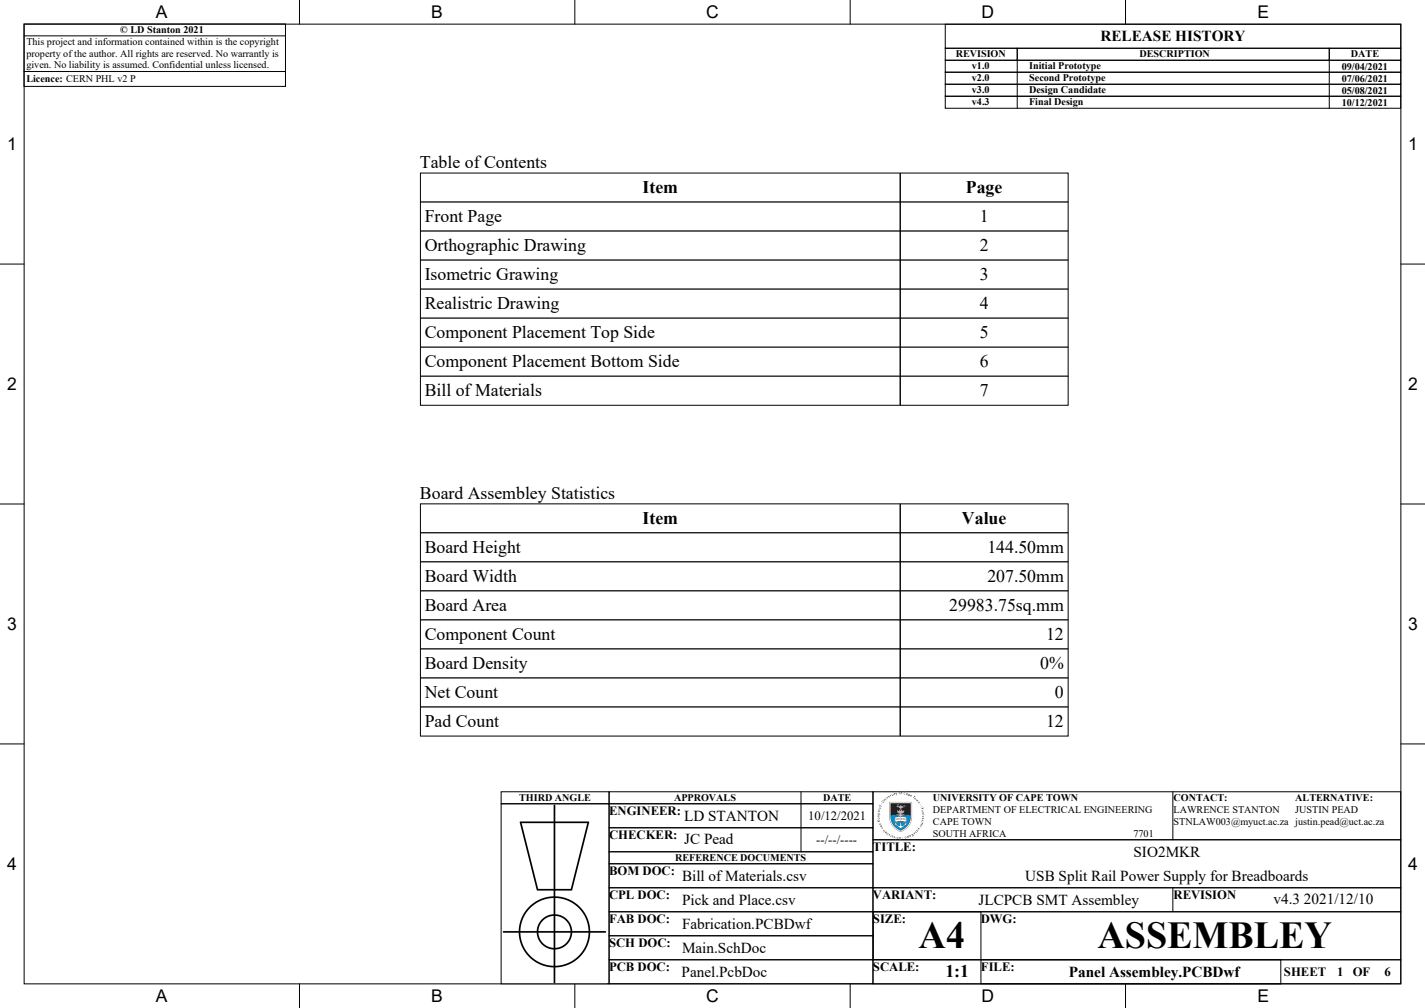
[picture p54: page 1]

This project and information contained within is the copyright
property of the author. All rights are reserved. No warrantly is
given. No liability is assumed. Confidential unless licensed.
Licence: CERN PHL v2 P

REVISION | DESCRIPTION | DATE
v1.0 | Initial Prototype | 09/04/2021

v3.0 | Design Candidate | 05/08/2021
v4.3 | Final Design | 10/12/2021

Item | Page

Front Page | 1
Orthographic Drawing | 2
Isometric Grawing | 3
Realistric Drawing | 4
Component Placement Top Side | 5
Component Placement Bottom Side | 6
Bill of Materials | 7

Item | Value

Board Height | 144.50mm
Board Width | 207.50mm
Board Area | 29983.75sq.mm
Component Count | 12
Board Density | 0%
Net Count | 0
Pad Count | 12

THIRD ANGLE | APPROVALS | DATE | UNIVERSITY OF CAPE TOWN DEPARTMENT OF ELECTRICAL ENGINEERING CAPE TOWN SOUTH AFRICA 7701 | CONTACT: ALTERNATIVE: LAWRENCE STANTON JUSTIN PEAD STNLAW003@myuct.ac.za justin.pead@uct.ac.za

ENGINEER: LD STANTON | 10/12/2021
CHECKER: JC Pead | --/--/----

REFERENCE DOCUMENTS
Bill of Materials.csv

USB Split Rail Power Supply for Breadboards

CPL DOC: Pick and Place.csv | VARIANT: JLCPCB SMT Assembley | REVISION v4.3 2021/12/10
FAB DOC: Fabrication.PCBDwf | SIZE: A4 | DWG: ASSEMBLEY

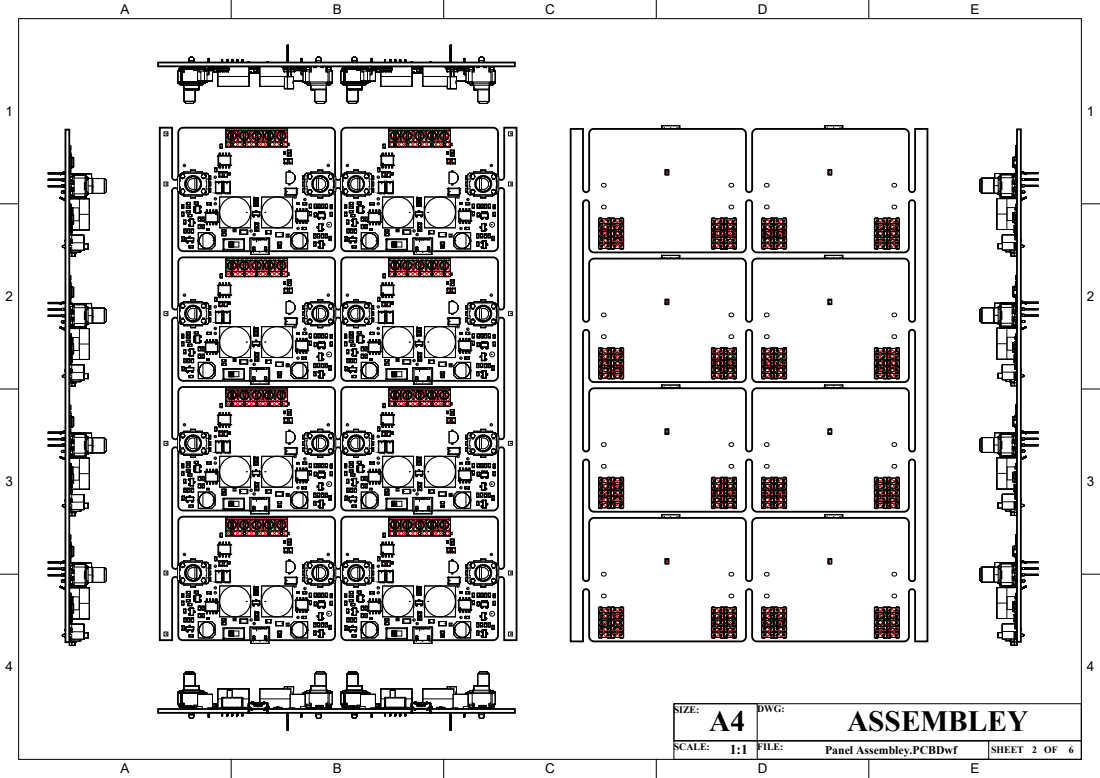
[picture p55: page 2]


View from Front side (Scale 1:1)

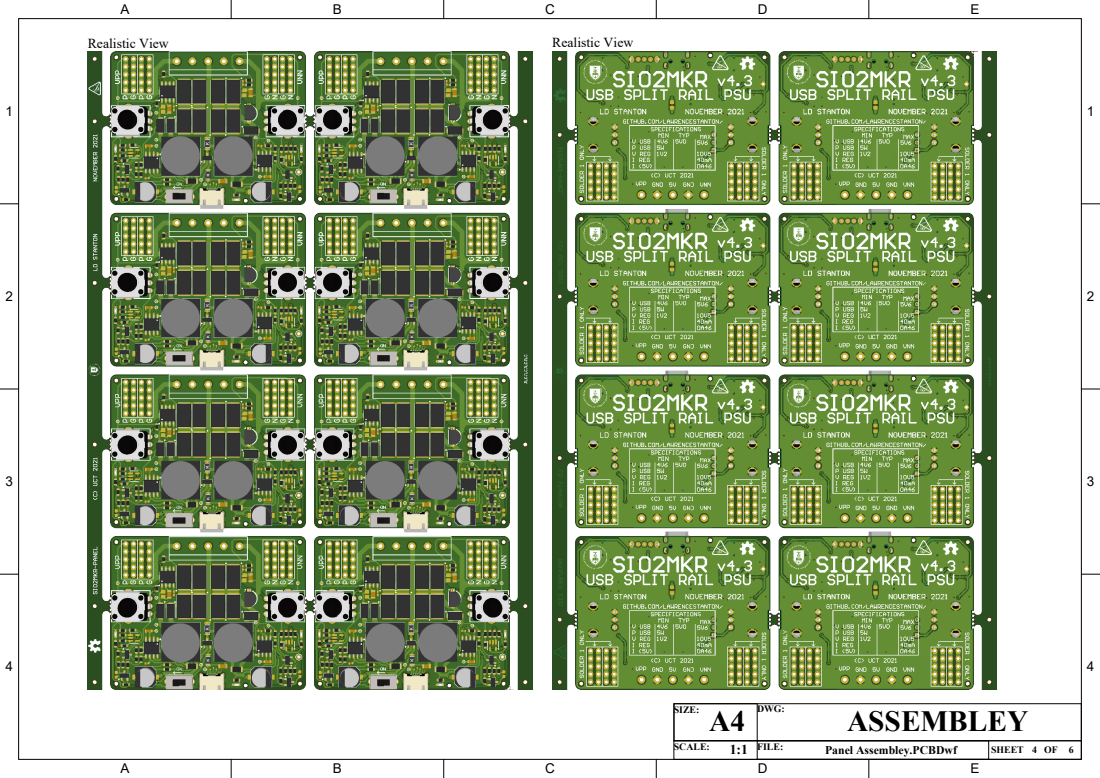
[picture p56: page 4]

SIZE: A4 | DWG: ASSEMBLEY

Panel Assembley.PCBDwf | SHEET 4 OF 6

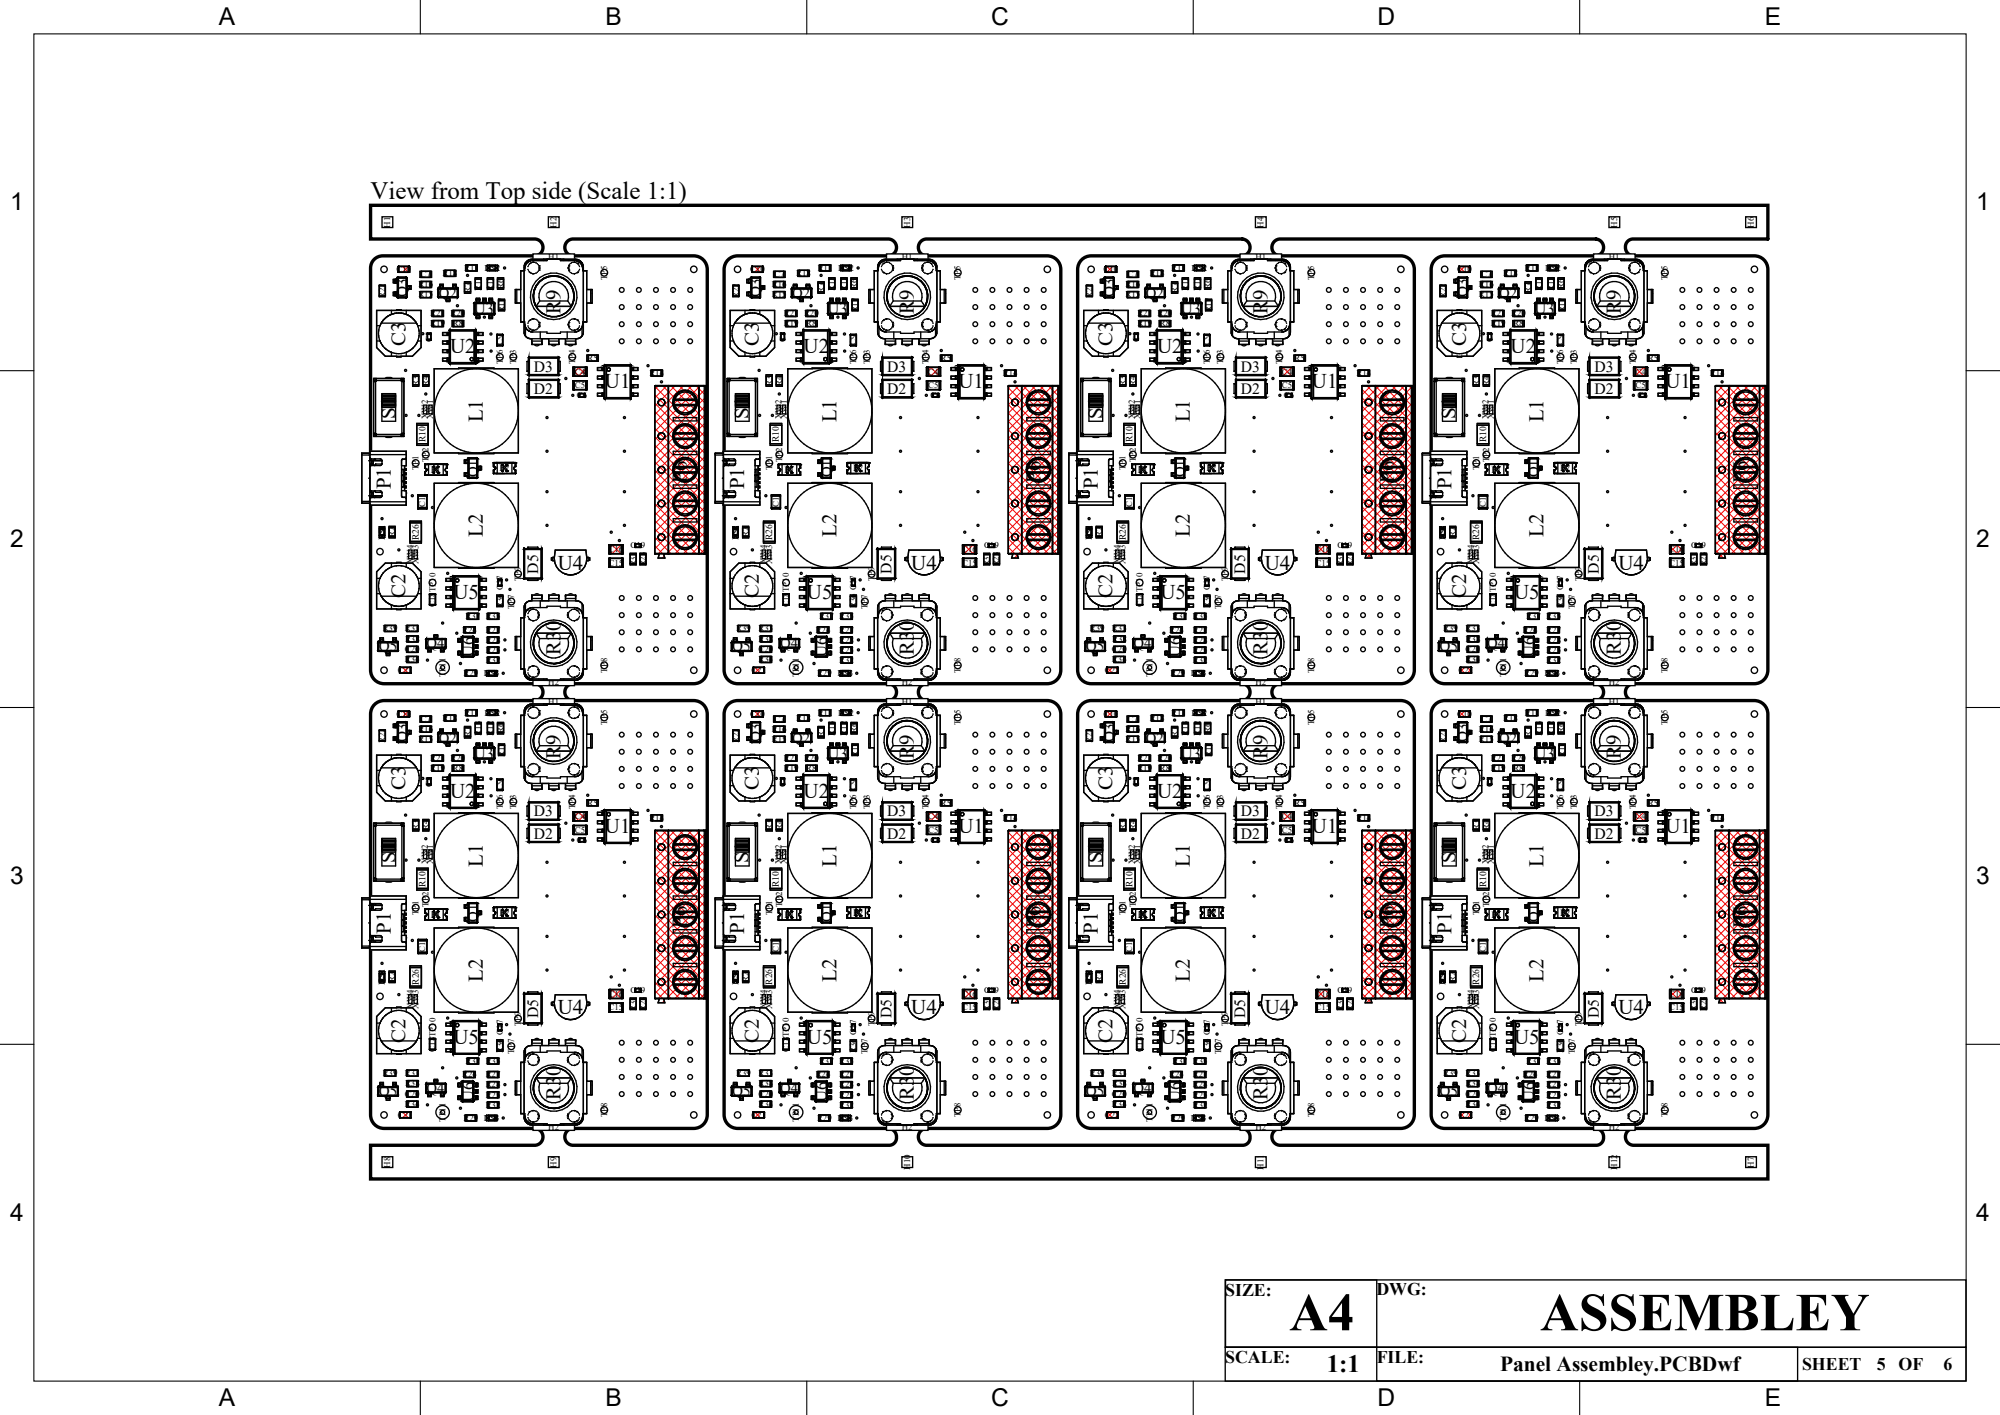
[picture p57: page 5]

View from Top side (Scale 1:1)

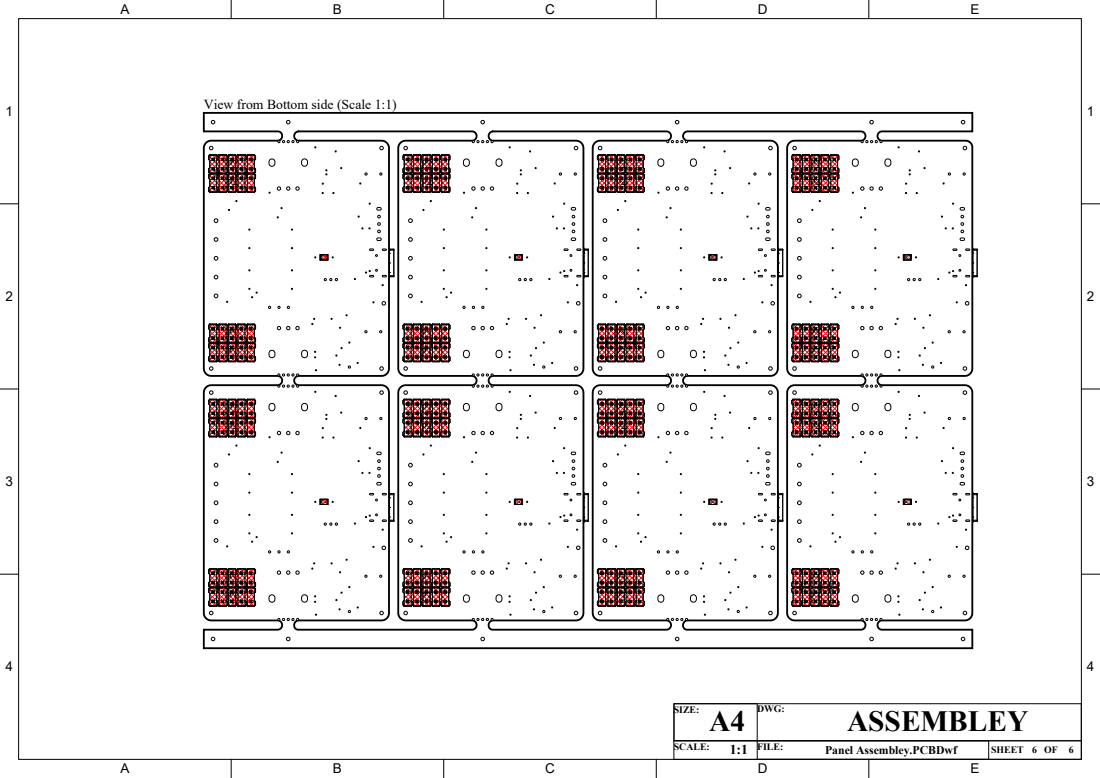
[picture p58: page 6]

View from Bottom side (Scale 1:1)

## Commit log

2021-04-09 Upload of Prototype Release
    This upload contains the released manufacturing files generated by Altium Designer for the initial prototype. The project may be fabricated and assembled by JLCPCB using the JLCPCB SMT Assembly varia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
    [Bill of Materials.csv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]
2021-04-09 Fixed file upload.
    [Bill of Materials.csv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]
2021-04-09 New Prototype Release
    Fixed a incorrect LCSC number for Q1.
    [Bill of Materials.csv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]
2022-03-30 Updated to Revision 4.3.1
    [Bill of Materials-SIO2MKR.csv, Bill of Materials.csv, Functional Diagram.SchDoc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]
